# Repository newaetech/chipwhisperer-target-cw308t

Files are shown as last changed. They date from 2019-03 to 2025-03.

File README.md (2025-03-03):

# ChipWhisperer CW308 Targets #



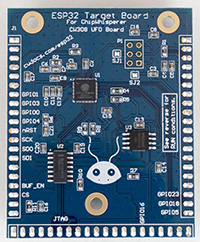
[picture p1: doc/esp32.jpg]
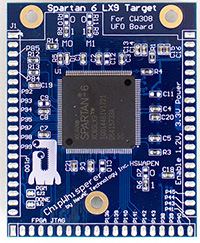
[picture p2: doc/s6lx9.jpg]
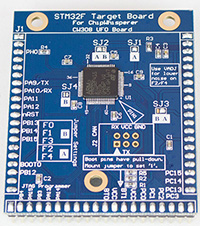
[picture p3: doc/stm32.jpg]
  

These are *targets* for the CW308 UFO Board. This repo contains gerbers, schematics, and source files (in Altium Designer format). Note **SOME BOARDS ARE UNTESTED**. All files are provided at your own risk. The CW308 UFO board is required for use (not part of this repo) as it supplies power, clock, programming headers etc:

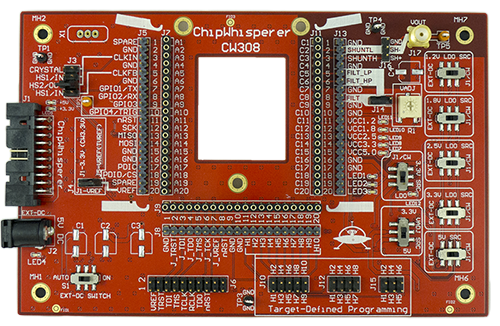
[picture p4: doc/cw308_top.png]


Many of these target boards (along with UFO baseboard) can be purchased assembled via Mouser Electronics. Note all targets are available however, so if you want some of the latest targets you may need to build one.

Most (all?) of these boards support the ChipWhisperer example applications. That means a basic HAL is provided in [chipwhisperer/firmware/mcu/hal](https://github.com/newaetech/chipwhisperer/tree/develop/firmware/mcu/hal) . Some of the more unique boards do not build as part of that system due to complexity of porting (i.e., ESP32).

## Documentation ##

The documentation in each directory (the markdown README.md file) is mirrored to the ChipWhisperer [main documentation page](https://chipwhisperer.readthedocs.io).
Some of the links in the markdown files here appear broken; they are written to
work for building the documentation site at
https://github.com/newaetech/chipwhisperer/tree/develop/docs, where this
repository is pulled in as a submodule.

## Using Boards ##

To use the boards, you will require the following at minimum:

* CW308 UFO Baseboard
* Analysis/injection device: either (1) ChipWhisperer-Lite Capture or ChipWhisperer-Pro, or (2) oscilloscope.

If NOT using ChipWhisperer-Lite/Pro which have built-in power supply, serial comms, and clock generator:

* USB-Serial adapter (3.3V)
* Crystal on UFO board (included w/ UFO board)
* 2.1mm DC power jack and 5V power supply

For most boards you will also require:
* External programming tool.

The STM32Fx boards, XMEGA, and AVR boards can all be programmed from the ChipWhisperer platform. All other boards will require an external programmer at this time.

### Suggested programmers ###

* For ARM targets anything with 20-pin JTAG header such as J-Link, OpenOCD, etc.
* For PowerPC targets a PEMicro USB Multilink
* For Tri-Core targets DAP miniWiggler V3
* For ESP32 you only need a USB-Serial cable
* Others (Si4010, D2000, etc) may have unique requirements.

## FAQs ##

**Q**: Do these boards work stand-alone?

**A**: No. These boards require a CW308 UFO Base-Board. In addition you may need an external programmer to load code on many of them.

--

**Q**: What's the difference between these and dev-boards?

**A**: These boards are purpose-built for side-channel analysis. As such they have a shunt resistor mounted, along with missing decoupling capacitors to allow clean power measurements. You can hack up dev-boards to achieve this, but these CW308T boards make it considerably easier to do so, along with high repeatability.

--

**Q:** Why are these boards so expensive when there is nothing on it? I can buy a dev-kit with JTAG and everything for the cost of some of these boards!

**A:** Dev-boards have low cost as are produced in huge quantity and minimal profit margin. Due to the unique nature of our boards we typically are producing QTY 25-200 per "run", and many of the ICs alone are rather expensive at that point. For example a STM32F407 @ Qty 40 is $12 USD, and the "discovery" board with that chip mounted is only $20!

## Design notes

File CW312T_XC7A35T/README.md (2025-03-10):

# CW312T-XC7A35

Xilinx Artix7 A35 Target for ChipWhisperer, with CW312 edge connector.

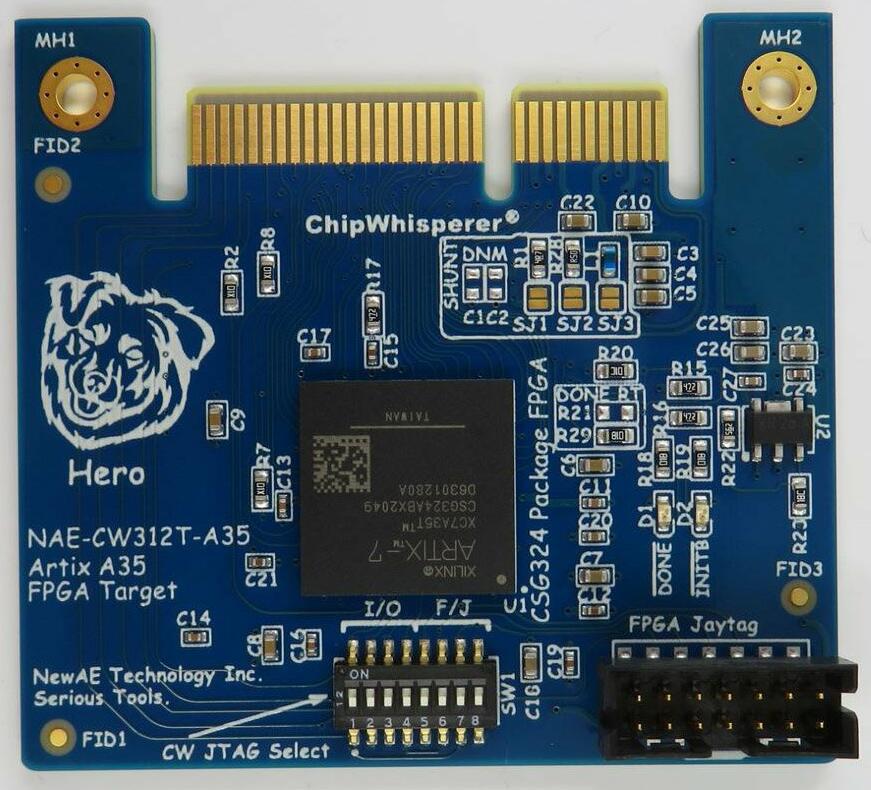
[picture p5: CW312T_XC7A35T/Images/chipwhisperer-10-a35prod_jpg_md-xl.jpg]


## JTAG Options
The target board has a Xilinx JTAG header (labeled "FPGA Jaytag" on the PCB)
which connects to the FPGA's JTAG port, for programming the FPGA via Xilinx
tools, or for using FPGA ILAs.

Additionally, the "CW JTAG Select" DIP switch provides some additional JTAG
routing options:
1. When switches 5-8 are "on", the JTAG header pins on the carrier CW313
   board (TDI, TDO, TMS, TCK) are routed to the FPGA's JTAG port.
2. When switches 1-4 are "on", the JTAG header pins on the carrier CW313
   board are routed to another set of FPGA pins (TDI, TDO, TMS, TCK to A11,
   C12, B11, B12 respectively), which allows connecting to e.g. a
   soft-core JTAG port.
Refer to the [schematic](#schematic) to see exactly how this is done.

## Shunt Selection
Because it's hard to have an optimal one-size-fits-all shunt for FPGA
targets, there are 3 shunts to choose from:

* 47 nH inductor

* 0.5 &Omega;

* 4.7 &Omega;

The active shunt is selected by a solder blob on SJ1, SJ2 or SJ3.

## Example Target Cores
The A35 target can run our example 
[AES](https://github.com/newaetech/chipwhisperer-jupyter/blob/master/demos/PA_HW_CW305_1-Attacking_AES_on_an_FPGA.ipynb), 
[pipelined AES](https://github.com/newaetech/chipwhisperer-jupyter/blob/master/demos/CW305_AES_pipelined.ipynb), and 
[ECC](https://github.com/newaetech/chipwhisperer-jupyter/tree/master/courses/sca204) 
cores. 

Pre-built bitfiles for all of these targets are included in the
ChipWhisperer repository, and can be explored via the notebooks (linked
above). To learn how to build these bitfiles yourself, head over to the
FPGA target area of the chipwhisperer repository
[here](https://github.com/newaetech/chipwhisperer/tree/develop/firmware/fpgas).

## Example Soft Cores
(ibex)=
### 1. Ibex
We also provide a bitfile for a pre-built 
[RISC-V Ibex core](https://github.com/lowRISC/ibex-demo-system).

To compile firmware for this target using our build infrastructure, set
`TARGET` to `CW312_IBEX`. This will pull in the 
[Ibex HAL](https://github.com/newaetech/chipwhisperer/tree/develop/firmware/mcu/hal/ibex).
Ensure you have a version of `riscv32-unknown-elf-gcc` [recommended by the
lowRISC project](https://github.com/lowRISC/lowrisc-toolchains/releases).
Then, compile target firmware 
[here](https://github.com/newaetech/chipwhisperer/tree/develop/firmware/mcu) 
as you would for any of our other targets.

Alternatively, you can also build target firmware from the 
[Ibex demo repository](https://github.com/lowRISC/ibex-demo-system#building-software)
following the Ibex methodology; there you will find our `simpleserial-aes` and
`basic-passwdcheck` firmware as examples.

After loading the FPGA bitfile (which can be done via the
[Setup\_Ibex.ipynb script](https://github.com/newaetech/chipwhisperer-jupyter/blob/master/Setup_Scripts/Setup_Ibex.ipynb), 
if using our pre-built bitfile), you'll need to program your target firmware
separately, using an external JTAG programmer connected to the A35's FPGA
JTAG port, *not the soft-core port* (e.g. connect your programmer
TDI/TDO/TCK/TMS to those header pins on the CW313 board, set DIP switches
5-8 to "on" on the A35 target board, and disconnect any other JTAG
programmer from the A35's "jaytag" header).

To program the firmware onto the FPGA soft-core, refer to the instructions
[here](https://github.com/lowRISC/ibex-demo-system#loading-an-application-to-the-programmed-fpga).
Those instructions run out-of-the-box on their default Arty FPGA platform;
you will likely need to modify their `load_demo_system.sh` script for your
own JTAG programmer.

Alternatively, you can avoid the firmware programming step by embedding your
target firmware into your FPGA bitfile; however, this requires you to build
the FPGA bitfile yourself (and re-building the bitfile every time you wish
to modify the firmware).

The pre-built Ibex core's UART link operates at 115200 baud when clocked at
100 MHz and is suitable for use with SimpleSerial v1 (the Ibex design
includes a PLL which expects a 100 MHz input clock; you can lower the clock
frequency and scale the baudrate accordingly, but only to a certain point
because the PLL will stop functioning correctly if the input clock frequency
is too far from 100 MHz).

### 2. Arm DesignStart
Look to our 
[Arm DesignStart repository](https://github.com/newaetech/CW305-Arm-DesignStart) 
for instructions on building and using a soft-core Arm Cortex target.

## Programming
The FPGA can be programmed with a Xilinx platform cable (or equivalent)
connected to the "Jaytag" port, as explained [above](#jtag-options).

It can also be programmed with a ChipWhisperer-Husky as follows:

```Python
import chipwhiserer as cw
scope = cw.scope()
from chipwhisperer.hardware.naeusb.programmer_targetfpga import CW312T_XC7A35T
fpga = CW312T_XC7A35T(scope)
fpga.program(<path-to-bitfile>, sck_speed=10e6)
```

When using our [example target cores and notebooks](#example-target-cores),
the notebooks automatically handle programming the correct bitfile for you
(via Husky).

## Schematic

The schematic is available
[here](https://github.com/newaetech/chipwhisperer-target-cw308t/blob/main/CW312T_XC7A35T/NAE-CW312T0XC7A35-04.PDF).

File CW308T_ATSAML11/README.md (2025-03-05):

# CW308T-ATSAML11

This board supports the Microchip ATSAML11 microcontroller.

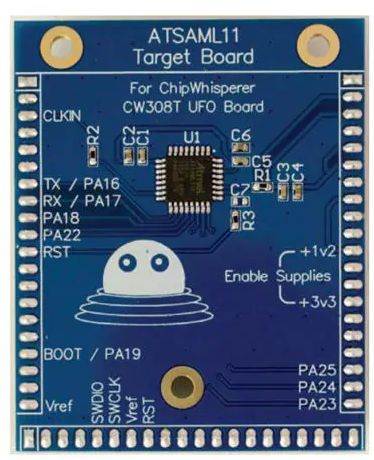
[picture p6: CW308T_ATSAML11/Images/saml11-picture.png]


## Specifications

| Feature | Notes/Range |
|---|---|
| Target Device | ATSAML11E16A |
| Target Architecture | Arm Cortex-M23 |
| Vcc | 1.2V |
| Programming | Serial Bootloader, SWD |
| Hardware Crypto | Accelerator |
| Availability | Standalone |
| Status | Released |
| Shunt | 22Ω |

Available from [Mouser](https://www.mouser.com/ProductDetail/NewAE/NAE-CW308T-ATSAML11?qs=PzGy0jfpSMuVApvEE0Yklw%3D%3D).

---

## Power Supply

The core of the SAML11 chip runs from a 1.2v supply. This is supplied
through the CW308T 1.2v regulator. The I/O busses are supplied with
3.3v.

---

## Security Features

The SAML11 platform integrates many advanced security features
including:

  - Up to four tamper pins for static and dynamic intrusion detections
  - Silent flash access for side channel attack resistance
  - Data scrambling with user-defined keys for both Flash and RAM
  - A True Random Number Generator

Since it's a Cortex-M23 core, it's also got Arm TrustZone-M.

For a full list of security features see the product family data
sheet[^1].

---

## Programming

The SAML10/11 family implements a serial bootloader. Usage of this
bootloader is not detailed in the data sheet, for usage information see
Microchip Application note AN2699[^2]. This bootloader doesn't have a
driver in ChipWhisperer, but one could be added.

Serial Wire Debug (SWD) is also supported for programming and debugging
applications.

---

## Schematic and Layout

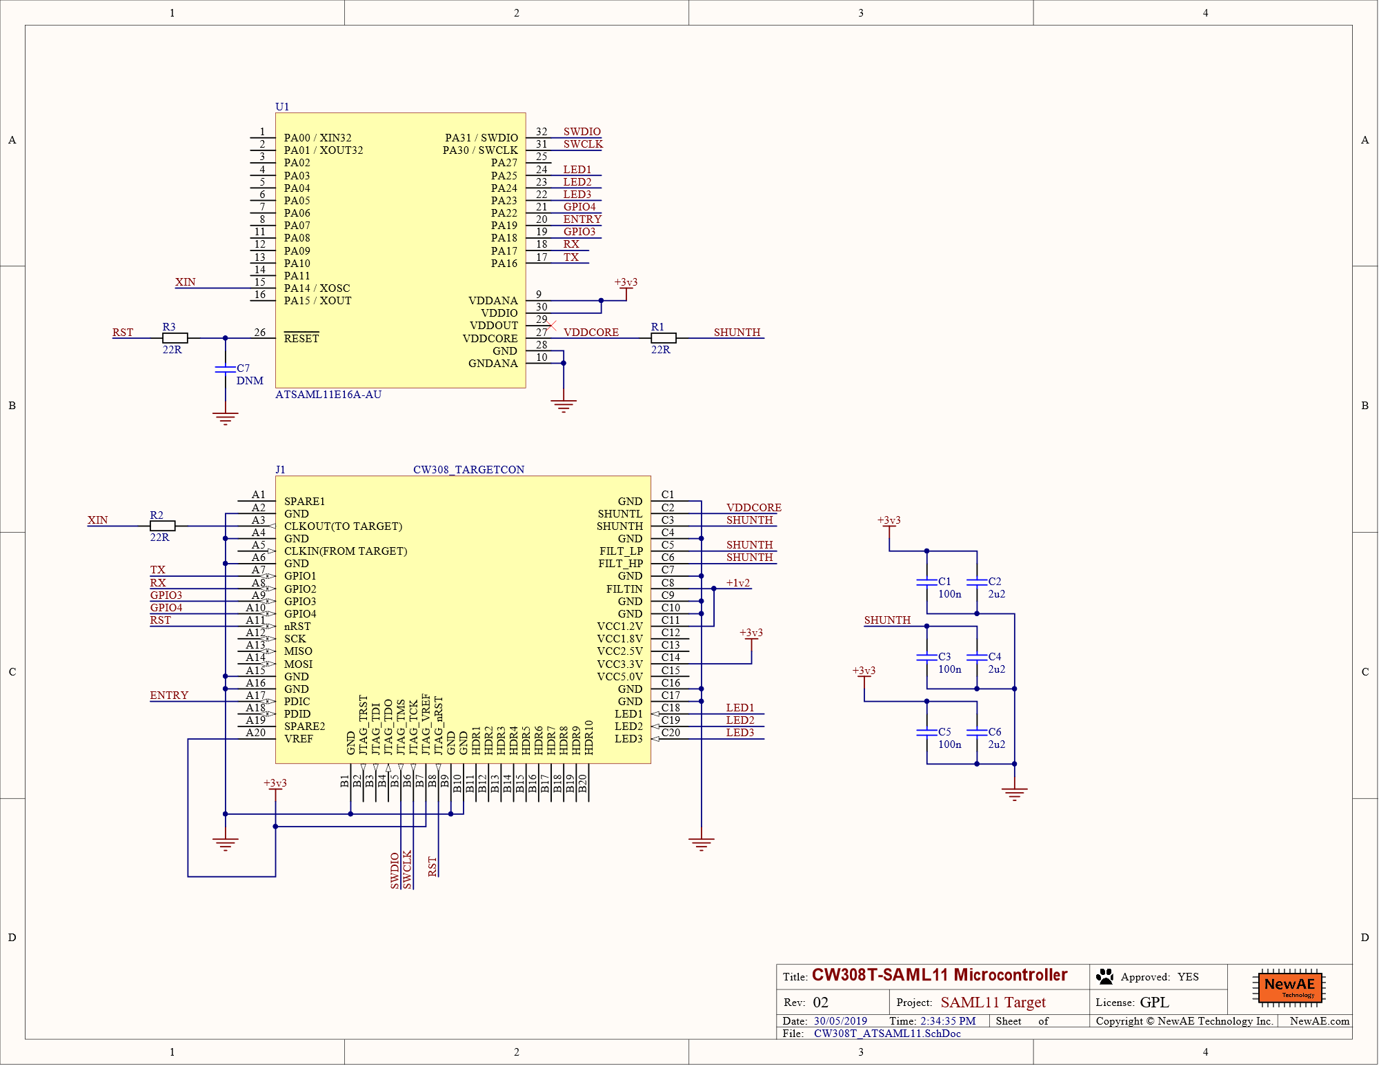
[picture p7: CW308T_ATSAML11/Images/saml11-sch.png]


[^1]:  <https://ww1.microchip.com/downloads/aemDocuments/documents/MCU32/ProductDocuments/DataSheets/SAM-L10-L11-Family-Data-Sheet-DS60001513.pdf>
[^2]:  <https://ww1.microchip.com/downloads/aemDocuments/documents/OTH/ApplicationNotes/ApplicationNotes/AN2699-UART-Bootloader-for-SAM-L10-L11-DS00002699B.pdf>

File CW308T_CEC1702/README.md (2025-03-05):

# CW308T-CEC1702

The CEC1702 is an embedded controller with strong cryptographic support,
customized for Internet of Things (IOT) platforms. The chip implements a
highly-configurable, mixed signal, advanced I/O controller architecture.
The device incorporates a 32-bit ARM Cortex M4F Microcontroller core
with closely-coupled SRAM for code and data. A secure bootloader is
used to download the custom firmware image from the system’s shared SPI
Flash device, thereby allowing system designers to customize the
device’s behavior[^1].

The CW308T-CEC1702 incorporates the main chip with a 16MB SPI flash chip
and a bi-directional SPI Buffer. The target board has standard power
monitoring, UART serial, and clock In/Out compatibility with the CW308.
JTAG pins and many GPIO pins are also exposed for prototyping and
testing use.

This device is interesting in that it has a lot of hardware crypto and
security functionality.

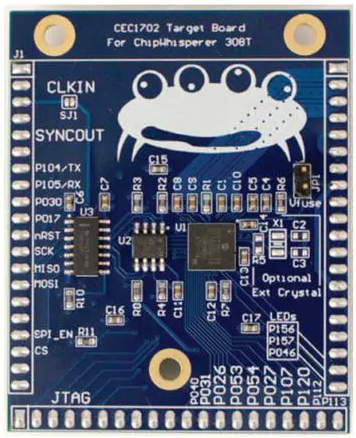
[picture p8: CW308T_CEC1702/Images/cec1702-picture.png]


---

## Specifications

| Feature | Notes/Range |
|---|---|
| Target Device | MCHP CEC1702 |
| Target Architecture | Arm Cortex M4F |
| Vcc | 3.3V |
| Programming | SPI Flash, JTAG (SRAM only) |
| Hardware Crypto | Yes |
| Availability | Standalone |
| Status | Released |
| Shunt | 10Ω |

Available from [Mouser](https://www.mouser.com/ProductDetail/NewAE/NAE-CW308T-CEC1702?qs=PzGy0jfpSMvD%2FsklzPsozg%3D%3D)

## I/O Connections

| **CW308 Pin** | **CEC1702 Pin** | **Function** |
| --- | --- | --- |
| GPIO1 | P104 (TXD0) | Serial OUTPUT from CEC1702 |
| GPIO2 | P105 (RXD0) | Serial INPUT to CEC1702 |
| GPIO3 | P030 | GPIO |
| GPIO4 | P017 | Trigger pin |
| CLKIN | XTAL2 | Optional CLKIN |
| CLKFB | P002 (PWM5) | Can output 12MHz PWM on this pin. Useful for synchronizing to internal oscillator |
| J\_TRST | JTAG\_RST | JTAG Reset |
| J\_TDI | JTAG\_TDI | JTAG TDI |
| J\_TDO | JTAG\_TDO | JTAG TDO |
| J\_TMS | JTAG\_TMS | JTAG TMS |
| J\_TCK | JTAG\_CLK | JTAG Clock |
| LED1 | P156 | GPIO, Breathing LED0 |
| LED2 | P157 | GPIO, Breathing LED1 |
| LED3 | PA7 | GPIO, LED |
| PDIC | | SPI buffer output enable, drive high to enable SPI programming and sniffing |
| PDID/CS | QSPI0\_CS | SPI chip select for SPI flash chip |
| H1 | P040 | GPIO |
| H2 | P031 | GPIO |
| H3 | P026 | GPIO |
| H4 | P053 | GPIO |
| H5 | P054 | GPIO |
| H6 | P027 | GPIO |
| H7 | P107 | GPIO |
| H8 | P120 | GPIO |
| H9 | P112 | GPIO |
| H10 | P113 | GPIO |

---

## Hardware Cryptography

### **Multi-purpose AES Cryptographic Engine**

\- Hardware support for ECB, CTR, CBC, and OFB AES modes

\- Support for 128-bit, 192-bit and 256-bit key length

\- DMA interface to SRAM, shared with Hash engine

### **Cryptographic Hash Engine**

\- Support for SHA-1, SHA-256, SHA-512

\- DMA interface to SRAM, shared with AES engine

### **Public Key Cryptographic Engine**

\- Hardware support for RSA and Elliptic Curve public key algorithms

\- RSA keys length from 1024 to 4096 bits

\- ECC Prime Field and Binary Field keys up to 640 bits

\- Microcoded support for standard public key algorithms

### **Other Cryptographic Features**

\- True Random Number Generator

\- 1 Kbit FIFO

\- Monotonic Counter

---

## Firmware

The firmware provided with Chipwhisperer (or its own repo) is designed
to work with the [MikroC PRO for ARM
IDE](http://www.mikroe.com/mikroc/arm). This IDE supports the many
peripherals of the CEC1702, including the hardware security features and
comes with extensive libraries and example code. The board layout has
been designed to be compatible with many of the provided examples, while
some others can be easily modified to work with the CW308T-CEC1702.
After the binaries have been created, they can either be loaded into SPI
Flash or directly into RAM via JTAG.

### **Creating and Modifying Examples**

The following notes may prove useful when using mikroC PRO examples or
creating your own:

  - Any example which uses UART1 needs to be changed to use UART0 by
    changing the UART1\_\* functions to UART0\_\*.
  - The plain text and encrypted text buffers need to be 16 byte aligned
    for the CEC1702's DMA to function properly. If the aes\_crypt() call
    fails or the encryption never completes, this may be the cause. See
    simpleserial\_base.c or mikroC PRO's AES examples for examples of
    this.
  - All variable declarations need to be done at the beginning of
    functions, before any variables are modified or functions are
    called.
  - The mikroC PRO compiler may have strange sizes for integer
    constants, meaning changing 4 8 bit numbers into a 32 bit number via
    bitshifts may not work as intended. Instead, using memcpy() may
    prove easier and more reliable.
  - When using mikroC PRO's "Clean Project Folder", ensure that .mcpar,
    .c, .h, and .xml files are not selected, as this will cause the
    source/project/Flash Center
  - The port base for use with the GPIO library is actually
    GPIO\_PORT\_xxx\_xxx, not \_GPIO\_PORT\_xxx\_xxx. Additionally, this
    is not a pointer, meaning the address of this variable needs to be
    passed to the gpio functions
  - There are no GPIO library functions to write or read from pins.
    Instead, use GPIO\_OUTPUT\_xxx\_xxx.Bn/GPIO\_INPUT\_xxx\_xxx.Bn for
    bit n of pin range xxx-xxx.

### **Compilation Settings**

**Project \> Edit Project**

Select CEC1702 in the MCU Name dropbox, change the MCU Clock Frequency
to 48MHz.

If you want to program and run off of the SPI flash, additional
configuration is needed:

**\> General Output Settings ...**

Make sure _**Generate BIN image file**_ is checked. Press OK on the
window and the previous edit project window.

**Build \> Build**

The messages dialog should indicate a successful build, and the image
binary (PROJECTNAME\_img.bin) and hex (PROJECTNAME.hex) can now be found
in the project output folder. To confirm correct build settings, check
the image binary using your SPI flash software or a HEX editor. The
image binary should begin with the 8 bytes **01 00 00 3E 01 00 00 3E**
at offset 000000, and the rest of the program should begin at offset 000100.

---

## Programming the Device

The CEC1702 supports loading code in two ways: from external flash
memory into RAM and directly into RAM over JTAG.

### **Programming the SPI Flash**

The [SST26VF016B](https://ww1.microchip.com/downloads/en/DeviceDoc/20005262D.pdf) flash chip on the target board can be programmed by an SPI programmer
attached to the SPI pins of the CW308. To program the chip, the nRST
chip must be pulled to ground by holding the nRST button down or by
connecting a jumper to J8 on the CW308. Additionally, the PDIC pin must
be driven high during the programming process to enable communication
through a buffer chip.

The [SST26VF016B](https://ww1.microchip.com/downloads/en/DeviceDoc/20005262D.pdf) flash chip uses global block protection that must be disabled before
every write operation. This is done by sending the command code **98**
to the chip before erasing or writing to the device. This can be done by
configuring a custom transaction in your flash programming software.
Below is a table of useful information for configuring your programming
software. The Parameters listed here have been tested with the Total
Phase Flash Center software and the Aardvark I<sup>2</sup>C/SPI Host
adapter. Additionally, a [Total Phase Flash Center](https://www.totalphase.com/products/flash-center/) script is
provided with the firmware for additional reference. See the
[SST26VF016B data
sheet](https://ww1.microchip.com/downloads/en/DeviceDoc/20005262D.pdf)
and the manual for your SPI flash program for more details.

| **Parameter** | **Value** |
| --- | --- |
| deviceName | SST26VF016B |
| deviceDescription | SST SST26VF016B 16 Megabyte SPI Flash |
| capacity | 16\*1024\*1024 |
| maxBitrate | 8\*1000 |
| addressWidth | 3 |
| eraseInstruction | 0x20 |
| eraseSize | 4\*1024 |
| eraseTime | 18000 |
| writeSize | 256 |
| writeTime | 64 |
| writeAutoAddressIncrementSize | 2 |
| writeAutoAddressIncrementTime | 10 |
| readDeviceIdInstruction | 0x9F |
| expectedDeviceId | \\xbf\\x26\\x41 |
| readInstruction | 0x03 |
| eraseAllInstruction | 0xC7 |
| eraseAllTime | 16000 |
| userTransaction1 | \\x98 |
| userTransaction1Time | 10000 |
| userTransaction1WriteEnable | false |

### **Programming over JTAG/SWD**

In addition to the SPI flash method, the CEC1702 can be temporarily
(until power off) programmed using a JTAG debugger. This has been tested
using Ozone V2.56d with a j-Trace Pro from Segger. The mikroC PRO IDE
also supports programming and debugging using the Segger.

Note that the CEC1702 only supports JTAG when the Debug Select bit (Byte
482 Bit\[6\]) of EFUSE is 0 and SWD when the Debug Select bit is 1. If
one does not work, try the other.

Load the image binary on to the flash chip and verify that the write was
performed. If verification fails, ensure the nRST pin was held low for
the entirety of the erase/write/verify cycle. If verification still
fails, refer to the data sheet and your programming software manual to
make sure the necessary command codes were sent in the appropriate
order.

### **Running the Program**

If you programmed the device via SPI flash, remove the nRST
jumper/release the nRST button and disconnect the 3.3V source from PDIC.
If you loaded your code from JTAG, hit go on your debugging software.

---

## Performing CPA Attacks

The CEC1702 has no option to run off on an external clock. To make CPA
attacks easier, a 12MHz PWM signal is generated on the CLKOUT pin. This
can be used by putting a jumper on the lower HS1/IN pins on J3 and
running the ChipWhisperer off of the ExtClk.

---

## ATE and EFUSE

The CEC1702 ships in ATE mode suppliers, which prevents booting off of
SPI flash and seems to mess with the UART baud rate (57600 baud
corresponded to 32000 baud). Note the CW308T-CEC1702 target boards have
this disabled as part of the production process / test procedure.

The device can be changed into normal mode by setting Byte 35 Bit\[7\]
of the EFUSE memory. This can be done via an external SPI flash such as
the mikroProg, or by loading a program that modifies the bits via JTAG.
For additional information, see the CEC1702 datasheet and errata. Before
modifying the EFUSE, keep the following in mind:

  - EFUSE bits are one time programmable (OTP) to 1. This means there's
    no way to set the bits back to 0 once they are set to 1.
  - To modify the EFUSE, VREF must be set to between 1.52V and 1.6V.
  - Make sure that FSOURCE\_EN\_READ and FSOURCE\_EN\_PRGM are never set
    to 1 at the same time, as this will short ground and power.
  - Note that both the EFUSE instructions in the CEC1702 datasheet and
    mikroC PRO's EFUSE program rely on VREF being set to ground while
    FSOURCE\_EN\_READ and FSOURCE\_EN\_PRGM are being switched. Instead,
    to modify the EFUSE, set both to 0, wait for the registers to be
    set, then set the appropriate bit.
  - Some additional features of the EFUSE include setting keys for flash
    decryption and authentication by the bootloader.

You can see an example program that works with the CW308T-CEC1702 device
at
[1](https://github.com/newaetech/chipwhisperer-target-cec1702)(https://github.com/newaetech/chipwhisperer-target-cec1702).
**NOTE: This firmware requires that integers are 32bits. Before building
this project, go to Project\>Edit Project and change Data Type Size to
"other (int 4 byte)"**

To use E-FUSE with the CW308T, you will need to use a jumper wire. To do
this:

  - Using a screwdriver, adjust VADJ trimmer to output 1.60V. Note you
    might need to switch the V-ADJ source voltage.
  - Jumper the VADJ output to the VFUSE header pin.

---

## Schematics

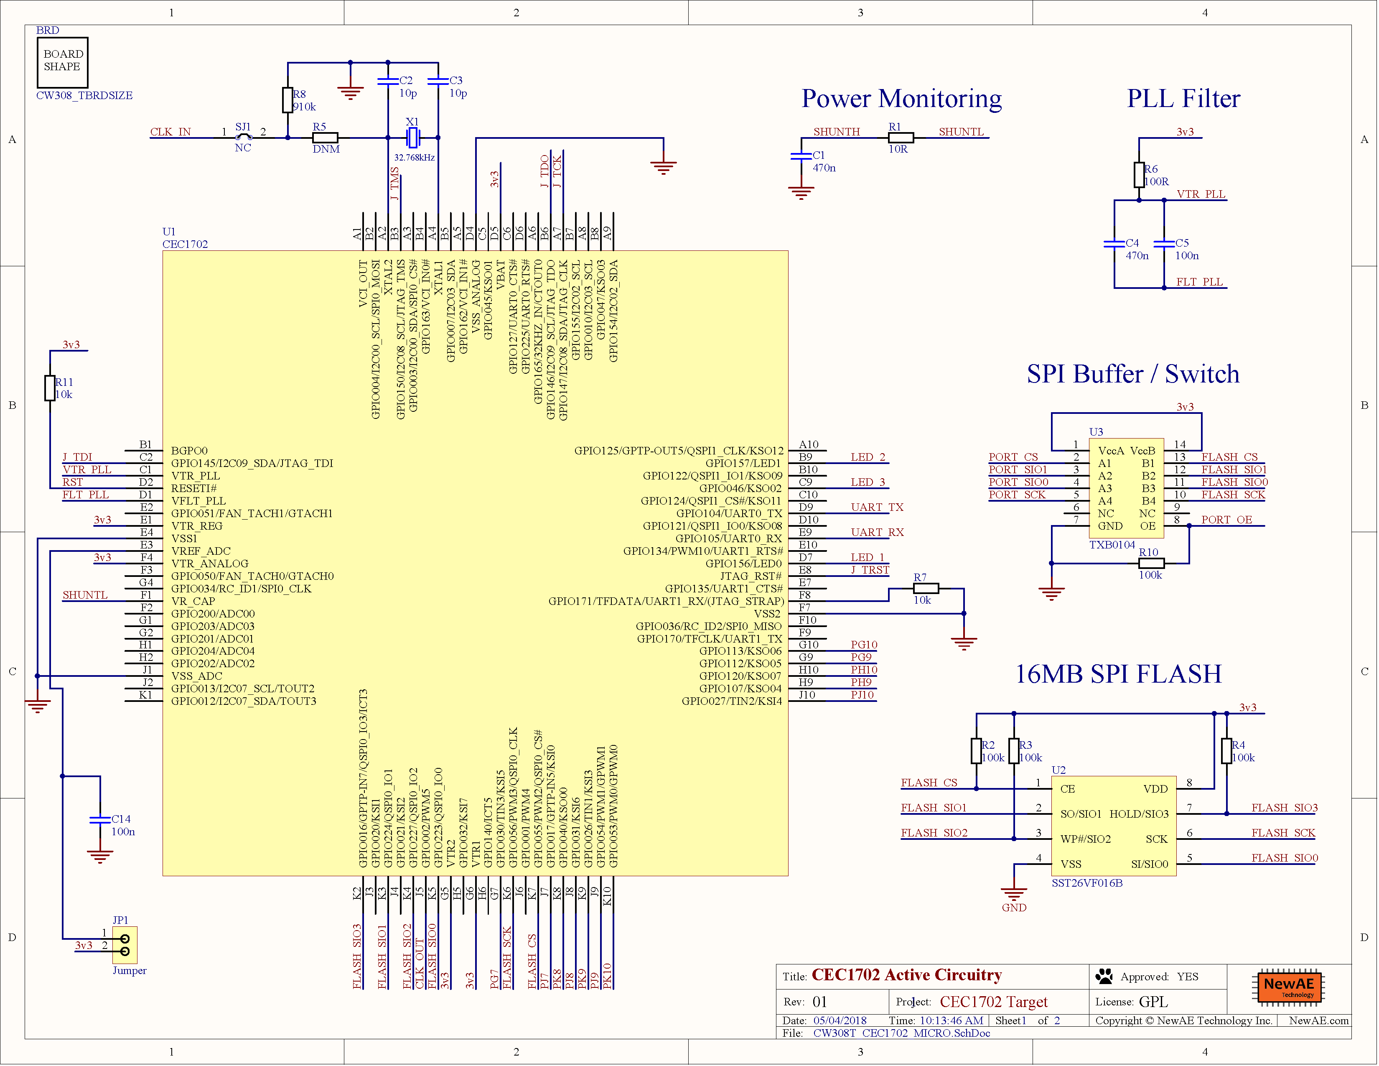
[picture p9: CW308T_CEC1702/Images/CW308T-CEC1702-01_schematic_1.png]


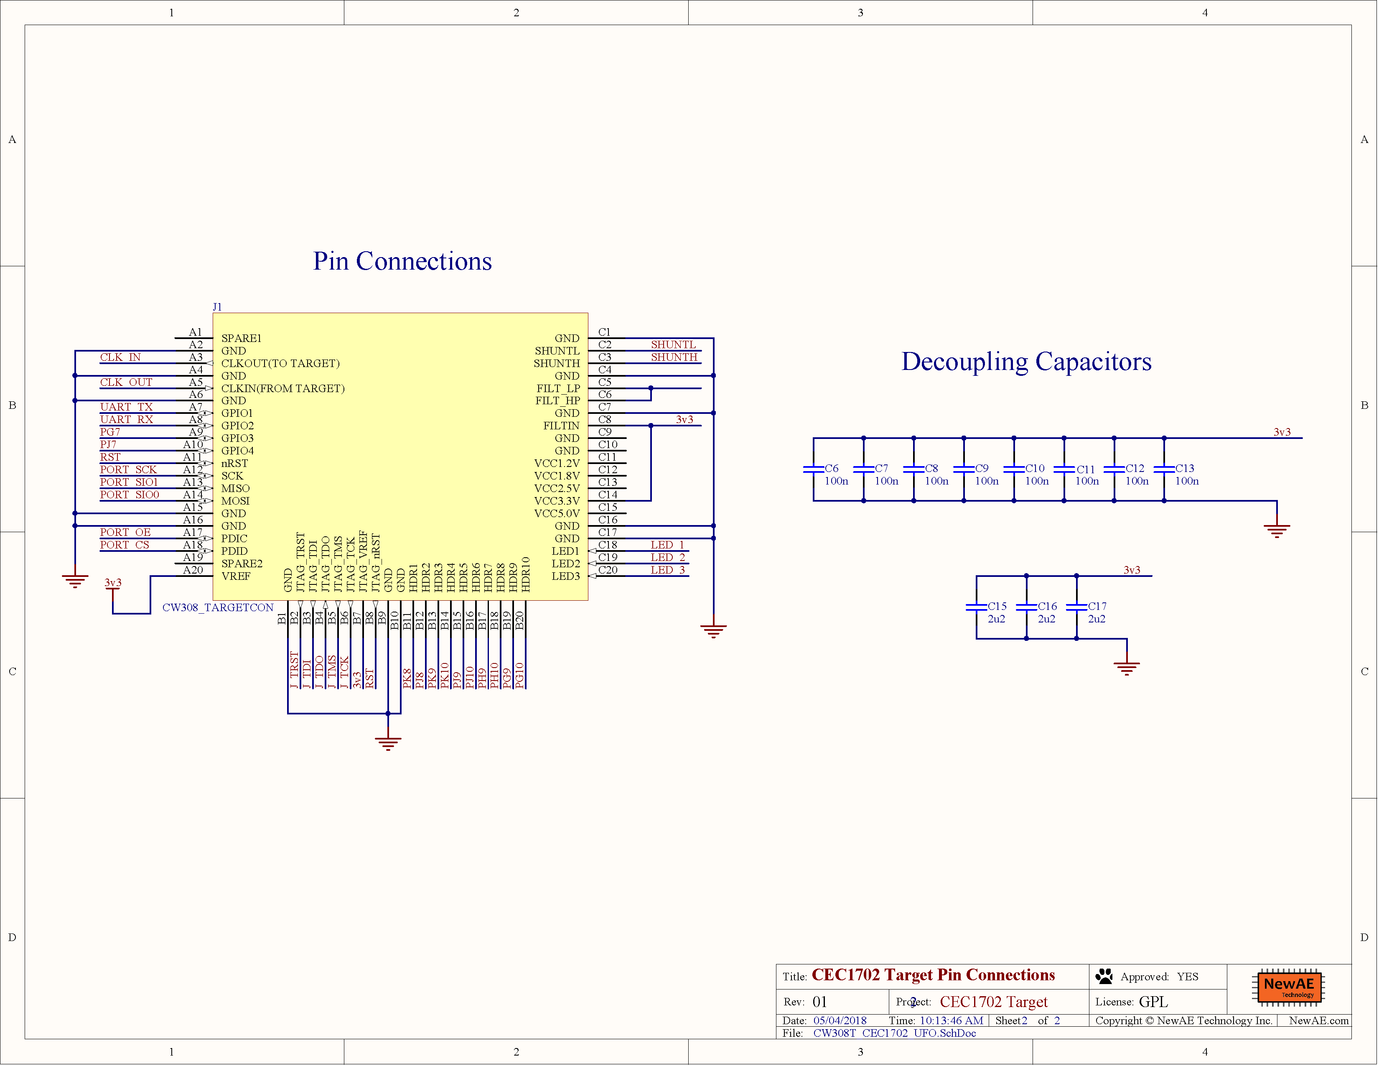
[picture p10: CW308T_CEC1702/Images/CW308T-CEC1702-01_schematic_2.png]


---

## Useful Links

  - [Microchip documents](https://www.microchip.com/en-us/product/cec1702)
  - [Aardvark I2C/SPI
    Programmer](https://www.totalphase.com/products/aardvark-i2cspi/)
  - [mikroC PRO for ARM IDE](http://www.mikroe.com/mikroc/arm)
  - [SST26VF016B Flash Datasheet](https://ww1.microchip.com/downloads/en/DeviceDoc/20005262D.pdf)

[^1]: <http://ww1.microchip.com/downloads/en/DeviceDoc/00002207B.pdf>

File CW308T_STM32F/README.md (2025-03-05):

# CW308T-STM32F

The CW308-STM32F board is the perfect target for testing fault injection against TQFP-64 STM32F/STM32L
microcontrollers. Thanks to pin compatibility (mostly) between various devices, this single board
supports multiple STM32F/STM32L microcontrollers.

These boards are also available complete with different STM32 devices

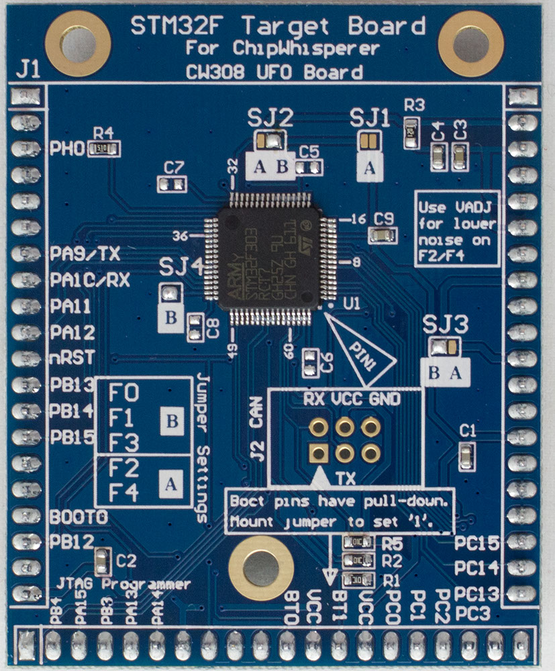
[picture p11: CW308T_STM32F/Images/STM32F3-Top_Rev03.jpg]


## Specifications

| Feature | Notes/Range |
|---|---|
| Target Device | STM32F |
| Target Architecture | Arm Cortex M0, M3, M4 |
| Hardware Crypto | Possible |
| Programmer | STM32F Serial Bootloader, JTAG, SWD |
| Availability | Starter kits, Standalone |
| Status | Released |

* STM32F0: available from [Mouser](https://www.mouser.com/ProductDetail/NewAE/NAE-CW308T-STM32F0?qs=r5DSvlrkXmIzFRGmD1EBXw%3D%3D) and the [NewAE Store](https://store.newae.com/stm32f0-target-for-cw308-arm-cortex-m0-128kb-flash-8kb-sram/)
* STM32F1: available from [Mouser](https://www.mouser.com/ProductDetail/NewAE/NAE-CW308T-STM32F1?qs=r5DSvlrkXmJcYbIax%2Fpjxw%3D%3D) and the [NewAE Store](https://store.newae.com/stm32f1-target-for-cw308-arm-cortex-m3-128kb-flash-8kb-sram/)
* STM32F2 w/Hardware Crypto: available from [Mouser](https://www.mouser.com/ProductDetail/NewAE/NAE-CW308T-STM32F2HWC?qs=r5DSvlrkXmJrfkJWQlIRng%3D%3D)
* STM32F3: available from [Mouser](https://www.mouser.com/ProductDetail/NewAE/NAE-CW308T-STM32F3?qs=r5DSvlrkXmKbi9gG3XxX8g%3D%3D) and the [NewAE Store](https://store.newae.com/stm32f3-target-for-cw308-arm-cortex-m4-256kb-flash-40kb-sram/)
    * Also available in a bundle with the [CANoodler](../../Tools/CANoodler.md) from [Mouser](https://www.mouser.com/ProductDetail/NewAE/NAE-CW308T-STM32F3AUTO?qs=r5DSvlrkXmJPqn%252BacawA8Q%3D%3D) and the [NewAE Store](https://store.newae.com/stm32f3-target-for-cw308-automotive-bundle-w-canoodler/)
* STM32F4 (no hardware crypto): available from [Mouser](https://www.mouser.com/ProductDetail/NewAE/NAE-CW308T-STM32F4?qs=r5DSvlrkXmKQ5HF2DzuSkA%3D%3D) and the [NewAE Store](https://store.newae.com/stm32f4-target-for-cw308-arm-cortex-m4-1mb-flash-192kb-sram/)
* STM32F4 w/Hardware Crypto: available from [Mouser](https://www.mouser.com/ProductDetail/NewAE/NAE-CW308T-STM32F4HWC?qs=r5DSvlrkXmLrgVVFt%252BpyiQ%3D%3D)
* STM32L4 w/Hardware Crypto: available from [Mouser](https://www.mouser.com/ProductDetail/NewAE/NAE-CW308T-STM32L4?qs=OlC7AqGiEDlCVULataTd0w%3D%3D)

* The blank PCB is also available from [Mouser](https://www.mouser.com/ProductDetail/NewAE/NPCB-CW308T-STM32F-04?qs=r5DSvlrkXmKb3e62axJWHA%3D%3D) and the [NewAE Store](https://store.newae.com/blank-pcb-stm32fx-cw308-target/)

---

## Supported Devices

The STM32F board supports several STM32F devices in the TQFP-64 package.
Various solder jumpers need to bet set to either the "A" or "B" position
to select appropriate VCC supply for the different series. The following
table summarizes examples of suitable devices:

| **STM32F Series** | **Package** | **Device** | **Hardware AES** | **Tested** | **Jumper** | **Flash** | **SRAM**  | **NAE P/N** |
| --- | --- | --- | --- | --- | --- | ----- | ----- | --- |
| F0 | TQFP-64 | STM32F071RBT6  | No | Yes | B | 128KB | 16KB  | NAE-CW308T-STM32F0 |
| F1 | TQFP-64 | STM32F100RBT6B | No | Yes | B | 128KB | 8KB | NAE-CW308T-STM32F1 |
| F2 | TQFP-64 | STM32F215RET6  | Yes | Yes | A | 512KB | 132KB | NAE-CW308T-STM32F2HWC |
| F3 | TQFP-64 | STM32F303RCT7  | No | Yes | B | 256KB | 40KB  | NAE-CW308T-STM32F3 |
| F4 | TQFP-64 | STM32F415RGT6  | Yes | Yes | A | 1MB | 192KB | NAE-CW308T-STM32F4HWC |
| F4 | TQFP-64 | STM32F405RGT6  | No | Yes | A | 1MB | 192KB | NAE-CW308T-STM32F4 |
| L4 | TQFP-64 | STM32L443RCT6  | Yes | Yes | B | 256KB | 64KB  | NAE-CW308T-STM32L4 (this version has hardware crypto) |
| L5 | TQFP-64 | STM32L562RET6  | Yes | Yes | B | 512KB | 256KB | NAE-CW308T-STM32L5HWC |

### **VCC-Int Supply**

Several devices (F2, F4) have internal core voltage regulators. By
default the CW308 board attempts to provide power for these pins, but
the voltage may not be high enough to cause the internal regulator to
disable itself. In this case you can use the VADJ regulator to ensure
the internal regulator is disabled. See 
[Targets with Internal Regulators](../../cw_tips_tricks/advanced_usage/regulators.md)
for details.

### **Pin-outs across TQFP Devices**

The following shows differences in pinouts between three groups of
devices. The left-most is the STM32F051RB, which uses the same 3.3V
VCORE as the STM32F1/F3. It has fewer VCC pins, so the I/O occupying
that are VCC/GND pins on the STM32F1 (such as PF6/PF7) are tied to
GND/VCC. The right-most part is the pinout of the STM32F2/F4. It has an
internal regulator, where the VCAP pins are the output of this regulator
(and input to the internal core logic).

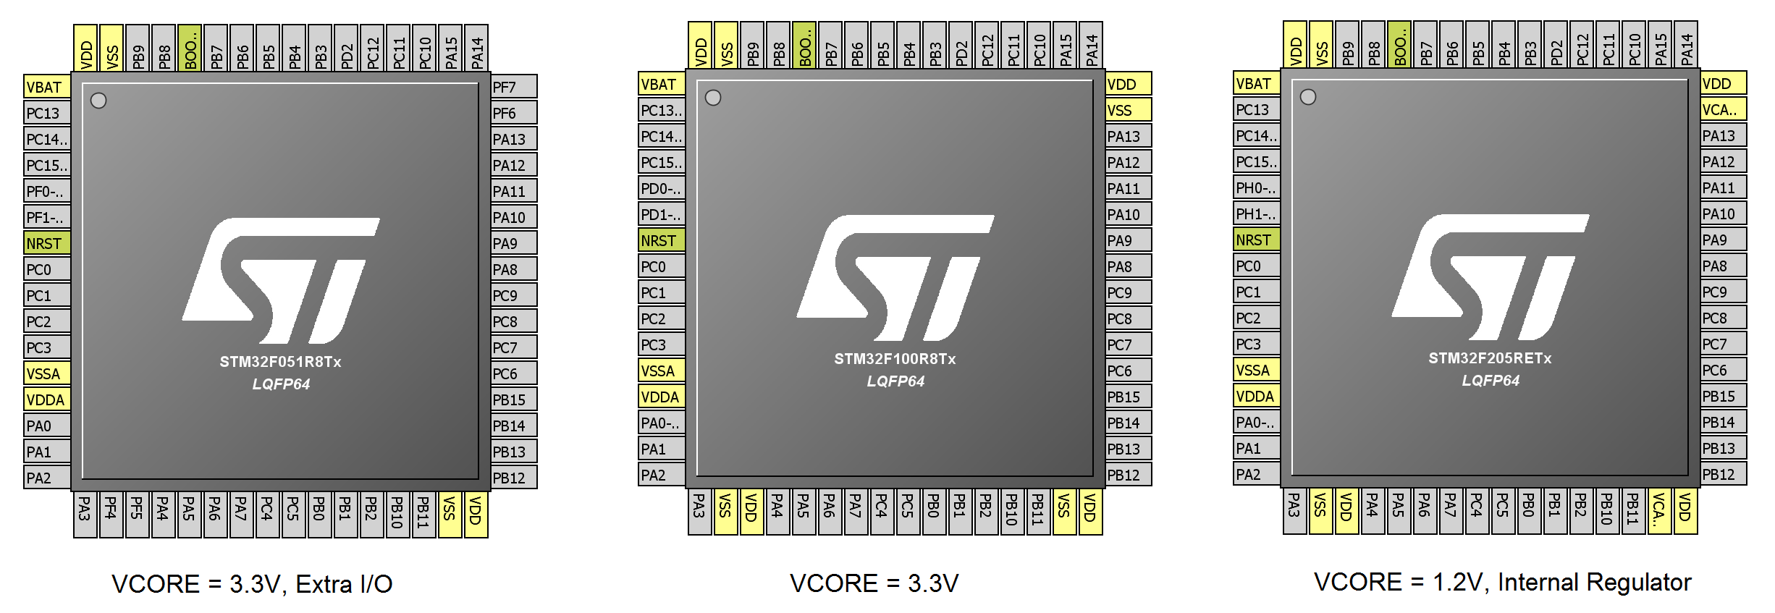
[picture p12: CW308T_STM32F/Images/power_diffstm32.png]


Note for the devices with a 3.3V VCORE, you should not mount decoupling
capacitors C5/C6/C7/C8. You will still get some leakage with those
capacitors mounted, but a stronger signal is present without them.

---

## Hardware AES

The STM32F21x, and STM32F41x/43x have hardware crypto modules (AES, DES,
TDES) along with hardware hash (SHA1, MD5). Hardware crypto for the
STM32F4 has been integrated into the Hal build system on the develop
branch. To use the hardware crypto, call HW_AES128_Init() at the
beginning of your program. You can update the key with
HW_AES128_LoadKey(), encrypt plaintext with HW_AES128_Enc(), and
decrypt data with HW_AES128_Dec().

---

## Internal Clock

The STM32Fx build system is also setup to work off of the internal clock instead of an external one.
To enable this mode, build with `MCU_CLK=INT`. Note that the code still assumes that the device is clocked at 7.37MHz,
so the communication baud rate will be changed by a factor of `INT_CLK/7.37MHz`. For example, the F3's internal clock
runs at 8MHz, so you should use a baud rate of `8/7.37 * SIMPLESERIAL_BAUD`.

## CAN Connection

A 6-pin header is present for devices which have CAN hardware support
(not all devices have this). A CANoodler can be plugged in to provide
the physical transceiver. This header is not normally mounted, unless
the board is part of an 'automotive bundle'. The header is left
unmounted as it can impede sweeping a probe over the surface of the
chip.

---

## Programming Connection

### **ChipWhisperer Programmer via Bootloader**

See further down this page for details.

### **JTAG Programmer**

The 20-pin JTAG port (J6 on CW308 Board) can be used with the
[ST-LINK/V2](https://www.digikey.com/product-detail/en/stmicroelectronics/ST-LINK-V2/497-10484-ND/2214535)
which is a low-cost JTAG programmer.

It is also possible to use other JTAG programmers such as OpenOCD. The
following command worked with an Olimex OpenOCD programmer and their
[OpenOCD for
Windows](https://www.olimex.com/Products/ARM/JTAG/ARM-USB-OCD-H/)
software:

    openocd
      -f path/to/board/files/cw308.cfg
      -c init
      -c targets
      -c "halt"
      -c "flash write_image erase path/to/firmware.hex"
      -c "verify_image path/to/firmware.hex"
      -c "reset run"
      -c shutdown

where the contents of `cw308.cfg` are

    source [find interface/olimex-arm-usb-ocd-h.cfg]
    source [find target/stm32f4x.cfg]
    reset_config srst_only

---

## Example Projects

SimpleSerial builds for each of the STM32Fx Devices. Each device is a
separate HAL. These HAL modules have been copied from ST's HAL (not the
CUBE) and greatly reduced in size by deleting unused files (such as
headers for unused devices), and combining several C-source files into a
single low-level C-file.

Many example projects are available via Jupyter Notebooks:
<https://chipwhisperer.readthedocs.io/en/latest/tutorials.html>. Note
that all of these examples were created for the CWLITEARM (equivalent
STM32F3) target. You will need to make changes based on which target you
have to run the tutorials. For some tutorials, changing the PLATFORM
variable in the first block to the one you're using is enough to get the
tutorial working:

``` python
SCOPETYPE = "OPENADC"
PLATFORM = "CW308_STM32F4" #For STM32F4 target, was originally "CWLITEARM"
```

### **Building ST Example on Command Line**

The regular firmware build process works with the STM32 devices. For
example, to build \`simpleserial-aes\`, navigate to the folder
\`chipwhisperer\\firmware\\mcu\\simpleserial-aes\` and run
the following command on the command line:

`make PLATFORM=CW308_STM32F0 CRYPTO_TARGET=TINYAES128C`

If all goes well, this command will finish by printing the output file
size and the platform:

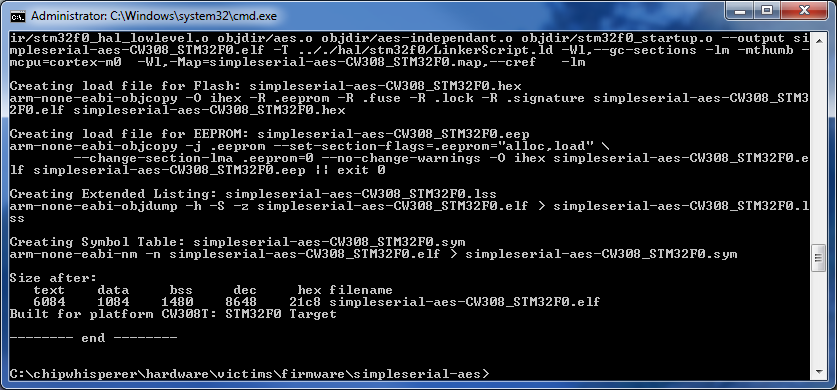
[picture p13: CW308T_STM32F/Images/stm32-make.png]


### **Programming via ChipWhisperer Bootloader**

The STM32Fx devices have a built-in bootloader, and the ChipWhisperer
software as of 3.5.2 includes support for this bootloader.

Important notes before we begin:

  - You MUST setup a clock and the serial lines for the chip. This is
    easily done by connecting to the scope and target, then running
    `default_setup()`:

<!-- end list -->

``` python
import chipwhisperer as cw
scope = cw.scope
target = cw.target(scope)
scope.default_setup()
```

  - On the STM32F1, you MUST adjust the clock frequency to 8MHz. The
    bootloader does not work with our usual 7.37 MHz clock frequency.
    **This 8MHz frequency does not apply to the code that you're running
    on the device. Once you're done programming, you'll need to set the
    frequency back to F\_CPU (likely 7.37MHz)** For example:

<!-- end list -->

``` python
scope.default_setup()
scope.clock.clkgen_freq = 8E6
#program target...
scope.clock.clkgen_freq = 7.37E6
#reset and run as usual
```

To access the bootloader you can perform these steps. They vary based on
if you have a "Rev 02" board or a "Rev 03 or Later" board. The revision
number is printed on the bottom side as part of the PCB part number
(STM32F-03 is Rev -03 for example).

#### **Rev -03 or Later**

Run the following python code once you have the scope and target set up:

``` python
prog = cw.programmers.STM32FProgrammer
cw.program_target(scope, prog, "<path to fw hex file>")
```

If you get errors during the programming process:

  - Retry the programming process with a lower baud rate:

<!-- end list -->

``` python
prog = cw.programmers.STM32FProgrammer
cw.program_target(scope, prog, "<path to fw hex file>", baud=38400)
```

  - If using a CW308 based STM, try mounting a jumper between the "SH-"
    and "SH+" pins at J16 (to the left of the SMA connector) on the UFO
    board. Retry programming with the jumper mounted.

---

#### Rev -02 Boards

The Rev -02 boards did not have all programming connections present.
They require some additional steps:

\# Setup the device as usual:

``` python
scope = cw.scope()
target = cw.target(scope)
scope.default_setup()
```

1.  Mount a jumper between the H1 and PDIC pins (again this is ONLY for
    the -02 rev).
      -
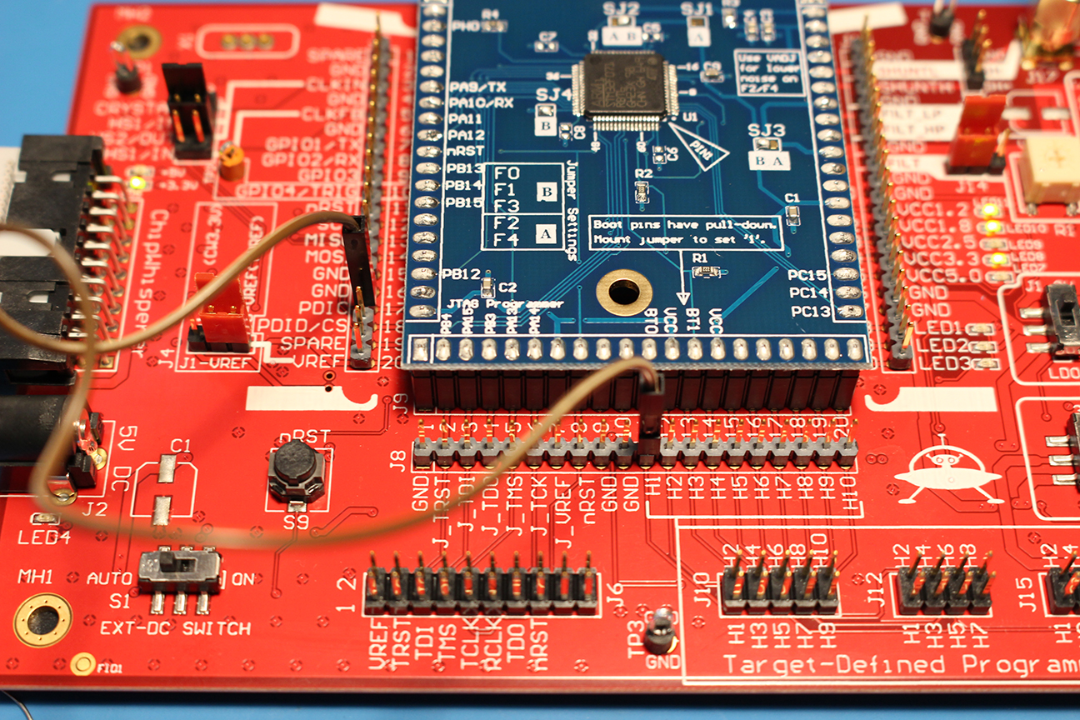
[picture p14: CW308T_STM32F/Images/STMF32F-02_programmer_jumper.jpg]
        

\# Reset the ARM device either by pressing the reset button (newer UFO
boards only), or by toggling power:

``` python
import time
scope.io.target_pwr = False
time.sleep(1)
scope.io.target_pwr = True
```

\# Program the device:

``` python
prog = cw.programmers.STM32FProgrammer
cw.program_target(scope, prog, "<path to fw hex file>")
```

1.  The device should program, it may take a moment to fully
    program/verify on larger devices.
2.  Remove the jumper between the H1/H2 pins.

\# Reset the ARM device either by pressing the reset button (newer UFO
boards only), or by toggling power:

``` python
import time
scope.io.target_pwr = False
time.sleep(1)
scope.io.target_pwr = True
```
---

### **Running ST Example with ST-Link**

If instead of using the bootloader, you want to use a ST-Link you can
instead plug your programmer into the 20 pin JTAG connector (J6 on the
UFO board):

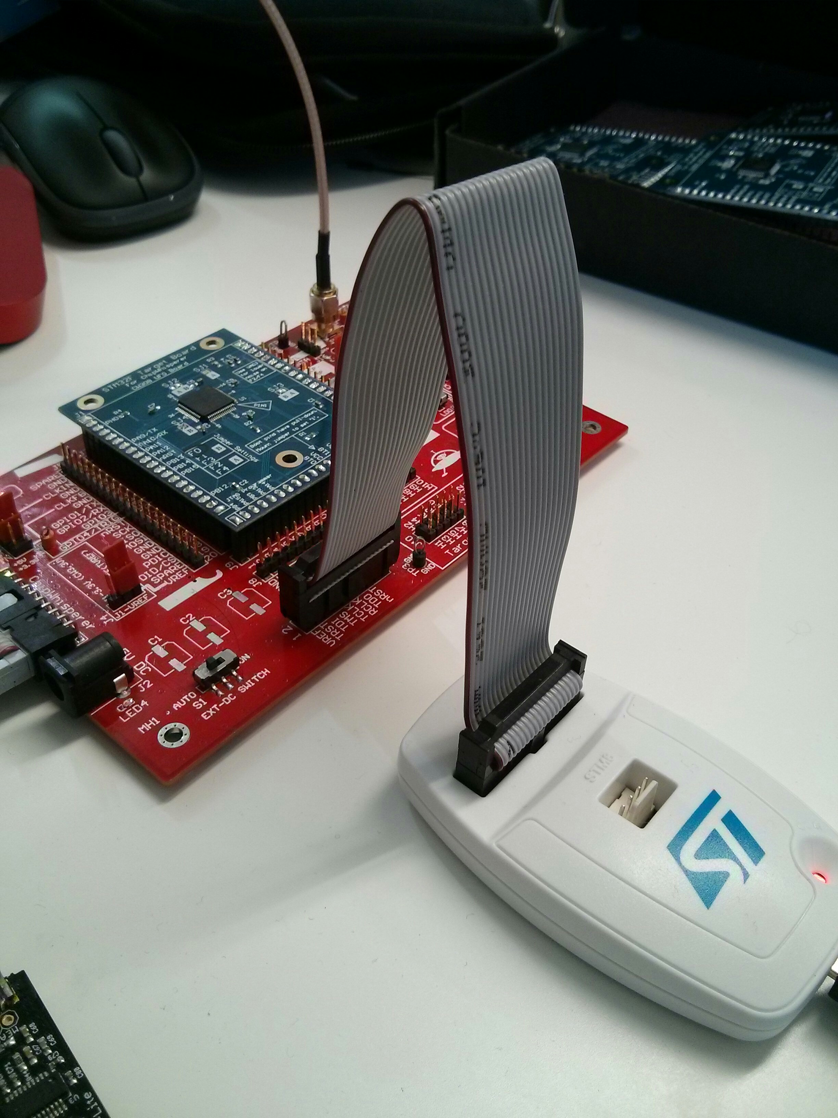
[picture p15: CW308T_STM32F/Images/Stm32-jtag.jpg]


Then, the details of this step will depend on your programmer. If you're
using an ST-Link programmer, open the ST-Link utility and connect to the
device:

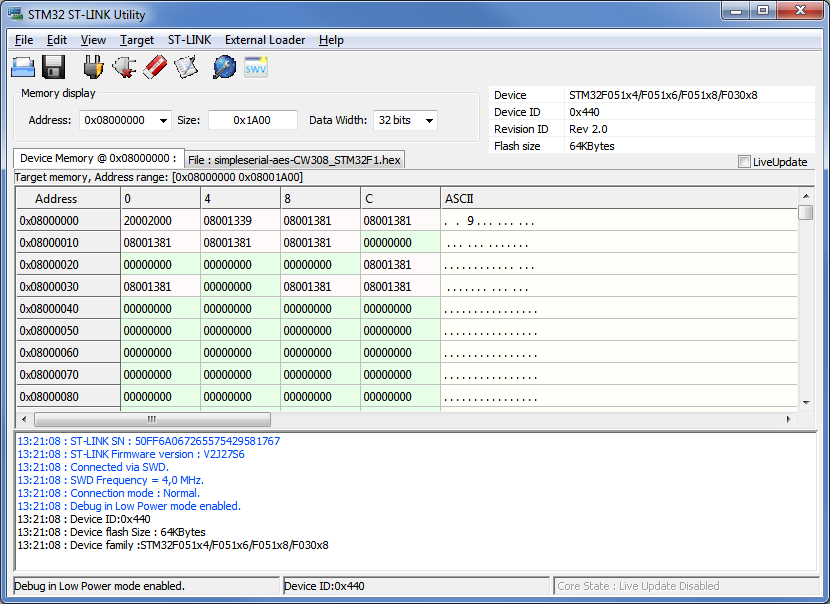
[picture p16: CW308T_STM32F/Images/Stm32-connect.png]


Load your \`.hex\` file and program the device with the Program and
Verify button:

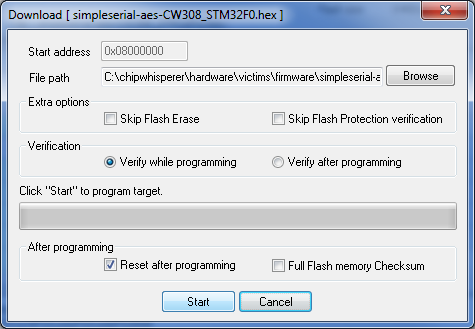
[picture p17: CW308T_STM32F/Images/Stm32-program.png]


After this, you're ready to go - you can use the ChipWhisperer terminal
to talk to your target. You might need to reset the target before you do
anything else.

### **Building and Debugging via ST's System Workbench**

It's also possible to work on the example projects using [ST's System
Workbench IDE](http://www.st.com/en/development-tools/sw4stm32.html).
This IDE also supports debugging, which is helpful for working out all
the kinks in your firmware.

To build the ChipWhisperer examples in System Workbench:

1\. Create a new Mcu project by going to *File \> New \> C Project* and
selecting *'*Ac6 STM32 MCU Project*'.* When you get to Target
Configuration, click the Mcu tab and select the microcontroller that you
want to target:

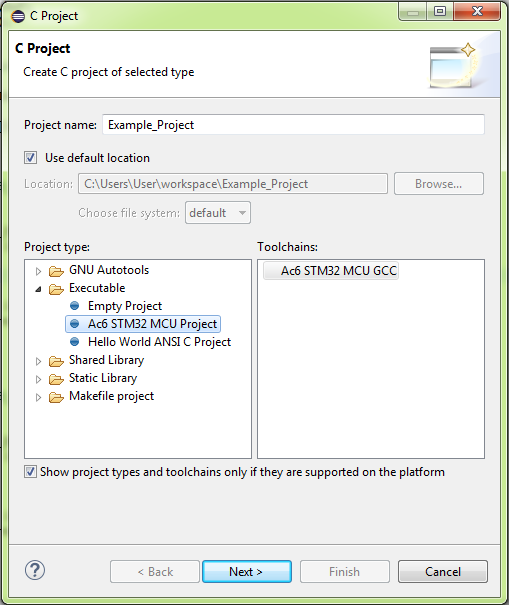
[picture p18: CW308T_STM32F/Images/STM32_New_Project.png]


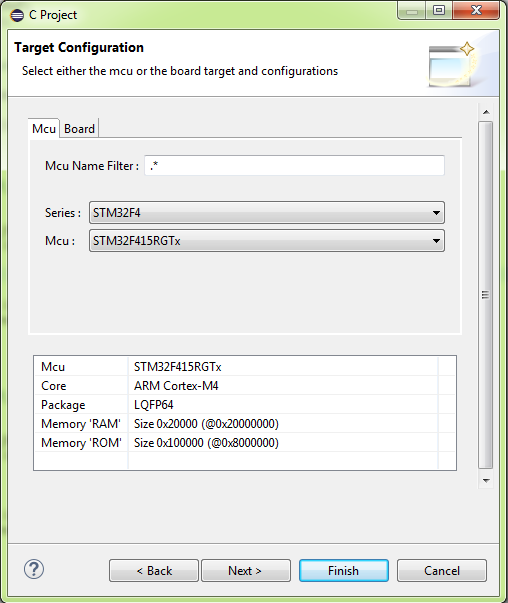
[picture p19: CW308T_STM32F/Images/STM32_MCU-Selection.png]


2\. Link the external files into the project. To do this, under *File \>
Import*, select *File System*. In the
\`chipwhisperer\\firmware\\mcu\` directory, select all of
the relevant files and folders (Makefile in base folder, Makefile in HAL
folder, STM32Fx HAL folder).:

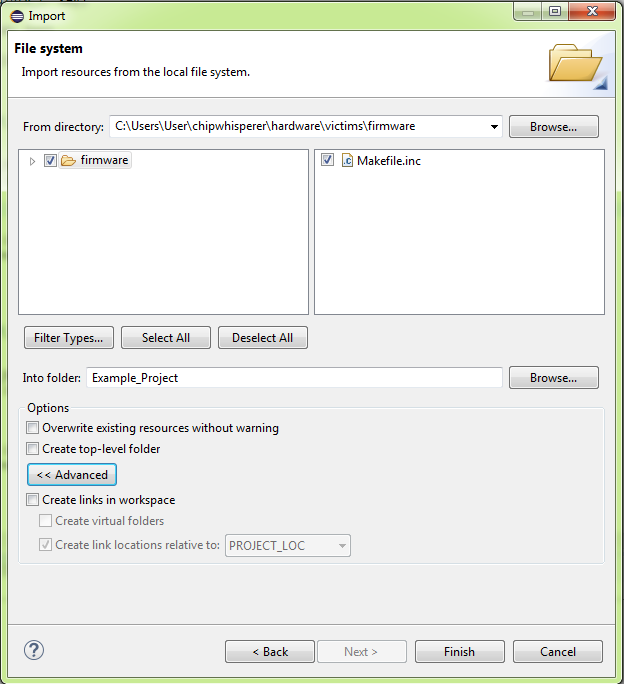
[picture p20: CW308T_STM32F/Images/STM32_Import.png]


3\. Set up the build command. In *File \> Properties*, go to *C/C++
Build \> Behavior* and remove 'all**' from 'Build' and deselect 'Enable
parallel build'. Next, click the *Builder Settings* tab and deselect
'Use default build command' and 'Generate Makefiles Automatically'.
Enter the command you would normally enter on the command line and
change 'Build directory' to the folder you want to build in:

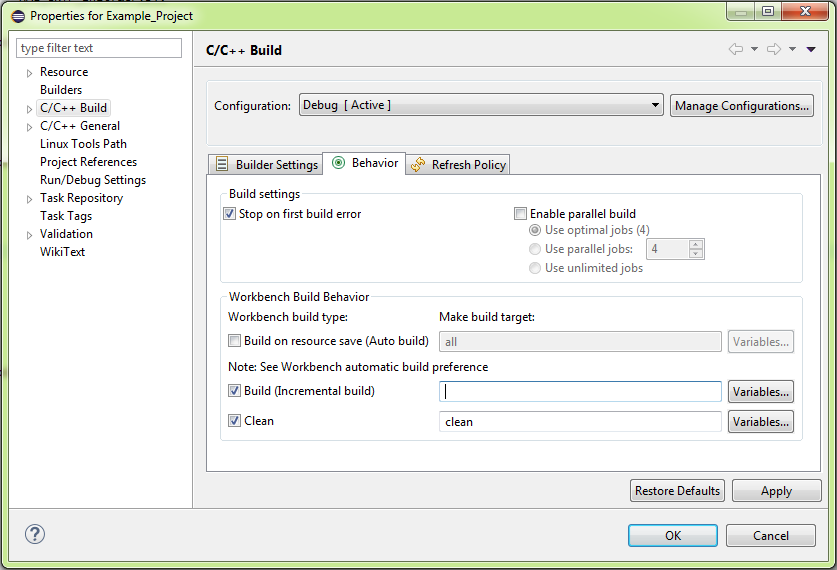
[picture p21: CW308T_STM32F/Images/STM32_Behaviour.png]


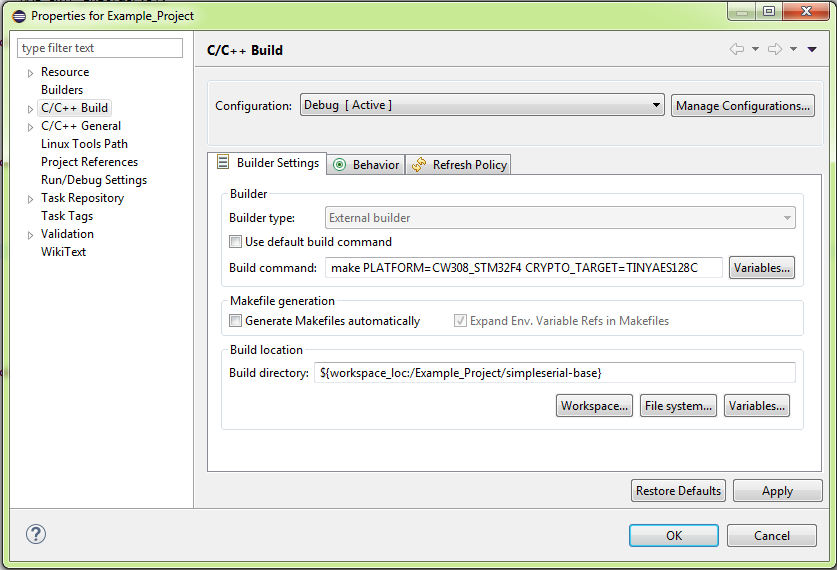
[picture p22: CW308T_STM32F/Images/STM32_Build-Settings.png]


4\. Build the project and confirm that the build works from the output
in the IDE console.

Then, if you want to set up debugging:

1\. Go to *in File \> Properties* select Run/Debug Settings and create a
new debug configuration. Under Debugger, click 'Show generator
options...' and setup your Connection Setup based on your debugger.
Change 'Reset Mode' to 'Software System reset':

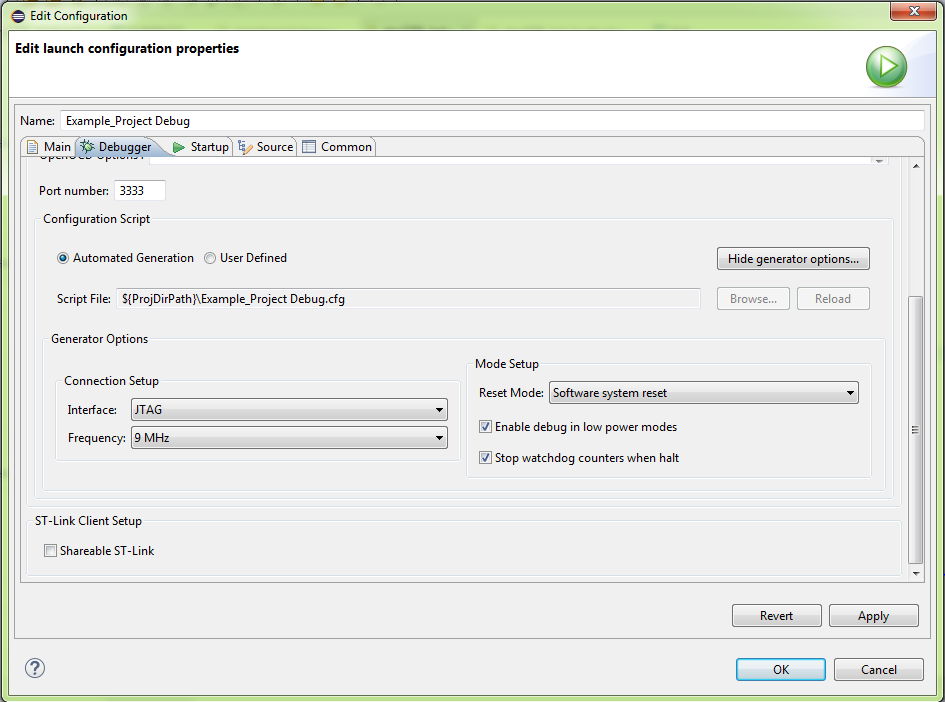
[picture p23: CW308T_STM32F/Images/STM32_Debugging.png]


2\. Click Apply and enter debugging mode.

**Caveat**: the I/O register map in the debugger appears to use the last
known device (ie: if you debugged an STM32F4 project before your
Makefile project, it sticks with F4's registers). Check that the
registers' addresses are correct before you trust them\!

---

## Schematic

The following variants are possible, see the table above for
SRAM/FLASH/HW-Crypto status:

| Variant | U1 | R3 (VCC-Shunt) | R4 (Clock) |
| --- | --- | --- | --- |
| F0 | STM32F071RBT6 | 33-ohm | 120-ohm |
| F1 | STM32F100RBT6 | 22-ohm | 51-ohm |
| F2HWC | STM32F215RET6 | 10-ohm | 51-ohm |
| F3 | STM32F303RCT7 | 12-ohm | 51-ohm |
| F4 | STM32F405RGT6 | 10-ohm | 51-ohm |
| F4HWC | STM32F415RGT6 | 10-ohm | 51-ohm |

### **Rev -03 Schematic**

The current revision of the target is -03. The following shows this
schematic:

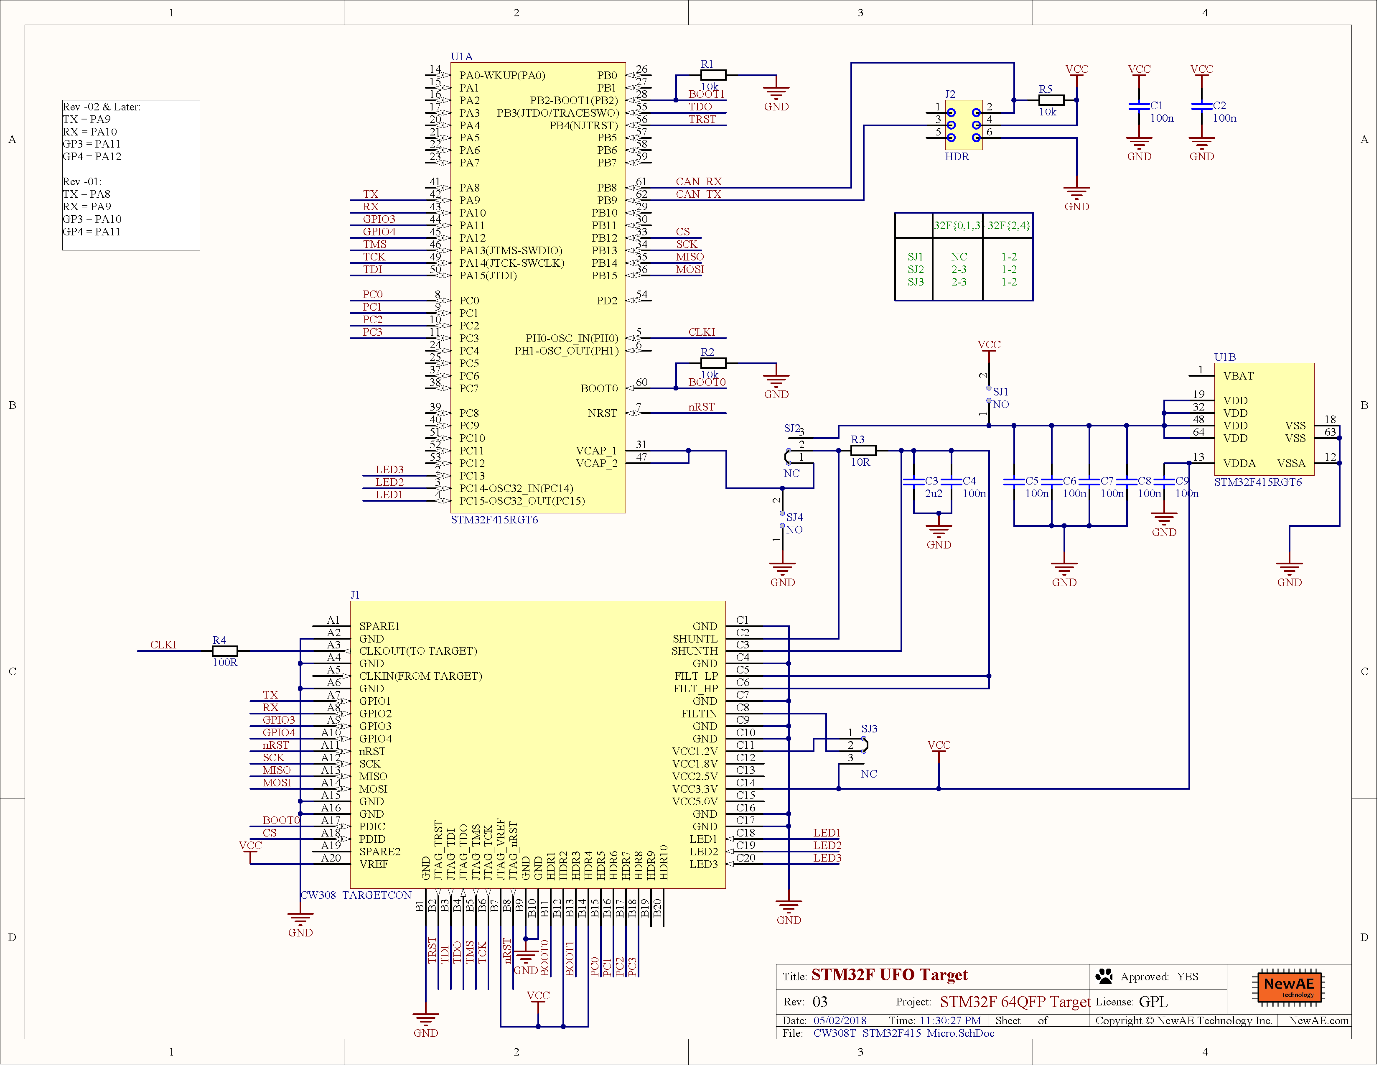
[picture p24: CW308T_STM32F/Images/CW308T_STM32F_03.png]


### **Rev -02 Schematic**

The original board sold was the -02 revision. The revision is part of
the part number, for example these boards will be marked STM32F-02. The
-02 revision also does not have the CAN connector:
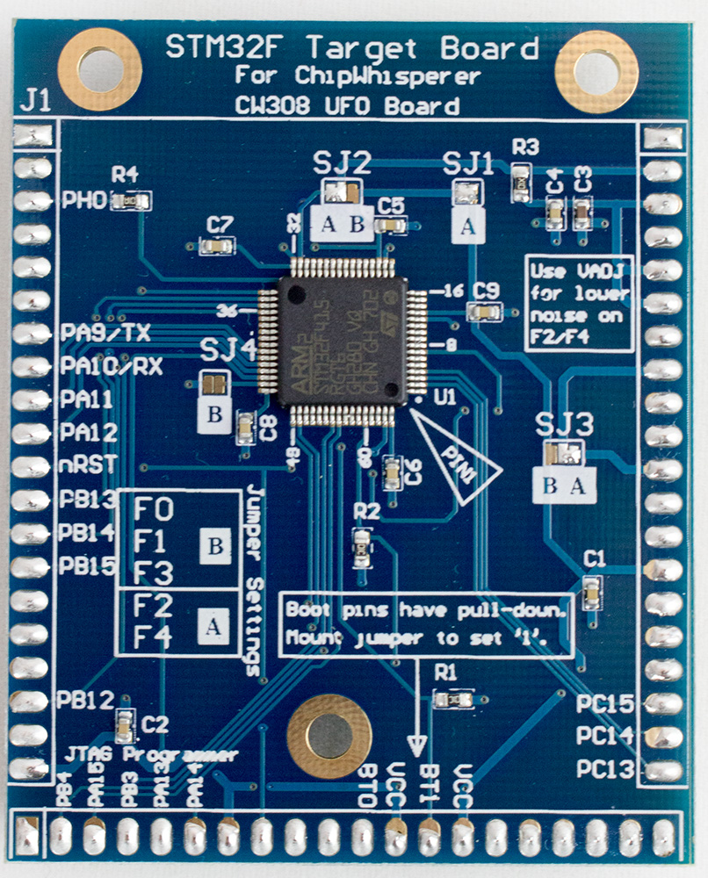
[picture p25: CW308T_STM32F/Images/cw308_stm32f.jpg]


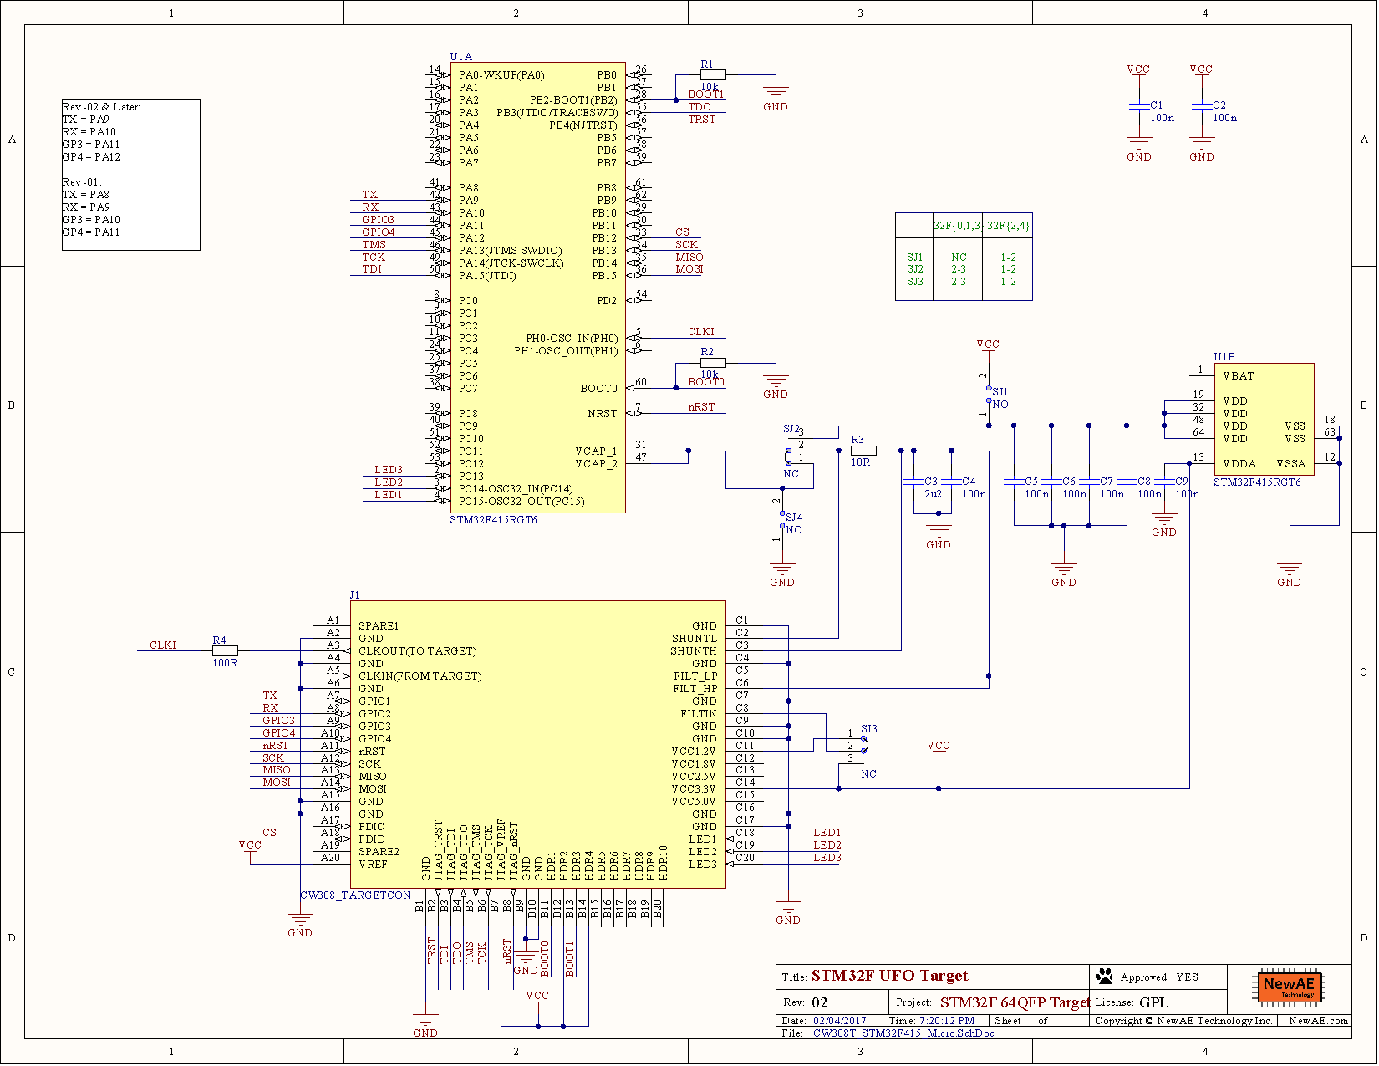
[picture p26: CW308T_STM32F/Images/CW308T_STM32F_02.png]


## Errata

### STM32 Parts Differences

Due to part availability, some boards may come with slightly different microcontrollers
(typically a larger internal flash and/or SRAM) which may have different hardware optimizations. 
This won't affect most attacks, but may affect template attacks across devices. For example, a template generated for an STM32F303RCT7 may not work on an STM32F303RDT6 and vice versa.

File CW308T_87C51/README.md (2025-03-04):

# CW308T-87C51

The 87C51 target is designed for a line of 8051 processors made by Intel
in PLCC44 package, although other manufactures make equivalent devices
as well (notably NXP as well). This target board allows for two types of
side channel attacks:

1.  Regular power analysis or glitching on the 87C51 firmware (ex: attacking an AES key while the 87C51 performs AES encryption)

2.  Attacks on the verification process in order to bypass the device's encryption table or security fuses

This page describes the setup of the 87C51 target and shows how it can
be used to perform these two types of attacks.

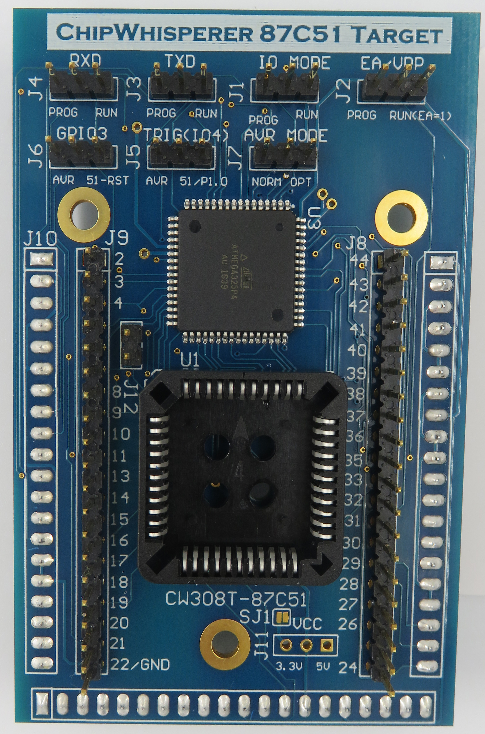
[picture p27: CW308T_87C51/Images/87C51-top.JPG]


---

## Specifications

| Feature | Notes/Range |
|---|---|
| Target Device | 8xC51 |
| Target Architecture | 8-bit 8051 |
| Vcc | 3.3V |
| Programming | Preprogrammed, not reprogrammable |
| Hardware Crypto | No |
| Availability | Standalone |
| Status | Released |
| Shunt | 51Ω |

Available from [Mouser](https://www.mouser.com/ProductDetail/NewAE/NAE-CW308T-87C51?qs=r5DSvlrkXmJ64F4k9ZvzhA%3D%3D)
and the [NewAE Store](https://store.newae.com/87c51-cw308-target-plcc44-package/)

## Hardware Details

### **Programming Microcontroller**

The target board contains an ATMega165PA/ATMega325PA (referred to as the
'AVR' hereafter), which can be used for performing program verification.
It is also used to generate trigger points for attacks such as
encryption table read-out & inserting glitches into the program read
logic. The programming interface contains the following limitations:

  - No programming is possible as there is no VPP generation.

  - Address lines A0 - A13 are mapped to the AVR. The upper two lines are shared with LED1/LED2 outputs. (A14 and A15 aren't needed because the 87C51 model that's used only has 16 KB = 2^14 bytes of memory.)

### **Target Microcontroller**

The default target device is an Intel EE87C51RB1 (16K EPROM, 512 RAM).
Useful references:

  - [Intel 8xC51RA,RB,RC
    Datasheet](http://media.digikey.com/pdf/Data%20Sheets/Intel%20PDFs/8xC51RA,RB,RC.pdf)
  - [NXP 8XC51RA+/RB+
    Datasheet](https://www.nxp.com/docs/en/data-sheet/8XC51_8XC52.pdf)

NOTE: The Intel datasheet is fairly short (20 pages) and does not
include full details of the programming. This can be found in the NXP
datasheet.

There are 2 20-pin headers on the top side of the board connected to the
pins of the 87C51. If you're keeping track, the remaining 4 pins are
labelled NC - they aren't used internally, so all of the functional pins
are broken out to these headers. These headers make it easier to connect
an oscilloscope or logic analyzer to the target.

**NOTE:** The 87C51 devices are either EPROM memories. Some may have a
UV window but some don't, those without the UV window are OTP devices.
You may wish to use a 89C51 device instead in some cases. See note below
about 89C51 devices.

#### _Using 89C51 Devices_

The 89C51 devices are also possible to be used with this board, which
can be more easily reprogrammed. The 89C51 devices do not normally have
the "XOR encryption table" however, so you cannot attempt attacks on
that encryption table.

### **Jumpers**

A number of jumpers are present on the target board. They are mostly
used to select different features and options on the target board.
First, there are 7 jumpers that connect to the IO lines of the two
microcontrollers

  - **IO MODE (J1):** Selects if the AVR is enabled or not. When the
    board is powered on, if this is set to "RUN", the AVR will enter
    sleep mode until the power is cut. If it is set to "PROG", the AVR
    will continue executing its program.
  - **EA/VPP (J2):** Selects the 8051's EA pin connection. In "PROG"
    mode, the AVR has control of this pin; in "RUN" mode, it is always
    set to 1. This is necessary to allow the 8051 to execute code from
    internal EPROM memory.
  - **TXD (J3):** Connects the Target IO2 line (Serial TXD) to one of
    the chips. In "PROG" mode, this is connected to AVR PE1. In "RUN"
    mode, it is connected to 8051 P3.1.
  - **RXD (J4):** Connects the Target IO1 line (Serial RXD) to one of
    the chips. In "PROG" mode, this is connected to AVR PE0. In "RUN"
    mode, it is connected to 8051 P3.0.
  - **GPIO4 (J5):** Connects the Target IO4 line to AVR PE3 ("AVR" mode)
    or 8051 P1.0 ("51/P1.0" mode). This line is intended to be used as a
    trigger, so firmware on the 8051 and AVR can cause a trigger by
    toggling these wires.
  - **GPIO3 (J6):** Connects the Target IO3 line to AVR PE5 ("AVR" mode)
    or 8051 RESET ("51-RST" mode). In the former, the AVR has control
    over the 8051's reset line. In the latter, the 8051 uses an
    active-high reset, so the device runs when GPIO3 is set low.
  - **AVR MODE (J7):** Connects to AVR PE4. This is normally pulled up
    to VCC. With a jumper connected in "OPT" mode, this is set low.

Then, there are two jumpers that control the power and clock signals:

  - **VCC (J11):** Connects to the board's VCC rails. This can be
    connected to the baseboard's 5V rail or to one of the 3.3V regulator
    outputs. Be cautious with this - in particular, the ChipWhisperer
    Lite does NOT have 5V tolerant IO lines\!
  - **J12:** When J12 is not connected, the AVR runs on its own 7.37 MHz
    crystal. With J12 connected, the AVR's clock line is connected to
    CLKIN signal, which is also the 8051's clock line. Connecting the
    clock signals is useful for ensuring that the devices are
    synchronized, but it also causes any glitched clock signals to be
    routed to AVR.

Finally, the baseboard's "Target-Defined Programming" header (J15) is
connected to some of the 8051 pins. P3.3, P3.4, and P3.5 are connected
to H2, H4, and H6. Normally, these pins are all pulled down to ground
(logic 0). When a jumper is mounted to H1-H2, H3-H4, or H5-H6, these
pins are instead connected to VCC (logic 1).

---

## AVR Firmware

The AVR on the target board has its own firmware to control the 87C51
code verification process. This firmware is one Atmel Studio project in
the Git repository. The compiled hex file can be programmed onto the AVR
using the AVR Programmer in the capture software.

If you have a target board that's never been programmed before, the AVR
fuses will need to be programmed from their default values. A [fuse
calculator](http://www.engbedded.com/fusecalc/) is helpful here. The
fuses should be written to:

  - Low fuse: `0xED`
  - High fuse: `0x99`
  - Ext fuse: `0xFF`

To program these, the AVR programmer will have to use Slow Clock Mode.
Once these fuses are set, slow clock mode can be disabled again.

---

## 87C51 Firmware

### **Developing Firmware for the 87C51**

There are a number of tools that can be used to develop firmware for the
87C51 processor. The best 8051-specific software can be pretty
expensive, but it is possible to get by with free software:

**Compiler:** The [SDCC](http://sdcc.sourceforge.net/) (Small Device C
Compiler) is a compiler that is made for devices with limited amounts of
memory. It can be used to compile code specifically for a number of
targets, including the 8051 line of processors. A few of the useful
flags are:

  - `-mmcs51`: Compile code specifically for an MCS51 target
  - `--iram-size [size]`: Specify that the device has `[size]` bytes of
    internal RAM
  - `--xram-size [size]`: Same as above, but for external RAM
  - `--code-size [size]`: Same as above, but for code memory (EPROM)
  - `--out-fmt-ihx`: Produce an Intel HEX file as the output of the
    linking stage
  - `--stack-auto`: Put all automatic variables on the stack, rather
    than storing a specific location in RAM for them. This can be a huge
    RAM saver\!

Note that SDCC has [not completely
implemented](https://sourceforge.net/p/sdcc/wiki/Standard%20Compliance/)
the ISO C99/C11 standards. One very noticeable change is that SDCC does
not allow variables declarations to be intermingled with code. That is,
the following will not compile:

    void func()
    {
        int x = 1; // OK
        x += 2;    // OK
        int y = x; // syntax error: token -> 'int'
    }

**Simulator**: The 87C51 is one-time programmable, so it is extremely
helpful to have a simulator to test firmware before burning it onto a
physical processor. There are very few free simulators for the 8051
core. One free sim is [EdSim51](http://www.edsim51.com/). This program
can load a hex file and run the code one step at a time. There are a few
big issues:

  - The simulator has no way of translating your compiled binary file
    back into C. This means that the debugging process is a bit blind -
    moving through the program one line at a time isn't particularly
    helpful because one line of C will typically be many lines of
    assembly. It's still possible to debug code by printing variables,
    but this leaves something to be desired.
  - EdSim51 is designed for an 8051 core with 128 B of RAM. This means
    that you cannot simulate any programs that use more than 128 B of
    RAM. However, this is enough space for a lot of tasks - our full
    piece of firmware does AES over SimpleSerial in this much space\!

**Programmer**: To write a program into the code EPROM, an EPROM
programmer is needed. We used a MiniPro TL866
programmer along with
their free software. However, any programmer compatible with the 87C51
should be fine.

### **Example Firmware**

We've written a couple of firmware examples and put them together into
one big 87C51 project. Combining multiple pieces of code together means
that we can use one chip for all of the side channel attacks - we don't
need separate processors to work on different pieces of firmware. This
project has six different parts:

  - `print`: prints "Testing 1\\nTesting 2\\nTesting 3...". Easy to
    confirm that the processor is running correctly.
  - `passcheck`: waits for the user to enter a password and checks
    whether it is correct. The correct password is
    "[Tr0ub4dor&3\\r](http://xkcd.com/936/)".
  - `glitchloop`: calculates 200 \* 200 using a very long and tedious
    loop. Inserting a successful glitch will corrupt this result.
  - `xor`: implements the SimpleSerial protocol with 128 bit key and
    plaintexts. The response is the XOR of the plaintext and key.
  - `aes`: implements SimpleSerial with AES-128 encryption (128 bit key
    and plaintext)
  - `tea`: implements SimpleSerial with TEA encryption (256 bit key and
    128 bit plaintext)

When the 87C51 is powered on, it reads the state of the Target-Defined
Programming header J15 to decide which mode to run in. In the following
table, a Y means that the jumper is mounted, and an N means that no
jumper is mounted:

| **H5-H6** | **H3-H4** | **H1-H2** | **Mode** |
| --- | --- | --- | --- |
| N | N | N | Print |
| N | N | Y | Password check |
| N | Y | N | Glitch loop |
| N | Y | Y | XOR |
| Y | N | N | AES |
| Y | N | Y | TEA |
| Y | Y | N | — |
| Y | Y | Y | — |

---

## Code Verification

### **Verification Process**

The process to read back code from the 87C51's EPROM memory is described
in the NXP datasheet (in the EPROM Characteristics section). However,
there's a lot of info in this section about *writing* to the EPROM
memory, which we can't do on the target board. The bare minimum to
verify code bytes is repeated here:

1\. Set the following levels on these pins:

| **Pin**  | **Level** |
| --- | --- |
| RST | 1 |
| P3.6 | 1 |
| P3.7 | 1 |
| EA/VPP | 1 |
| ALE/PROG | 1 |
| PSEN | 0 |
| P2.6 | 0 |
| P2.7 | 1 |

2\. Write the 16 bit address to the following pins:

| **Pin** | **Address** |
| --- | --- |
| P1.0-P1.7 | A0-A7 |
| P2.0-P2.5 | A8-A13 |
| P3.4 | A14 |
| P3.5 | A15 |

Note that the 87C51 that we've used for this project only has 16 KB of
memory, so addresses over 0x3FFF are meaningless (ie: A14 and A15 have
no purpose).

3\. Write P2.7 to 0 to begin the read. Wait at least 48 clock cycles.

4\. Read the 8 bits of data from P0.0-P0.7. These pins use open drain
outputs, so pull-up resistors are needed - the AVR's internal pullups
are good enough for this.

5\. Write P2.7 to 1 to stop reading the device.

### **Security**

There are two security features built into the 87C51 to stop end-users
from reading the firmware out of EPROM. Companies might use these
features as an anti-piracy measure: if they can keep their competitors
from reading their source code, then they can avoid giving away any of
their trade secrets. Both of these security features can be enabled
using the Minipro programmer.

First, the 87C51 has a 64 byte encryption table stored in EPROM. By
default, this table contains 64 `0xFF` bytes. When the chip is being
programmed, the table can be loaded with secret values. Then, when a
byte of the code is read from the code memory, it is XNORed with a
corresponding byte from the encryption table. In pseudocode, this is

    displayed_byte = ~(data[address] ^ enc_table[address % 64]);

Notice that the default encryption table has no effect on the data -
there is no encryption until the table has been written with some
values.

Second, the 87C51 has three lock bits that can be enabled. Lock bit 2
cannot be enabled until lock 1 is, and lock 3 cannot be enabled until
lock 2 is. The three locks have the following functions:

1.  EPROM can no longer be programmed. Also, some restrictions are
    placed on programs that use external memory.
2.  Verification is disabled. The device will read `0xFF` for every
    address.
3.  Programs cannot be executed from external memory.

The most critical of these locks is the second: it stops all
verification.

### **Gotchas**

This section describes a few quirks/caveats that we found with the 87C51
and its target board.

The 87C51 does some crazy things with the clock signal. First, the
external clock is fed into a divide by 2 counter to guarantee a 50% duty
cycle. Second, every instruction that the 8051 core executes takes a
multiple of 6 clock cycles. In other words, one "machine cycle" on the
chip is 6 internal cycles, which is 12 oscillator cycles.

When performing side channel attacks on the verify process, the relative
phase of the "machine clock" is important: the power consumption changes
significantly if we load the address on oscillator cycle 1, 2, 3, ...,
or 12. (The changes are more severe than a simple shift in time.) To
avoid these phase shifts, we tried to synchronize the AVR's verify
methods with the 8051's machine clock. We found that the 8051 has an
output (ALE/PROG) that is used for external timing - it is emitted at
1/6 of the oscillator frequency. By syncing to this signal, we narrowed
down the phase shift from 12 possible shifts to 2. However, we could not
find a way to remove this 1/2 chance. If you are capturing multiple sets
of traces, please look to see that the main features of the traces don't
move between captures\!

The 87C51 has a synchronous reset input (?\!) - a reset requires 12
oscillator cycles to take effect, and the machine clock's phase does not
change during a reset\! This means that the only way to change the
machine clock's phase is to power cycle the 87C51. (The "Read Signature"
button in the AVR Programmer does this. Pulling out the processor and
re-mounting it does too.)

## Schematic and Layout

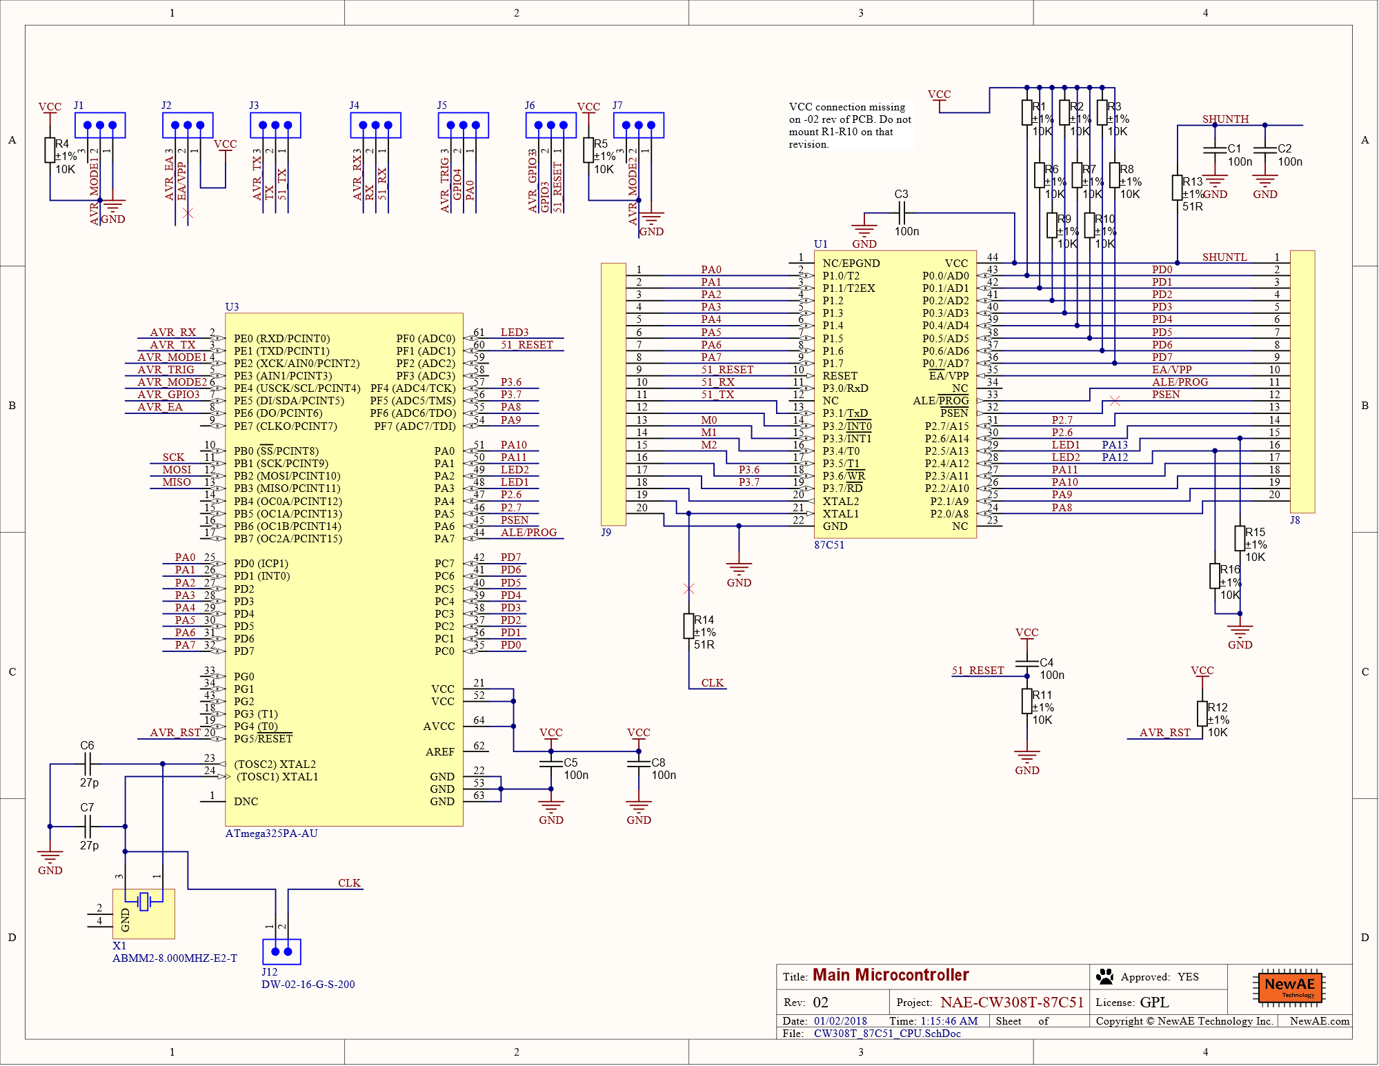
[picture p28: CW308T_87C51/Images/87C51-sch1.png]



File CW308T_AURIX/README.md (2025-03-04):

# CW308T-AURIX

This board supports the Infineon TC233LP microcontroller.



## Specifications

| Feature | Notes/Range |
|---|---|
| Target Device | Infineon TC233LP |
| Target Architecture | 32-bit TriCore |
| Vcc | 1.3V |
| Programming | JTAG |
| Hardware Crypto | No |
| Availability | Standalone |
| Status | Released |
| Shunt | 5.1Ω |

Available from:

 * [Mouser](https://www.mouser.com/Search/Refine?Keyword=NAE-CW308T-AURIX-TC233)

---

## Power Supply

The core of the TC233LP chip runs from a 1.3v supply that is generated
from an on-board regulator. The I/O buses are supplied with 3.3v.

---

## Clock

The TC233LP currently requires a 7.37MHz clock from the ChipWhisperer.
The PLL is setup to run at x1 speed (so still 7.37MHz).

---

## Security Features

The TC233LP has an additional Lockstep core that runs the same
instructions as the Master core (CPU0). The outputs of these cores are
compared and mismatches are reported in the Safety Management Unit of
the chip. This feature can only be enabled by editing the boot header of
the hex file you program the chip with.

---

## Programming

Programming of the AURIX board can currently only be done over JTAG with
the Infineon DAP miniWiggler v3 using Infineon Memtool. To program the
AURIX chip, begin by plugging in the miniWiggler to J6 on the CW308
board. Next, open Memtool.

Next, you'll need to add a target for the TC233LP chip. Navigate to
Target \> Browse and hit New. Select "Use a default target
configuration" and find "Application Kit with TC234 (DAS)" under
"Application Kits (DAS)", then hit "Finish". Hit "Connect". If "Ready
for Memtool Command" appeared next to it, everything went smoothly.

To actually program the device, open your hex file using "Open File..."
on the left hand side. Click on the address beginning with `0xA0000000`
and hit "Add Sel.\>\>". Finally, hit Program. Press the nRST button on
the CW308. Current versions of the HAL will light up LED1 upon starting,
so if this LED is on, your program has been successfully flashed.

The correct header to use on the miniWiggler is the DAP header (closest to the FT2232)>
The following 20-pin to 10-pin adapter can be used to connect the miniWiggler to
the ChipWhisperer: https://www.olimex.com/Products/ARM/JTAG/ARM-JTAG-20-10/

---

## Building Projects

To build projects for the TC233LP, you'll need [HighTec's Tricore Tool
Chain](https://free-entry-toolchain.hightec-rt.com/). Once the toolchain
is installed, you'll need to add it to your path.

Once that's done, standard ChipWhisperer projects should build with
`make PLATFORM=CW308_AURIX CRYPTO_TARGET=TINYAES128C`.

---

## Modifying Boot Header

To access some features of the TC233LP, such as the Lockstep control and
disabling boot pins, the boot header at the beginning of the hex file
must be modified. One way to do this is to use the "Edit" button in
Memtool. After selecting the first memory range (should begin with
0xA0000000), hit "Edit". Most of the important settings (including
lockstep control and boot control) are in the final 2 bytes of the
second word (address 0xA0000004).

After modifying the boot header, you'll need to calculate the CRC32 of
the header for addresses 0xA0000000 to 0xA0000017, as well as its
compliment (bitwise NOT). A resource like
<https://www.lammertbies.nl/comm/info/crc-calculation.html> can be used
to calculate the CRC. Make sure the input type is hex. The CRC32 should
go in address 0xA0000018, while its compliment should go in address
0xA000001C. For example, the full boot header for lockstep enabled
operation should be: 00000000 B3590170 00000000 00000000 00000000
00000000 964C0E85 69B3F17A.

Note that the boot header must be manually edited each time a project is
recompiled. One way to avoid this is to edit the startup file that sets
the boot header. This is included in the hal/aurix folder in
ChipWhisperer's firmware directory as crt0-tc2x.S. The boot header can
be found on lines 72 to 79. Note that the CRC32/compliment still has to
be calculated for lines 72 to 77, replacing the values of lines 78 and
79.

If LED1 does not illuminate after changing the boot header, something in
the header (like the CRC32) is likely incorrect.

---

## Schematic and Layout



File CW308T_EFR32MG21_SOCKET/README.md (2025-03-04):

# CW308T-EFR32MG21-SOCKET

The EFR32MG21 board features a QFN32 socket that matches the EFR32MG21A/B footprint from Silicon Labs. The EFR32MG21A/B device features a number of security features, including a dedicated “Secure Element” or “Secure Vault” core that performs a secure boot operation, and DPA countermeasures on cryptographic primitives.

The RF section is not broken out to a 50-ohm matched header, but instead a simple 3-pin header which allows potential usage in laboratory environments.

As this board contains a QFN socket, it is ideally suited for experiments such as template attacks, or potentially damaging attacks which require replacement of the main IC. In addition, this target can be easily shipped without restrictions as it does not contain any cryptographic functions (no IC at all is included).



```{warning}
    This target requires an external programmer to reload code.
```

---

## Quick Links

* [Buy on Mouser](https://www.mouser.com/Search/Refine?Keyword=NAE-CW308T-EFR32MG21-SOCKET)
* [Buy on Webstore](http://store.newae.com/efr32mg21-with-32qfn-socket-target-for-cw308/)
* [Download Schematic](https://github.com/newaetech/chipwhisperer-target-cw308t/raw/main/CW308T_EFR32MG21_SOCKET/NAE-CW308T-EFR32MG21-SOCKET_schematic.PDF)

## Specifications

| Feature | Notes/Range |
|---|---|
| Target Device | Not Included (fits EFR32MG21A010F1024 etc) |
| Target Architecture | Arm Cortex M33 |
| Vcc | 1.2V |
| Programming | JTAG |
| Hardware Crypto | Yes |
| Availability | Standalone |
| Status | Production |
| Shunt | 22-ohm |

## Power Supply

Break-out for various voltage rails, allowing over-driving of internal regulator to reduce noise for DPA measurements, or for testing fault injection detection capability.

---

## Security Features

EFR32MG21A (“Mighty Gecko Multiprotocol Wireless SoC”) has a high-performance Cortex M33 (TrustZone-M) with  a separate “secure element” core that handles the secure boot operation, along with multiple cryptographic accelerators (both AES and ECC) that include advertised DPA countermeasures.

The EFR32MG21B adds the "secure vault" feature.

---

## Programming

A JTAG programmer is typically required for these devices.

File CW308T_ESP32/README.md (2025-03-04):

# CW308T-ESP32

The ESP32 is a super-low-cost IoT device with Bluetooth & WiFi support.
This target board does not break out any of the RF capabilities, and is
primarily concerned with testing portions of the device stand-alone
(such as secure boot, AES hardware accelerator, etc).



## Specifications

| Feature | Notes/Range |
|---|---|
| Target Device | ESP32 |
| Target Architecture | LX6 |
| Vcc | 3.3V |
| Programming | SPI |
| Hardware Crypto | Yes |
| Availability | Standalone |
| Status | Released |
| Shunt | 10Ω |

Available from [Mouser](https://www.mouser.com/ProductDetail/NewAE/NAE-CW308T-ESP32?qs=r5DSvlrkXmJS2elCEG0eoA%3D%3D).

---

## SPI Buffer

This device uses a Texas Instruments TXB0104 as a SPI buffer. This is a
bidirectional buffer chip, meaning you can use it in any of the
following ways:

  - Disable chip, allowing ESP32 to load/program the attached SPI flash
    chip.
  - Sniff the SPI bus, but with a buffer in-line to prevent your sniffer
    from affecting the SPI load process (or trigger on SPI packets).
  - Program the SPI chip using external programmer. To do this hold
    ESP32 in reset.
  - Use an external SPI chip (or emulator) to load the data for the
    ESP32. To do this you'll have to disconnect the CS pin of the SPI
    chip.

The direction is detected automatically.

---

## SPI Flash Device

The ESP32 needs an attached SPI flash. The production devices use a
W25Q32BVSSIG from Winbond, but this can be difficult to find from
regular distributors. If you are building your own device I suggest
using ISSI IS25WP032D-JBLE which is more widely available.

A variety of other devices will not work with the bootloader, meaning
you cannot easily program them. It's not known exactly what is needed
(they need to support DSPI at least), but for example
SST26VF016BT-104I/SN did not work.

---

## Example Application

An example application is provided by the
[firmware/esp32 submodule](https://github.com/newaetech/chipwhisperer-esp32)
of the [chipwhisperer firmware](https://github.com/newaetech/chipwhisperer/tree/develop/firmware/mcu). 
Note this hasn't yet been integrated into the full build system. This application uses hardware AES.

---

## Schematic

For PDF see GIT repository.





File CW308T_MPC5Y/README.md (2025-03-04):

# CW308T-MPC5676R/MPC5777C

This target uses one PCB to support two different automotive chips: the MPC5676R, and the MPC5777C. These chips represent several different generations of PowerPC automotive devices. The later MPC5777C also includes SHE firmware in a security core.

Two CAN ports are connected out, along with various I/O. The ENGCLK output is available to synchronize to the internal clock during boot.

```{warning}
    This target requires an external programmer to reload code.
```

## Board Photos

### MPC5676R Version (SPC5676RDK3MVU1R)


### MPC5777C Versions (SPC5777CDK3MME3)


## Quick Links

* [Buy MPC5777C on Mouser](https://www.mouser.com/Search/Refine?Keyword=NAE-CW308T-MPC5777C)
* [Buy MPC5676R on Mouser](https://www.mouser.com/Search/Refine?Keyword=NAE-CW308T-MPC5676R)
* [Download Schematic](https://github.com/newaetech/chipwhisperer-target-cw308t/raw/main/CW308T_MPC5Y/NAE-CW308T-MPC5Y.PDF)

## Specifications 

| Feature | Notes/Range |
|---|---|
| Target Device | SPC5676RDK3MVU1R or SPC5777CDK3MME3 |
| Target Architecture | Triple Core PowerPC |
| Vcc | 1.3V |
| Programming | JTAG |
| Hardware Crypto | MPC5777C Only |
| Availability | Standalone |
| Status | Released |
| Shunt | 1Ω |

---

## Quick Start

### Hardware

To use this target, you should:

* Plug the target into a CW308 base-board.
* Ensure the CW308 has a 5V power supply - either by connecting to a ChipWhisperer-Pro, or using a 5V source on the 2.1mm DC power jack.
* Connect ChipWhisperer-Lite with script to setup clock etc.
* LED1 is the "RSTOUT" - you should be able to press the reset button on the CW308 and observe LED1 light up then go out. If LED1 is stuck on, the device is still in reset.

---

## Programming

The device is designed to use an external programmer for reflashing, as
it does not include a bootloader. The suggested programmer is the PE-Micro which requires purchasing:

  - PEMicro USB Multilink or USB Mulilink FX
	  - The "USB Multilink" is suitable for most uses, and is more reasonably priced.

Optionally you may want a stand-alone programmer, which requires:
  - PEMicro PROGPPCNEXUS (Programmer SW only) or PEMicro PowerPC Nexus
    Development Kit (includes Debugger).

### Bootloader

A bootloader is included on some devices. The MPC5676R has a loader which you can always enable, and will run provided code from SRAM, but it requires additional work for a full bootloader. It is highly suggested to use JTAG instead of the bootloader.

The MPC5777C requires JTAG for most uses, as the bootloader cannot be forced to run using only external pins.

---

## SHE Usage (MPC5777C ONLY)

Device includes Cryptographic Services Engine (CSE) that complies with Secure Hardware Extension (SHE) Functional Specification Version 1.1 security functions.

Details of interacting with this block are publicly available.

---

## Random Useful Tips

### **Disassembling Source**

If you are having trouble debugging, it can be useful to read out a
memory segment and disassemble it. This is possible with the included
S32DS tools. The following shows the required command line:

` E:\nxp\S32DS_Power_v2017.R1\Cross_Tools\powerpc-eabivle-4_9\bin>powerpc-eabivle-objdump.exe -mpowerpc -Me200z4 -D -b srec -EB MPC5748G.s19 > MPC5748G.txt`

## Schematic

* [Download Schematic](https://github.com/newaetech/chipwhisperer-target-cw308t/raw/main/CW308T_MPC5Y/NAE-CW308T-MPC5Y.PDF)

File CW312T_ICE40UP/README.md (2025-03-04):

# CW312T-iCE40

iCE40 UltraPlus (UP5K) Target for ChipWhisperer, with CW312 edge connector.



## Available Pins

To simplify routing so that the board can be produced/ordered on "standard" processes, no fancy vias are used (vias under the BGA would require microvias or filled vias). This
results in many connections on the schematic to allow routing of pads out:



## neorv32 Soft-Core Processor

This device can be loaded with a [neorv32](https://github.com/stnolting/neorv32) soft-core RISC-V processor. The ChipWhisperer repo includes a pre-built core so you *don't* need to rebuild this core
under normal circumstances. The default core is configured with the following setup:

* External clock directly drives core (no PLL).
* Bootloader runs at 19200 baud with  7.3728 MHz input frequency.
* 64KB data memory, 64KB code memory.
* Two GPIO pins (GPIO0/1 in the core, maps to GPIO3, GPIO4 on the PCB). GPIO3 is open-drain and thus has a pull-up on the PCB.
* Internal reset on power-up, no external reset input.

### Running Pre-Built Core

The pre-built core is loaded by the [neorv32 programmer](https://github.com/newaetech/chipwhisperer/blob/develop/software/chipwhisperer/hardware/naeusb/programmer_neorv32.py) which is normally
called from the [programmer interface](https://github.com/newaetech/chipwhisperer/blob/develop/software/chipwhisperer/capture/api/programmers.py):

If using the Jupyter notebooks simplify specify the target as `CW308_NEORV32`. This will:

1. Use the [neorv32 HAL](https://github.com/newaetech/chipwhisperer/tree/develop/firmware/mcu/hal/neorv32).
2. Use a `riscv32-unknown-elf-gcc` or `riscv64-unknown-elf-gcc` compiler (the 64-bit compiler normally can build for `rv32i` target we need).
3. Use the `cw.programmers.NEORV32Programmer` interface.

Using the standard interface the programming looks like:

```
cw.program_target(scope, prog, "simpleserial-aes-CW308_NEORV32.bin")
```

Where `prog` was set to `cw.programmers.NEORV32Programmer` in `Setup_Generic.ipynb`.

**NOTE**: As the iCE40 has no nRST pin by default, resetting the device is done by reconfiguring it. Note that
glitch attacks may result in corruption of the configuration RAM (CRAM) of the iCE40, so if using this target
for glitching it is suggested to reprogram it after **EVERY** attempt.

#### Lower-Level Programming Interface

The manual interface works as follows:

```
import chipwhisperer as cw
from chipwhisperer.hardware.naeusb.programmer_neorv32 import Neorv32Programmer
cw = cw.scope()
cw.default_setup()

neorv = cw.programmers.Neorv32Programmer()
neorv.open_port()
neorv.program("neorv32_exe.bin")
neorv.close_port()
```

This uses the `neorv32_exe.bin` name that the neorv makefiles build. It also programs the built-in soft-core.

### Rebuilding the Soft-Core

The board is part of the [neorv32-setups](https://github.com/stnolting/neorv32-setups) supported targets. To rebuild it:

* Install the toolchain (described [here](https://github.com/stnolting/neorv32-setups/tree/main/osflow#prerequisites)).
* Checkout [neorv32-setups](https://github.com/stnolting/neorv32-setups)
* Run `make BOARD=CW312iCE40 MinimalBoot`

You can specify the resulting `neorv32_iCE40CW312_MinimalBoot.bit` as part of the programming step with:

```
neorv.open_port()
neorv.program("neorv32_exe.bin", bsfile="neorv32_iCE40CW312_MinimalBoot.bit")
neorv.close_port()
```

## Schematic

The schematic is available as a [PDF](https://github.com/newaetech/chipwhisperer-target-cw308t/raw/main/CW312T_ICE40UP/NAE-CW312T-iCE40.PDF) or below as an image:



## DIY Soldering/Build

The WLCSP device chosen for the iCE40 was used for several reasons:

* During pandemic silicon shortage it was more widely available.
* WLSCP allows usage for [BBI fault injection](https://eprint.iacr.org/2020/1228.pdf).

If building your own, we have had great success with "flux-only" soldering rather than worrying about the small pitch BGA paste.

To do this, put some liquid flux down, put the WLCSP package on the board (align it carefully), and heat with hot air (our). Watch the side of the
WLCSP package until it appears to have seated on all sides. Remove the hot air.

## CW308T Version

An earlier version of this board was [available with the CW308T pinout](https://github.com/newaetech/chipwhisperer-target-cw308t/tree/main/CW308T_ICE405). The iCE40 connections are identical.

The CW308T version was never produced by NewAE, but you can build your own if you prefer this layout.

The firmware HAL still uses the `CW308` name for this reason.

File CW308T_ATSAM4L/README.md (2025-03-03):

# CW308T-SAM4L

This board supports the Atmel SAM4L microcontroller. The default build
has the Atmel ATSAM4LC2AA-AU, which has 128KB flash and 32KB SRAM.



---

## Specifications

| Feature | Notes/Range |
|---|---|
| Target Device | ATSAM4L |
| Target Architecture | Arm Cortex-M4 |
| Vcc | 1.8V |
| Programming | JTAG |
| Hardware Crypto | Yes (includes countermeasures) |
| Availability | Standalone |
| Status | Released |
| Shunt | 10Ω |

Available from [Mouser](https://www.mouser.com/ProductDetail/NewAE/NAE-CW308T-ATSAM4L?qs=PzGy0jfpSMv5ToVL8lnUZg%3D%3D)

## Power Supply

The Atmel SAM4L has an internal 1.8V regulator. This regulator is not
used in the board, instead power for the core is supplied by an external
LDO on the UFO board. Be sure to enable the 1.8V and 3.3V regulators on
the UFO board for the SAM4L board to function.

---

## Hardware AES

The SAM4L has a hardware AES module, with optional countermeasures that
can be enabled. These countermeasures are described in the SAM4L
datasheet as the following options:

  - Type 1: Randomly add one cycle to data processing
  - Type 2: Randomly add one cycle to data processing (other version)

  - Type 3: Add a random number of clock cycles to data processing,
    subject to a maximum of 11 clock cycles for key size of 128 bits
  - Type 4: Add random spurious power consumption during data processing

Interestingly they can be individually enabled/disabled. This makes the
SAM4L a useful training target for power analysis attacks against
various hardware countermeasures.

---

## Programming

An external programmer is needed for this target. The SAM4L has an
internal bootloader you can use via an external serial port, which is
not yet supported directly by the ChipWhisperer-Capture software.

### **JTAG Programmer**

The 20-pin JTAG port (J6 on CW308 Board) can be used with the
[ATATMEL-ICE](https://www.digikey.com/product-detail/en/microchip-technology/ATATMEL-ICE/ATATMEL-ICE-ND/4753379)
which is Atmel's JTAG programmer. You can use any other ARM programmer
you might have as well (i.e., OpenOCD, Segger J-Link, etc).



### **Using Atmel SAM-BA**

Atmel SAM4L has a built-in bootloader. Not this bootloader is NOT
ROM-Resident - if you reprogram the device the bootloader is lost, since
it is stored in flash memory. It is recommended to use an external JTAG
programmer for this target, as since the bootloader is not ROM-resident
it can easily be overwritten by accident (i.e., if connecting a JTAG
programmer).

---

## SimpleSerial Program

The SimpleSerial-AES program can be built for this target. This can use
either hardware crypto or a software AES. This project is currently
built via the Atmel Studio IDE, and the project file is located at
[firmware/mcu/simpleserial-aes/ide\_projects/asf/sam4l-simpleserial-aes](https://github.com/newaetech/chipwhisperer/tree/develop/firmware/mcu/simpleserial-aes/ide_projects/asf/sam4l-simpleserial-aes)
with the ChipWhisperer release.

If an Atmel ICE is attached as above, you should be able to build and
run the example in 'debug' mode:



An automatically generated makefile can be modified to built in Linux,
but currently has not been integrated into the rest of the system. This
makefile is checked into the GIT repository.

### **Adjusting Hardware AES**

Inside the file *hwaes.c* you will find the AES hardware initialization.
This is given in the following code sample:

``` c
void aes_init(void)
{
    periclk_aesa_init();
    SCIF->SCIF_GCCTRL[AESA_GCLK_NUM].SCIF_GCCTRL = SCIF_GCCTRL_OSCSEL(GENCLK_SRC_CLK_CPU) |  SCIF_GCCTRL_CEN;

    /* AES Enable */
    AESA->AESA_CTRL = AESA_CTRL_ENABLE | AESA_CTRL_NEWMSG; /* Enable, auto-accept new messages */

    //Use with debugger to check PARAMETER register value
    //volatile uint32_t param = AESA->AESA_PARAMETER;

    /* AES Mode */
    AESA->AESA_MODE = AESA_MODE_ENCRYPT | (AESA_MODE_CTYPE(0x0F)); /* Encrypt Mode, with all countermeasures */
    //AESA->AESA_MODE = AESA_MODE_ENCRYPT; /* Encrypt Mode, without countermeasures */

    /* Setup random seed for countermeasures to work */
    AESA->AESA_DRNGSEED = 0xDEADBEEF; //A very random number
}
```

Note there are two options shown, where countermeasures can be enabled
or disabled. You can see the SAM4L datasheet for a description of the
countermeasures. The following compares the power traces with and
without countermeasures:

The following shows countermeasures enabled, you can see various
execution paths taken during the encryption:



Compare this to the countermeasures disabled:



---

## Schematic

See GIT Repo for PDF of schematic.





---

## Board Layout

See GIT Repo for gerber files.

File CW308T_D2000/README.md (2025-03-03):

# CW308T-D2000

The D2000 target is a bit of an oddball. It's an x86 target, but is
really a microcontroller (internal flash etc).



---

## Specifications

| Feature | Notes/Range |
|---|---|
| Target Device | Intel Quark D2000 |
| Target Architecture | x86 |
| Vcc | 3.3V |
| Programming | JTAG |
| Hardware Crypto | No |
| Availability | Standalone |
| Status | Released |
| Shunt | 10Ω |

Available from [Mouser](https://www.mouser.com/ProductDetail/NewAE/NAE-CW308T-D2000?qs=r5DSvlrkXmIpxDv1CU6e4Q%3D%3D) and the [NewAE Store](https://store.newae.com/intel-d2000-x86-microcontroller-target-for-cw308/)

## Using Board

The CW308T-D2000 is used similar to any other CW308 Target Board. It
does not accept an external oscillator, instead it outputs it's own
oscillator for you to synchronize to. Specific caveats here:

  - Be sure to mount J3 at lowest setting which routes the "CLKFB" line
    to "HS1/IN".
  - You'll need to configure the ChipWhisperer to use an external clock
    input (EXTCLK or EXTCLK x4). This is taken care of by the D2000
    setup script.
  - The baud rate will need to be changed - it is scaled to be 115200 at
    32 MHz. Use the frequency counter to measure the actual frequency &
    scale baud rate appropriately. Depending on the ROM loaded the clock
    varies. This is taken care of by the D2000 setup script.
  - The TX/RX are opposite compared to the XMEGA. This is taken care of
    by the D2000 setup script.

The following shows an example setup script for this board:

``` python

scope.gain.gain = 45
scope.adc.samples = 25000
scope.adc.offset = 0
scope.adc.basic_mode = "rising_edge"
scope.clock.clkgen_freq = 7370000
scope.clock.adc_src = "extclk_x4"
scope.trigger.triggers = "tio4"
#TX/RX backwards from XMEGA
scope.io.tio1 = "serial_tx"
scope.io.tio2 = "serial_rx"
scope.io.hs2 = None

# Sample delay - you may need to increase this!
# Gives time for frequency measurement to occur in hardware.
time.sleep(0.5)

ext_freq = scope.clock.freq_ctr

if ext_freq > 10:

    baud = (115200 / 32E6) * ext_freq
    print "Based on extclk of %d Hz, setting baud to %d" % (ext_freq, baud)
    target.baud = baud

else:
    raise IOError("Did not detect external clock from D2000.
    Confirm jumpers and rerun, or increase delay before sample."
```

---

## Building Firmware

To build firmware for the D2000, you'll need to download the [Intel ISSM
Toolchain](https://software.intel.com/en-us/articles/issm-toolchain-only-download)
and uncompress it. The toolchain comes compressed/archived in the tar.gz
format, so you may need to download a program that can work with those
formats (such as 7-zip on Windows). Firmware is contained in
`firmware/mcu/intel_quark/simpleserial_example/` and can be
built with make. Note that you'll need to specify where the toolchain is
located:

### **Specifying Toolchain Location**

If you're using `cmd` on Windows (as opposed to something like `Git
Bash` or `Cygwin`, you'll need to create a new environment variable
called `IAMCU_TOOLCHAIN_DIR` and set its value to the path to the
toolchain. For example, I uncompressed the toolchain to
`C:\Users\User\Downloads` and set the variable to
`C:\Users\User\Downloads\issm-toolchain-windows-2017-01-25\tools\compiler\gcc-ia\5.2.1\bin`.
Otherwise, running `export /path/to/toolchain/bin` should work on Mac,
Linux, Git Bash, Cygwin, etc.

### **Troubleshooting**

* No such file or directory when building on Windows

  - This is usually caused by the default make directory command (`md`)
not working. First, ensure that you have `mkdir` and cp on your system
by opening `cmd` and running them. Then open
`firmware/mcu/intel_quark/qmsi/base.mk` and change:

``` makefile
# Any other version of Windows
mkdir = @md $(subst /,\,$(1)) > nul 2>&1 || exit 0
copy = @copy $(subst /,\,$(1)) $(subst /,\,$(2)) > nul 2>&1 || exit 0
```

to:

``` makefile
# Any other version of Windows
mkdir = @mkdir -p $(1) || exit 0
copy = @cp $(1) $(2) || exit 0
```

---

## Programming

An external programmer is needed for this target. The Quark D2000
dev-board can be used with jumper wires, or a standard OpenOCD
programmer can be used. The suggested programmer is the [Olimex
ARM-USB-OCD-H](https://mouser.com/ProductDetail/Olimex-Ltd/ARM-USB-OCD-H)
as is available from suppliers such as Mouser and Digi-Key (mouser link
provided).

### **OpenOCD Board Setup**

If using OpenOCD either stand-alone or as part of Intel ISSM, you'll
need to define a new board file. The file is based on
`scripts\board\quark_d2000.cfg` found in the following directory:
`C:\IntelSWTools\ISSM_2016.0.027\tools\debugger\openocd\scripts\board`
(adjust for version number changes).

You will find a line like the following in the original file:

` #default frequency but this can be adjusted at runtime`
` adapter_khz 1000`

Make a copy of the file, but change that to a slower speed (suggested is
125 kHz)

` #default frequency but this can be adjusted at runtime`
` adapter_khz 125`

Save this file as `quark_d2000_ufo.cfg`.

### **How to flash D2000 board using OpenOCD**

We'll modify the provided scripts from the Intel ISSM distribution
(compiler etc for D2000). Start a Windows command prompt and run the
following commands. You may have to change the directory of the first
command to match your version of Intel ISSM (eg.
C:\\IntelSWTools\\ISSM\_2016.0.027\\issm\_env.bat):

`C:\IntelSWTools\ISSM_2016.2.097\issm_env.bat`
`cd %ISSM_DEBUGGER_ROOT%\openocd`
`bin\openocd.exe -f scripts\interface\ftdi\olimex-arm-usb-ocd-h.cfg -f scripts\board\quark_d2000_ufo.cfg`

Note we specify two script files - the first had the JTAG connection
(the olimex-arm-usb-ocd-h.cfg), the second had the D2000. This should
result in an output like the following:

`Open On-Chip Debugger 0.8.0-dev-g7845893 (2015-11-26-18:12)`
`Licensed under GNU GPL v2`
`For bug reports, read`
`       `<http://openocd.sourceforge.net/doc/doxygen/bugs.html>
`Info : only one transport option; autoselect 'jtag'`
`adapter speed: 125 kHz`
`trst_only separate trst_push_pull`
`flash_rom`
`Info : clock speed 125 kHz`
`Info : JTAG tap: quark_d2000.cltap tap/device found: 0x0e786013 (mfg: 0x009, part: 0xe786, ver: 0x0)`
`Enabling lmt core tap`
`Info : JTAG tap: quark_d2000.lmt enabled`

At this point it will hold, waiting for new commands. There is two ways
to proceed:

#### **Connecting with GDB**

Connecting and programming with GDB may be preferred if you wish to also
do any debug. It however is more limited in what commands you can run.
If this does not work see the next section about using telnet commands.
Open a second command prompt, and run:

`C:\IntelSWTools\ISSM_2016.0.027\issm_env.bat`
`gdb`

You can then run the following within a GDB console:

`target remote :3333`
`monitor clk32M 125`
`monitor load_image C:\\chipwhisperer\\\\firmware\\mcu\\intel_quark\\quark_d2000_rom.bin 0x0`
`monitor load_image C:\\chipwhisperer\\\\firmware\\mcu\\intel_quark\\simpleserial_example\\release\\quark_d2000\\x86\\bin\\simpleserial_aes.bin 0x00180000`

The first load\_image is used for the ROM image. This should only be
done once - do not reload every time, only reload the application. The
boards as shipped come with a ROM image so you can skip that step if
using the NewAE example code.

Notes:

1.  The `monitor clk32M 125` sets a 125 kHz JTAG clock frequency. This
    may be too slow, but is recommended especially when loading ROM due
    to potential for misprogramming on the target board due to the shunt
    resistor. Note it takes a long time (\~60 seconds) to program the
    ROM code so don't abort it\!
2.  If the above fails, see the next note on recovering normal settings
    with the telnet interface.
3.  You can short F13 (GPIO1 on the ChipWhisperer-Lite) to GND to force
    the JTAG pins on. It is suggested to do this via the
    ChipWhisperer-Lite software (setting it as a GPIO output and then
    setting it low). This requires the 'ROM' code programmed in already.
4.  Do not reload the ROM code unless needed -- this is the boot code
    and if something gets corrupt it can brick the device.

#### **Connecting with Telnet to Monitor**

When running the `target remote :3333` or other commands above, you may
encounter errors that seem fatal. Do not fret, you can likely recover
everything using another mode. To do so:

1.  Power cycle the target board, and re-run the openocd command
    previously specified (assuming you have encountered errors and the
    system is in an unknown state).
2.  If this fails, set GPIO1 to LOW, and power cycle the target. Try
    connecting again.

Assuming the connect works, open a second command prompt and run

`telnet localhost 4444`

Note the port connected to is 4444 (not :3333) as before. This now
enters the monitor directly, and you can try running the following
commands:

`reset halt`
`set QUARK_D2000_OTPC_DATA_WRITE_ENABLED 1`
`mass_erase`
`clk32M 100`
`load_image C:\\chipwhisperer\\firmware\\mcu\\intel_quark\\quark_d2000_rom.bin 0x0`
`load_image C:\\chipwhisperer\\firmware\\mcu\\intel_quark\\simpleserial_example\\release\\quark_d2000\\x86\\bin\\simpleserial_aes.bin 0x00180000`

The following should be the example output of these commands:

`> reset halt`
`JTAG tap: quark_d2000.cltap tap/device found: 0x0e786013 (mfg: 0x009, part: 0xe786, ver: 0x0)`
`Enabling lmt core tap`
`JTAG tap: quark_d2000.lmt enabled`
`target state: halted`
`target halted due to debug-request at 0x0000ffff in real mode`
`target state: halted`
`target halted due to debug-request at 0x0000fff0 in real mode`
`> set QUARK_D2000_OTPC_DATA_WRITE_ENABLED 1`
`1`
`> mass_erase`
`Deleting  OTPC, OTPD and FLASH regions`
`0xb0100014: 00000001`
`> clk32M 100`
`adapter speed: 3 kHz`
`adapter speed: 100 kHz`
`JTAG tap: quark_d2000.cltap tap/device found: 0x0e786013 (mfg: 0x009, part: 0xe786, ver: 0x0)`
`Enabling lmt core tap`
`JTAG tap: quark_d2000.lmt enabled`
`target state: halted`
`target halted due to debug-request at 0x0000fff0 in real mode`
`> load_image C:\\chipwhisperer\\firmware\\mcu\\intel_quark\\quark_d2000_rom.bin 0x0`
`....8192 bytes written at address 0x00000000`
`downloaded 8192 bytes in 66.997505s (0.119 KiB/s)`
`> load_image C:\\chipwhisperer\\firmware\\mcu\\intel_quark\\simpleserial_example\\release\\quark_d2000\\x8`
`.2872 bytes written at address 0x00180000`
`downloaded 2872 bytes in 42.280869s (0.066 KiB/s)`

Note you can try the following if still having trouble:

1.  Use a slower JTAG clock speed. Be SURE you are using a custom .cfg
    file which specifies the slower JTAG speed on initial connect (and
    not just as part of the clk32M commands).
2.  Short the SHUNTH/SHUNTL pins.

---

## Schematic

See GIT Repo for PDF of schematic. Note there is a new "03C" rev that
changes the shunt resistor (R1) to a 1-ohm resistor. This results in a
much more reliable device, as the original 10-ohm shunt caused
occasional crashes. If you are using an older revision device, you can
mount a shunt/jumper between "SH-" and "SH+" on the UFO board to achieve
a similar effect.



---

## Board Layout

See GIT Repo for gerber files.

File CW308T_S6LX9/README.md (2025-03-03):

# CW308T-S6LX9

The S6LX9 target is a low-cost FPGA target. It uses the Xilinx Spartan 6
in TQFP package (XC6SLX9-2TQG144C), and can fit an entire AES core. The
example project includes the Simple-Serial interface which allows it to
function like any of our other example targets.



---

## Specifications

| Feature | Notes/Range |
|---|---|
| Target Device | Spartan 6 LX9 |
| Target Architecture | FPGA |
| Vcc | 1.2V |
| Programming | JTAG |
| Hardware Crypto | Yes |
| Availability | Standalone |
| Status | Released |
| Shunt | 1Ω |

Available from [Mouser](https://www.mouser.com/ProductDetail/NewAE/NAE-CW308T-S6LX9?qs=r5DSvlrkXmLB6Wv0H65vSg%3D%3DA)
and the [NewAE Store](https://store.newae.com/spartan-6-lx9-fpga-target-for-cw308/)

## Usage

The board includes a single red LED (D1) which is connected to the FPGA
"DONE" pin. This pin will be HIGH (and the LED on) when the FPGA is NOT
programmed. That is to say immediately on power-on, the LED will be on.
Once the FPGA is successfully programmed this LED will go out.

The FPGA pins are connected to the various headers on the board. The
JTAG header connects to the FPGA JTAG pins. The "Hx" pins, USART, and
SPI connect to arbitrary FPGA pins.

'''NB: You MUST enable the 1.2V regulator when using this board. The
1.2V power LED should be ON. This is easily done by toggling the
position of the 1.2V LDO switch (to either come from the 3.3V from
CW-Lite, or external power depending on your setup). '''

---

## Example Project

The GIT repo includes an example Xilinx ISE project, located at
[firmware/fpgas/aes/ise/](https://github.com/newaetech/chipwhisperer/tree/develop/firmware/fpgas/aes/ise).
To use this project:

1.  Build the bitstream (or see the pre-built one in the repo at
    [cw308t\_s6lx9\_example.bit](https://github.com/newaetech/chipwhisperer/raw/develop/firmware/fpgas/aes/ise/cw308t_s6lx9_example.bit))
1.  Use settings as in the 'Default XMEGA' or 'STM32Fx' targets (i.e.,
    clock jumpers, etc).
1.  Ensure you have turned on the 1.2V & 3.3V power supplies to the UFO
    target.
1.  Program the bitstream into the FPGA using a programming tool such as
    Xilinx Impact + USB Programmer cable.
1.  Connect to the ChipWhisperer scope and call `scope.default_setup()`
1.  The target supports SimpleSerial v1.0, meaning that it won't ACK. If using `capture_trace()`, call
    as follows: `cw.capture_trace(scope, target, text, key, ack=False)`
1.  Adjust the trigger offset settings - they should be changed to
    around \~750, and you can reduce the number of data points to \~128.

The waveform should look something like this:



---

## Known Issues

Note the -02 Revision of the PCB has swapped the markings of the
CLKIN/CLKOUT. The correct pinout is:

  - CLKIN connects to P84
  - CLKOUT connects to P85

The CLKIN pin is a _N clock pin. If you need the _P clock pin, you can
use a jumper on the CW308 board to route the clock input into the CLKOUT
pin.

---

## Programming

The ChipWhisperer will eventually support programming this target. Until
then, you will need an external programmer. This is connected via JTAG
to the pin headers:



Options for programmers include:

  - Xilinx Platform Cable USB or USB-II (Digikey/Mouser).
  - Clone JTAG programmers off AliExpress/E-Bay for low cost (search
    'Xilinx JTAG').
  - Digilent Inc HS1/HS2/HS3 Cables (NB: you may need separate jumper
    wires).

To use IMPACT:

  - Generate a new project.
  - Assign the .bit file to the FPGA (say 'no' to attached SPI flash
    chips).
  - Program.



---

## Schematic

See GIT Repo for PDF of schematic.







---

## Board Layout

See GIT Repo for gerber files.

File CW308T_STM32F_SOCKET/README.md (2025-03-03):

# CW308T-STM32F-SOCKET

The CW308-STM32F-SOCKET board is the perfect target for testing fault injection against TQFP-64 STM32F/STM32L
microcontrollers. Thanks to pin compatibility (mostly) between various devices, this single board
supports multiple STM32F/STM32L microcontrollers.

These boards do not ship with any microcontroller, but use a 64-pin TQFP socket.



## Specifications

| Feature | Notes/Range |
|---|---|
| Target Device | STM32F |
| Target Architecture | Arm Cortex M0, M3, M4 |
| Hardware Crypto | Possible |
| Programmer | STM32F Serial Bootloader, JTAG, SWD |
| Availability | Starter kits, Standalone |
| Status | Released |

* Available from [NewAE Webstore](http://store.newae.com/stm32f-tqfp64-socket-target-for-cw308/)

---

## Supported Devices

The STM32F board supports several STM32F devices in the TQFP-64 package.
The switch needs to be set in either the "A" or "B" position
to select appropriate VCC supply for the different series. The following
table summarizes examples of suitable devices, in the following list these devices are available in fixed boards as well.

| **STM32F Series** | **Package** | **Device** | **Hardware AES** | **Tested** | **Jumper** | **Flash** | **SRAM**  | **NAE P/N for Fixed PCB ** |
| --- | --- | --- | --- | --- | --- | ----- | ----- | --- |
| F0 | TQFP-64 | STM32F071RBT6  | No | Yes | B | 128KB | 16KB  | NAE-CW308T-STM32F0 |
| F1 | TQFP-64 | STM32F100RBT6B | No | Yes | B | 128KB | 8KB | NAE-CW308T-STM32F1 |
| F2 | TQFP-64 | STM32F215RET6  | Yes | Yes | A | 512KB | 132KB | NAE-CW308T-STM32F2HWC |
| F3 | TQFP-64 | STM32F303RCT7  | No | Yes | B | 256KB | 40KB  | NAE-CW308T-STM32F3 |
| F4 | TQFP-64 | STM32F415RGT6  | Yes | Yes | A | 1MB | 192KB | NAE-CW308T-STM32F4HWC |
| F4 | TQFP-64 | STM32F405RGT6  | No | Yes | A | 1MB | 192KB | NAE-CW308T-STM32F4 |
| L4 | TQFP-64 | STM32L443RCT6  | Yes | Yes | B | 256KB | 64KB  | NAE-CW308T-STM32L4 (this version has hardware crypto) |
| L5 | TQFP-64 | STM32L562RET6  | Yes | Yes | B | 512KB | 256KB | NAE-CW308T-STM32L5HWC |

### **VCC-Int Supply**

Several devices (F2, F4) have internal core voltage regulators. By
default the CW308 board attempts to provide power for these pins, but
the voltage may not be high enough to cause the internal regulator to
disable itself. In this case you can use the VADJ regulator to ensure
the internal regulator is disabled.

### **Pin-outs across TQFP Devices**

The following shows differences in pinouts between three groups of
devices. The left-most is the STM32F051RB, which uses the same 3.3V
VCORE as the STM32F1/F3. It has fewer VCC pins, so the I/O occupying
that are VCC/GND pins on the STM32F1 (such as PF6/PF7) are tied to
GND/VCC. The right-most part is the pinout of the STM32F2/F4. It has an
internal regulator, where the VCAP pins are the output of this regulator
(and input to the internal core logic).



Decoupling
capacitors C5/C6/C7/C8 are DNM, as they will weaken leakage on devices with a 3.3V core.

## Example Projects and Using Target

* See note above about setting switch SW1 to route correct power to the target device.

* General usage information is available on the [STM32Fx target board documentation page](../CW308T_STM32F/README.md).

### Schematic



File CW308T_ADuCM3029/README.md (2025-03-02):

# CW308T-ADUCM3029

This board supports the Analog Devices ADuCM3029 microcontroller. The
mounted chip is the ADUCM3029BCPZ.

This is a BETA target and not yet available. This page will continue to be updated until release. Gerbers are available in the GIT repo if you live dangerously.



## Specifications

| Feature | Notes/Range |
|---|---|
| Target Device | ADuCM3029 |
| Target Architecture | Arm Cortex M3 |
| Vcc | 1.8V-3.3V |
| Programming | Serial bootloader, SWD |
| Hardware Crypto | Yes |
| Availability | Gerbers/Source |
| Status | In development  |
| Shunt | 12Ω |

---

## Power Supply

The ADuCM3029 can run from a core supply voltage between 1.8 and 3.3
volts. By default the core is fed from the 3.3v supply but the
adjustable regulator on the CW308T can be used to set any viable core
voltage. Sometimes power analysis is more viable at different supply
voltages.

---

## Cryptographic Accelerator

As described in the [ADuCM3027/3029 Data Sheet](http://www.analog.com/media/en/technical-documentation/data-sheets/ADuCM3027_3029.pdf), The cryptographic
accelerator is a 32-bit APB DMA capable peripheral. There are two 32-bit
buffers provided for data input/output operations. These buffers read in
or read out 128 bits in four data accesses. Big endian and little endian
data formats are supported, as are the following modes:

  - Electronic code book (ECB) mode—
  - AES mode (128 and 256)
  - Counter (CTR) mode

  - Cipher block chaining (CBC) mode
  - Message authentication code (MAC) mode
  - Cipher block chaining-message authentication code (CCM/CCM) mode
  - SHA-256 mode

---

## Programming

The ADuCM3029 supports a serial bootloader which is enabled by pulling
down the PDIC pin on the CW308T. Details for using the serial bootloader
can be found in the application note [EE-381](http://www.analog.com/media/en/technical-documentation/application-notes/EE381v01.pdf). Currently,
ChipWhisperer doesn't have support for this bootloader, meaning
the user must code their own programmer application. Also, the
bootloader only supports writing memory to SRAM, meaning
the user's code is responsible for writing itself to flash.
 
Single wire debug (SWD) is also supported for programming and debugging.

---

## Schematic and Layout




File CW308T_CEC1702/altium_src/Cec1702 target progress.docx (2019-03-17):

Cec1702 target progress – currently on hold

Successfully programed secureIoT development board – instructions on wiki

Spi flash programming on target board works

Buffer works

Main chip wont boot, tried the following

- Removed power shunt
- Changed PLL capacitance
- Attached crystal
- Measured power rails, all good
- Measured core voltage, all good
- Scoped both sides of buffer, no attempt from chip to read flash

Corrections needed for rev2

- Connect UFO vrefs to 3.3
- Do not route all 3.3v power through filter, only core power
- Make the chip work?

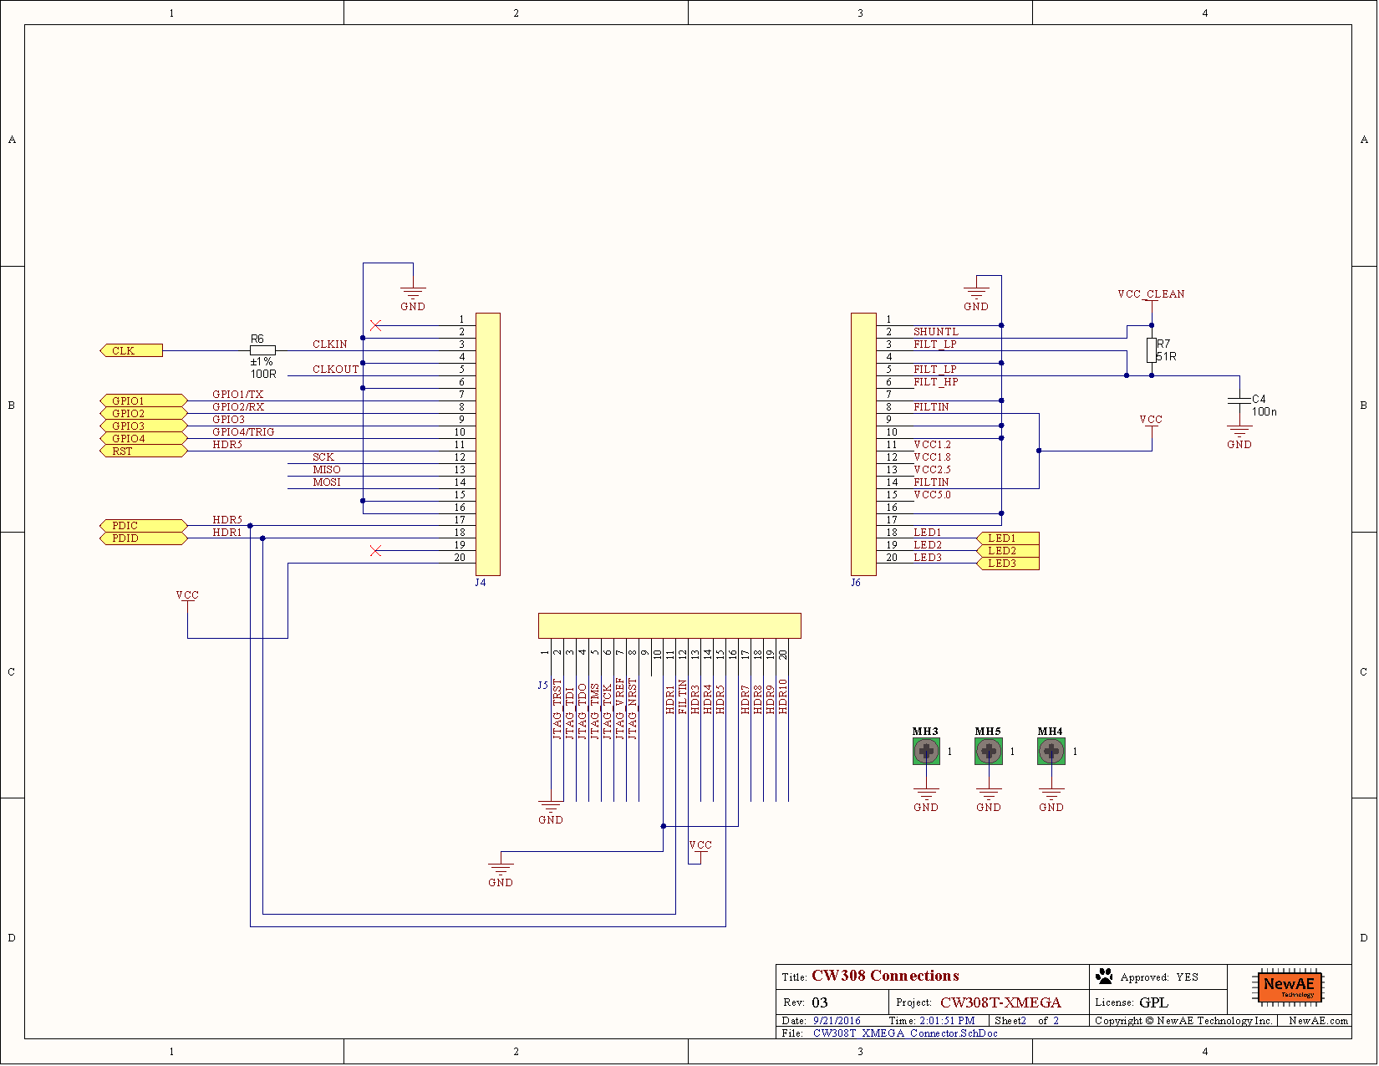
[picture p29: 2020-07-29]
CW308T_XMEGA/Images/CW308T_XMEGA_Schematic_Page_2.png

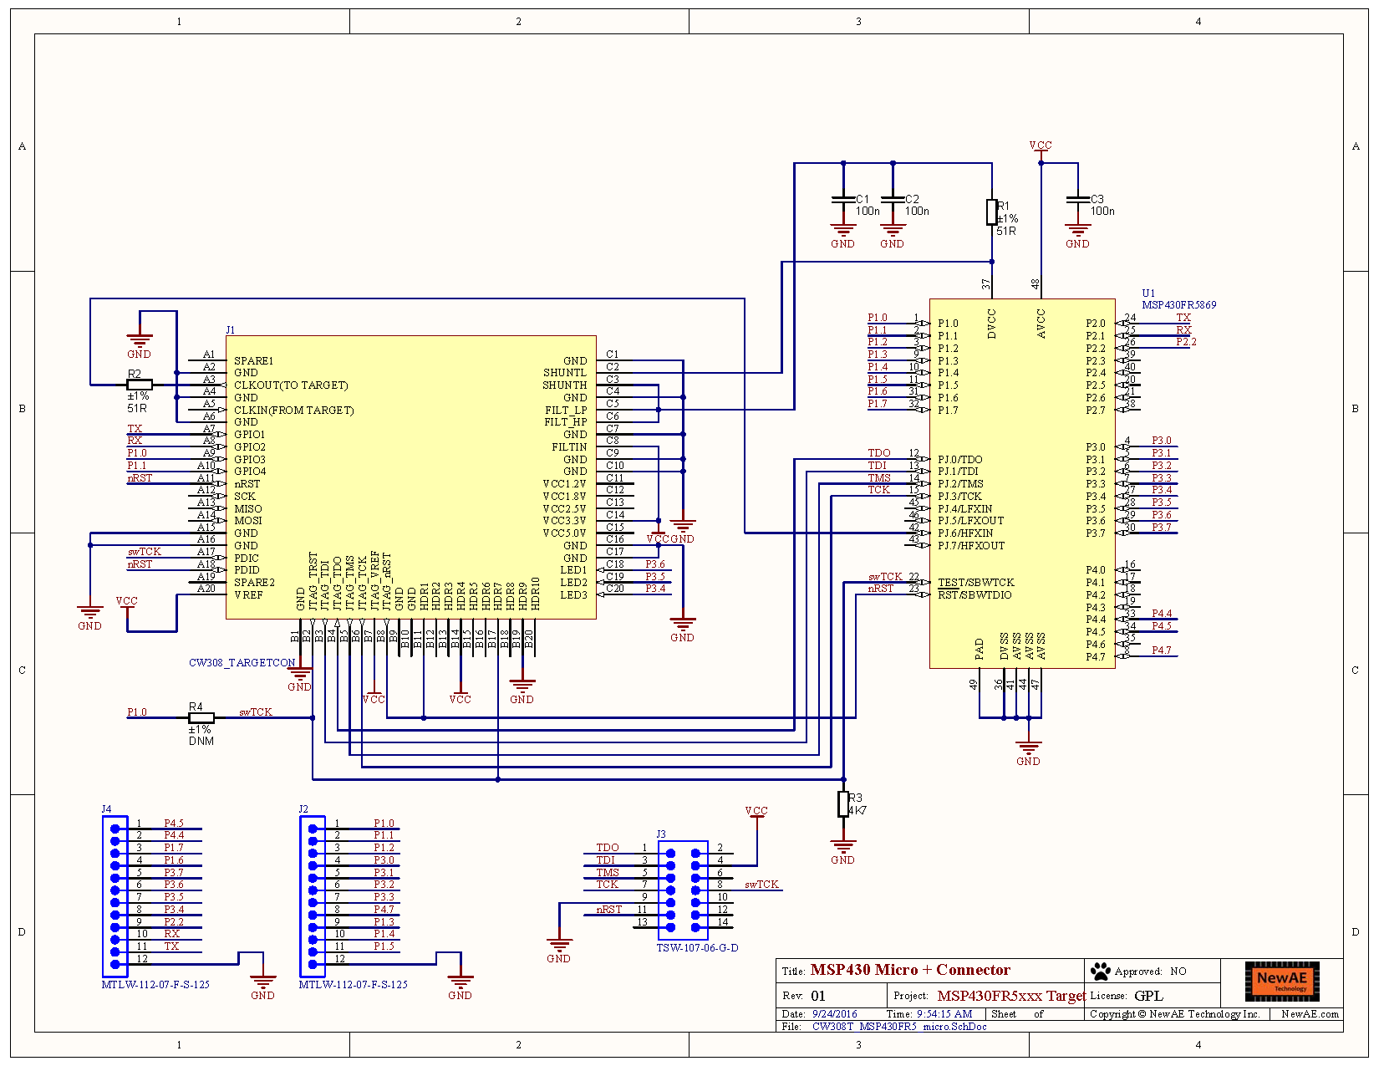
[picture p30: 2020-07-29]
CW308T_MSP430/Images/CW308T_MSP430FR5xxx_Schematic.png

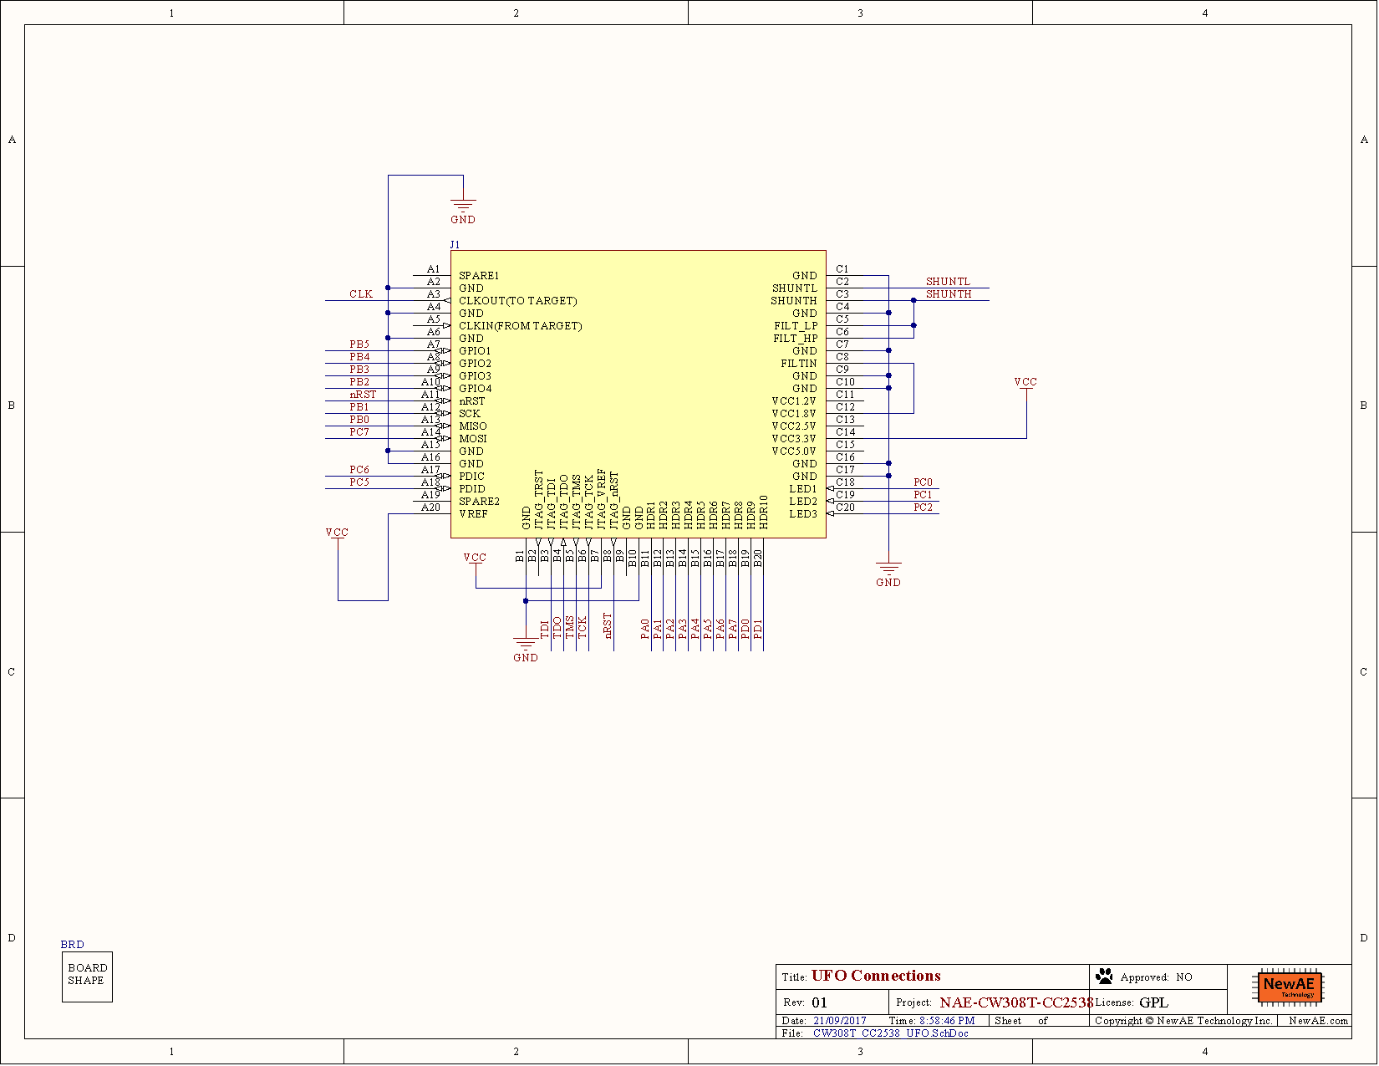
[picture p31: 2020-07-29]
CW308T_CC2538/Images/CW308T-CC2538-01_schematic_Page_2.png

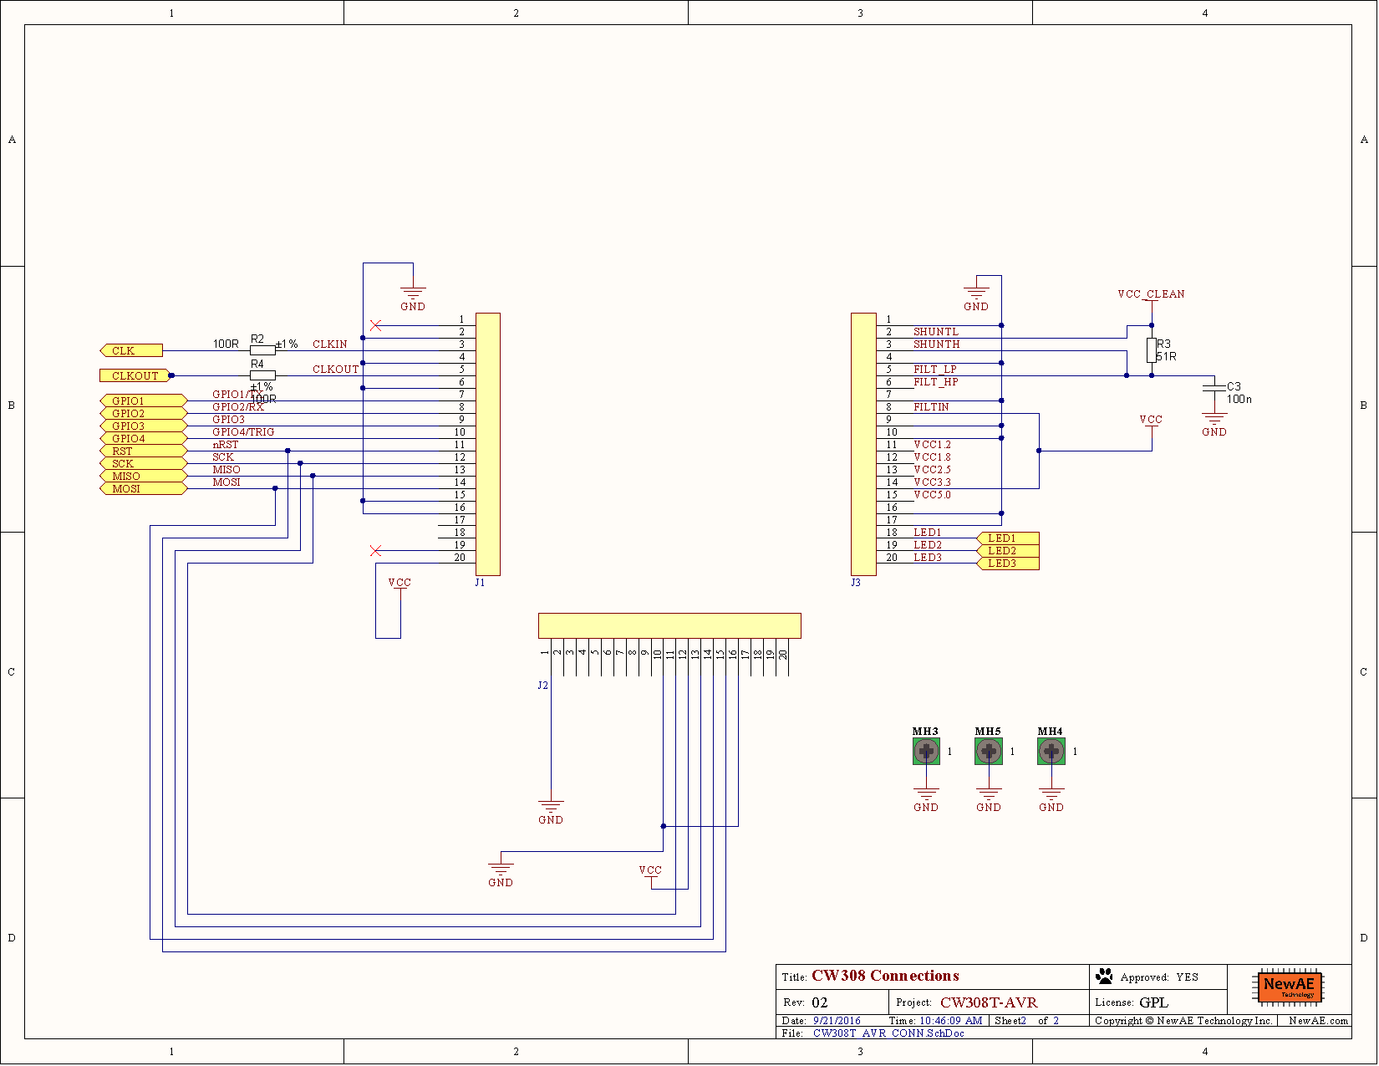
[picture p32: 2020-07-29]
CW308T_AVR/Images/CW308T_AVR_Schematic_Page_2.png

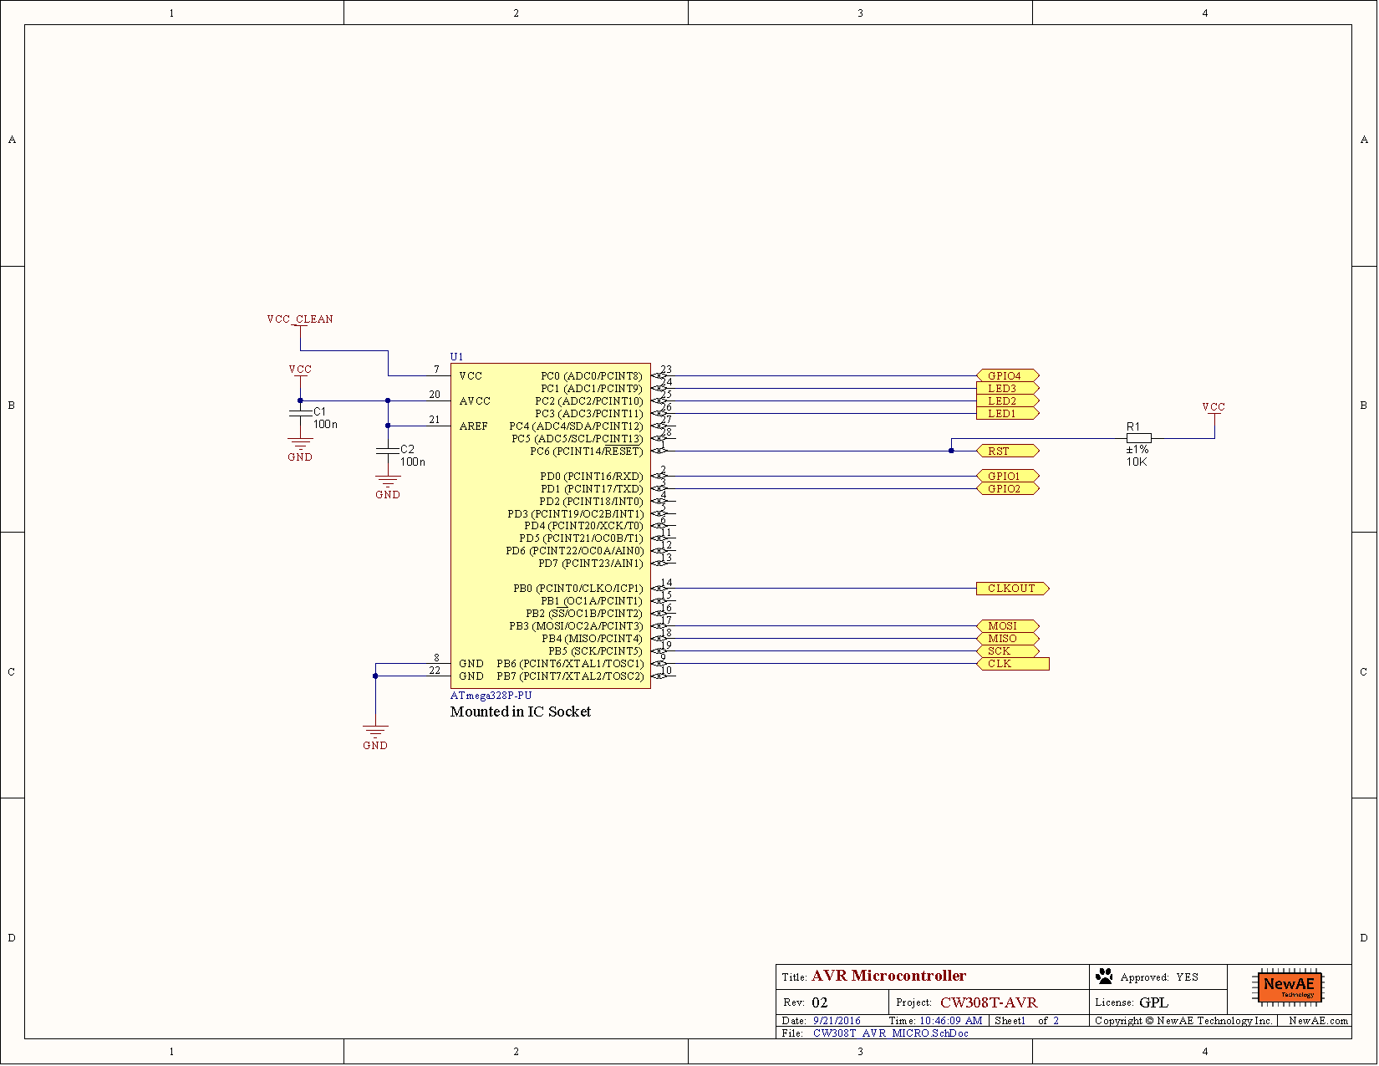
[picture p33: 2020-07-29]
CW308T_AVR/Images/CW308T_AVR_Schematic_Page_1.png

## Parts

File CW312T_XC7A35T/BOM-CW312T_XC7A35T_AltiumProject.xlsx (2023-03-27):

Line # | Name | Description | Designator | Revision ID | Revision State | Revision Status | Quantity | Manufacturer 1 | Manufacturer Part Number 1 | Manufacturer Lifecycle 1 | Supplier 1 | Supplier Part Number 1 | Supplier Unit Price 1 | Supplier Subtotal 1
 | DNM | DNM | C1, C2 |  | Not managed |  | 0
 | 100n | 100n, 0603 | C3, C4 |  | Not managed |  | 2 | Kemet | C0603C104K5RAC7867 |  | Digi-Key | 399-5089-2-ND
 | 2u2 | 2u2, 0603 | C5, C6, C7, C8, C9, C10, C18, C22, C23, C25, C26 |  | Not managed |  | 11 | Samsung | CL10B225KP8NNNC | Volume Production | Digi-Key | 1276-1134-2-ND | 0.01711 | 68.44
 | 100n | 100n, 0402 | C11, C12, C13, C14, C15, C16, C17, C19, C20, C21, C24, C27 |  | Not managed |  | 12 | TDK | CGA2B3X7R1V104K050BB | Unknown | Digi-Key | 445-6901-1-ND | 0.093 | 1.12
 | LED, 0603, Red | Chip LED, Red | D1, D2 |  | Not managed |  | 2 |  | APT1608SURCK |  | Digi-Key | 754-1123-1-ND
 | 87832-1420/XILINXJTAG | Molex 14-pin SMD, JTAG Pinout | J1 |  | Not managed |  | 1 | Molex | 87832-1420 | Unknown | Digi-Key | WM18641-ND | 2.24 | 2.24
 | 47n | FIXED IND 47NH 380MA 290 MOHM | L1 |  | Not managed |  | 1 | Murata | LQW18AN47NJ00D | Volume Production | Digi-Key | 490-6895-1-ND | 0.16 | 0.16
 | 4-40 MH, Tight Fit | Machine screw 4-40 Mounting Hole | MH1, MH2 |  | Not managed |  | 2
 | 4R7 | 4R7 res, 0603, 1%, 1/10W | R1 |  | Not managed |  | 1 | Yageo | RC0603FR-074R7L | Unknown | Digi-Key | YAG3371CT-ND | 0.1 | 0.1
 | 10R | 10R res, 0603, 1%, 1/10W | R2, R7, R8 |  | Not managed |  | 3 | Yageo | RC0603FR-0710RL | Unknown | Digi-Key | 311-10.0HRCT-ND | 0.1 | 0.3
 | DNM RCHIP | Do Not Mount Resistor | R9, R10, R11, R12, R13, R14, R21 |  | Not managed |  | 7
 | 4k7 | 4k7 res, 0603, 1%, 1/10W | R15, R16, R17 |  | Not managed |  | 3 | Yageo | RC0603FR-074K7L | Unknown | Digi-Key | 311-4.70KHRCT-ND | 0.019 | 0.19
 | 1k | 1k res, 0603, 1%, 1/10W | R18, R19, R29 |  | Not managed |  | 3 | Yageo | RC0603FR-071KL | Unknown | Digi-Key | 311-1.00KHRCT-ND | 0.019 | 0.19
 | 10k | 10k res, 0603, 1%, 1/10W | R20 |  | Not managed |  | 1 | Yageo | RC0603FR-0710KL | Volume Production | Digi-Key | 311-10.0KHRCT-ND | 0.1 | 0.1
 | 5k6 | 5k6 res, 0603, 1%, 1/10W | R22 |  | Not managed |  | 1 | Yageo | RC0603FR-075K6L | Volume Production | Digi-Key | 311-5.60KHRCT-ND | 0.1 | 0.1
 | 15k | 15k res, 0603, 1%, 1/10W | R23 |  | Not managed |  | 1 | Yageo | RC0603FR-0715KL | Volume Production | Digi-Key | 311-15.0KHRCT-ND | 0.1 | 0.1
 | 0R5 | 0R500 res, 0603, 1%, 1/10W | R28 |  | Not managed |  | 1 | Yageo | RL0603FR-070R5L | Volume Production | Digi-Key | 311-.5QCT-ND | 0.28 | 0.28
 | A6H-8101-PM | SWITCH SLIDE DIP SPST 25MA 24V | SW1 | CMP-08827-000045-1 | New From Design | Up to date | 1 | Omron | A6H8101PM | Volume Production | Mouser | 653-A6H-8101-PM | 4.15 | 4.15
 | XC7A35T-1CSG324C | Artix-7 FPGA, 210 User I/Os, 0 GTP, 324-Ball BGA, Speed Grade 1, Commercial Grade, Pb-Free | U1 | CMP-0383-00012-1 | Released | Up to date | 1 | Xilinx | XC7A35T-1CSG324C | Volume Production | Mouser | 217-XC7A35T-1CSG324C | 55.72 | 55.72
 | AP7361C-Y5-13 | Regulator, Adj, LDO, 1A | U2 |  | Not managed |  | 1 | Diodes | AP7361C-Y5-13 | Volume Production | Digi-Key | AP7361C-Y5-13DICT-ND | 0.61 | 0.61

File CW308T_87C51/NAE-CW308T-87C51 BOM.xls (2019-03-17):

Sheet: BOM Report
Bill of Materials |  |  | Bill of Materials For CW308T-87C51-02
Source Data From: |  | CW308T_87C51.PrjPcb
Project: |  | NAE-CW308T-87C51-02
Variant:
Creation Date: | 11/03/2017 | 10:12:52 PM
Print Date: | 2017-03-14 | 16:06:04
Production Quantity: | 1
Currency
 | Designator | Quantity | Description | Comment | Mount Type | Package | P/N | Manufacture | Supplier 1 | Supplier 1 P/N | NOTES
 | C1, C2, C4, C5, C8 | 6 | 100nF creramic capacitor | approved sub OK | SMD/BOT | 0603 |  |  | Bittele
 | C6, C7 | 2 | 22pF, 5%, ceramic capacitor | 22pF, sub OK | SMD/BOT | 0603 |  |  | Bittele
 | J1, J2, J3, J4, J5, J6, J7 | 7 | 1x3 pin header | 68000-203HLF | TOP | 0.1" header | 68000-203HLF |  | Digi-Key | 609-3464-ND
 | J8, J9 | 2 | 1x20 pin header | 68000-220HLF | TOP | 0.1" header | 68000-220HLF |  | Digi-Key | 609-5100-ND
 | J10 | 3 | 1x20 pin header | 68000-220HLF | BOTTOM | 0.1" header | 68000-220HLF |  | Digi-Key | 609-5100-ND | Three 20-pin strips mounted from UNDERSIDE, outside three rectanges. See assembly notes.
 | J12 | 1 | 1x2 pin header | 68000-202HLF | TOP | 0.1" header | 68000-202HLF |  | Digi-Key | 609-3502-ND
 | R1, R2, R3, R4, R5, R6, R7, R8, R9, R10, R11, R12, R15, R16, R17, R18, R19 | 17 | 10k, 10% chip resistor | Thick Film | SMD/BOT | 0603 |  |  | Bittele
 | R13, R14 | 2 | 51R, 10% chip resistor | Thick Film | SMD/BOT | 0603 |  |  | Bittele
 | U1 | 1 | PLCC-44 Socket |  | TOP | PLC44 Socket | 8444-11B1-RK-TP | 3M | Digi-Key | 3M4411B1-ND
 | U3 | 1 | 8-bit AVR Microcontroller, 1.5-5.5V, 32KB Flash, 1KB EEPROM, 2KB SRAM, 64-pin TQFP, Industrial Grade (-40°C to 85°C) | ATmega325PA-AU | SMD/TOP | TQFP64 | ATmega325PA-AU | Atmel | Mouser | 556-ATMEGA325PA-AU | Only SMD part on top-side.
 | X1 | 1 | Ceramic Surface Mount Low Profile Quartz Crystal, 8 MHz, -20 to 70 degC, 4-Pin 6 x 3.6 x 1.2 mm SMD, RoHS, 1000pcs / Reel | ABMM2-7.3728MHZ-E2-T | SMD/BOT | 3.6 x 1.2 mm | ABMM2-7.3728MHZ-E2-T | Abracon LLC | Digi-Key | 535-10157-1-ND
 | SJ1 | 0 | Solder Jumper - SHORTED BY SOLDERMASK |  |  |  |  |  |  |  | Solder Jumper - SHORTED BY SOLDERMASK
 | J11 | 0 | NOT MOUNTED |  |  |  |  |  |  |  | NOT MOUNTED
 | C3 | 0 | NOT MOUNTED |  |  |  |  |  |  |  | NOT MOUNTED
 |  | 43
Approved |  | Notes

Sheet: Project Information
Project Full Path | C:\Users\colin\Dropbox (NewAE Technology Inc)\engineering\git_repos\CW308T\CW308T_87C51\CW308T_87C51.PrjPcb
Project Filename | CW308T_87C51.PrjPcb
Variant Name | None
Data-Source Filename | CW308T_87C51.PrjPcb
Data-Source Full Path | C:\Users\colin\Dropbox (NewAE Technology Inc)\engineering\git_repos\CW308T\CW308T_87C51\CW308T_87C51.PrjPcb
Title | Bill of Materials For Project [CW308T_87C51.PrjPcb] (No PCB Document Selected)
Total Quantity | 42
Report Time | 10:12:52 PM
Report Date | 11/03/2017
Report Date & Tine | 11/03/2017 10:12:52 PM
Output Name | Bill of Materials
Output Type | BOM_PartType
Output Generator Name | BOM
Output Generator Description | Bill of Materials

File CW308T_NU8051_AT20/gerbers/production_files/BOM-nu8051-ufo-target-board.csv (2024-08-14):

Comment | Designator | Footprint | LCSC
100R | R1 | R_0805_2012Metric_Pad1.20x1.40mm_HandSolder | C17408
10K | R3 | R_0805_2012Metric_Pad1.20x1.40mm_HandSolder | C17414
51R | R2 | R_0805_2012Metric_Pad1.20x1.40mm_HandSolder | C17738
100nF | C1 | C_0805_2012Metric_Pad1.18x1.45mm_HandSolder | C49678
N76E003AT20 | U1 | SOP65P640X120-20N | C82751
CW308T_CONNBOARD | J1 | CW308T_CONNBOARD
Jumper_2_Open | JP1 | PinHeader_2x03_P2.54mm_Vertical
SolderJumper_2_Open | JP2 | SolderJumper-2_P1.3mm_Open_RoundedPad1.0x1.5mm

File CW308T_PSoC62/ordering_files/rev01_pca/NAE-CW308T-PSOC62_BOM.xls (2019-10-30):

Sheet: BOM Report
Bill of Materials |  |  | Bill of Materials for Project [CW308T_PSoC62.PrjPcb] (PCB Document : CW308T_PSoC62.PcbDoc)
Source Data From: |  | CW308T_PSoC62.PrjPcb
Project: |  | CW308T_PSoC62.PrjPcb
Variant: |  | None
Creation Date: | 2019-10-29 | 9:52 PM
Print Date: | 2019-10-29 | 22:00:53
Production Quantity: | 1
Currency | <none>
 | Designator | Quantity | Description | Comment | Manufacture 1 | Manufacture Part Number 1 | Footprint | LibRef | Supplier 1 | Supplier Part Number 1 | Supplier Unit Price 1 | Supplier Order Qty 1 | Supplier Subtotal 1
 | C1, C2, C4, C5, C7, C8, C9, C10, C14 | 9 | 100n, 0603 | 100n | Kemet | C0603C104K5RACTU | CAPC0603_M | CCHIP-100n-0603 | Digi-Key | 399-5089-2-ND
 | C3 | 0 | Do Not Mount | DNM |  |  | CAPC0603_M | CCHIP-DNM-0603
 | C6, C11, C12, C13 | 4 | 2u2, 0603 | 2u2 | Samsung | CL10B225KP8NNNC | CAPC0603_M | CCHIP-2u2-0603 | Digi-Key | 1276-1134-2-ND
 | J1 | 0 | Do Not Mount | DNM |  |  | CW308_TBOARD_CONN | CW308_TBOARD
 | R1 | 1 | 10R res, 0603, 1%, 1/10W | 10R | Yageo | RC0603FR-0710RL | RESC1608X55N | RCHIP-10R-0603 | Digi-Key | 311-10.0HRCT-ND
 | R2 | 1 | 22R res, 0603, 1%, 1/10W | 22R | Yageo | RC0603FR-0722RL | RESC1608X55N | RCHIP-22R-0603 | Digi-Key | 311-22.0HRCT-ND
 | R3 | 1 | 100R res, 0603, 1%, 1/10W | 100R | Yageo | RC0603FR-07100RL | RESC1608X55N | RCHIP-100R-0603 | Digi-Key | 311-100HRCT-ND
 | U1 | 1 | IC DUAL CORE MCU 32B 512K 124BGA | CY8C6247BZI-D44 | Cypress Semiconductors | CY8C6247BZI-D44 | BGA124C65P13X13_900X900X100 | CY8C6247BZI-D44 | Digi-Key | 428-4587-ND
 |  | 17 |  |  |  |  |  |  |  |  |  |  | $0.00
Approved |  | Notes

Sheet: Project Information
Project Full Path | C:\Users\Colin\Dropbox (NewAE Technology Inc)\engineering\hardware_targets\chipwhisperer-target-cw308t\CW308T_PSoC62\altium_src\CW308T_PSoC62.PrjPcb
Project Filename | CW308T_PSoC62.PrjPcb
Variant Name | None
Data-Source Filename | CW308T_PSoC62.PrjPcb
Data-Source Full Path | C:\Users\Colin\Dropbox (NewAE Technology Inc)\engineering\hardware_targets\chipwhisperer-target-cw308t\CW308T_PSoC62\altium_src\CW308T_PSoC62.PrjPcb
Title | Bill of Materials for Project [CW308T_PSoC62.PrjPcb] (PCB Document : CW308T_PSoC62.PcbDoc)
Total Quantity | 19
Report Time | 9:52 PM
Report Date | 2019-10-29
Report Date & Tine | 2019-10-29 9:52 PM
Output Name | Bill of Materials
Output Type | BOM_PartType
Output Generator Name | BOM
Output Generator Description | Bill of Materials

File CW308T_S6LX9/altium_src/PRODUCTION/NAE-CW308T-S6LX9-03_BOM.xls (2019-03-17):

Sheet: BOM Report
Bill of Materials |  |  | CW308 Connections
Source Data From: |  | CW308T_S6LX9.PrjPcb
Project: |  | CW308T_S6LX9.PrjPcb
Variant: |  | Normal Build
Creation Date: | 13/11/2018 | 11:52:15 AM
Print Date: | 2018-11-13 | 14:27:01
Production Quantity: | 1
Currency | <none>
 | Designator | Quantity | Description | Comment | Supplier PN | Supplier 1 | Supplier Part Number 1 | Detailed comment / sub list
 | C15 | 1 | Capacitor SMD Cer 2u2, 0603, 16V | sub OK | CL10B225KP8NNNC | Digi-Key | 1276-1134-2-ND
 | C16 | 1 | Capacitor SMD Cer 2u2, 0603, 16V | sub OK | CL10B225KP8NNNC | Digi-Key | 1276-1134-2-ND
 | C20 | 1 | Capacitor SMD Cer 2u2, 0603, 16V | sub OK | CL10B225KP8NNNC | Digi-Key | 1276-1134-2-ND
 | C21 | 1 | Capacitor SMD Cer 2u2, 0603, 16V | sub OK | CL10B225KP8NNNC | Digi-Key | 1276-1134-2-ND
 | R14 | 1 | 330R res, 0603, 1%, 1/10W | sub OK |  | Digi-Key | 311-330HRCT-ND
 | C1 | 1 | Capacitor SMD Cer 100nF 10% 50V X7R 0603 | sub OK |  | Digi-Key | 478-5052-1-ND (https://octopart-clicks.com/click/altium?sku=478-5052-1-ND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)
 | C2 | 1 | Capacitor SMD Cer 100nF 10% 50V X7R 0603 | sub OK |  | Digi-Key | 478-5052-1-ND (https://octopart-clicks.com/click/altium?sku=478-5052-1-ND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)
 | C3 | 1 | Capacitor SMD Cer 100nF 10% 50V X7R 0603 | sub OK |  | Digi-Key | 478-5052-1-ND (https://octopart-clicks.com/click/altium?sku=478-5052-1-ND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)
 | C4 | 1 | Capacitor SMD Cer 100nF 10% 50V X7R 0603 | sub OK |  | Digi-Key | 478-5052-1-ND (https://octopart-clicks.com/click/altium?sku=478-5052-1-ND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)
 | C5 | 1 | Capacitor SMD Cer 100nF 10% 50V X7R 0603 | sub OK |  | Digi-Key | 478-5052-1-ND (https://octopart-clicks.com/click/altium?sku=478-5052-1-ND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)
 | C6 | 1 | Capacitor SMD Cer 100nF 10% 50V X7R 0603 | sub OK |  | Digi-Key | 478-5052-1-ND (https://octopart-clicks.com/click/altium?sku=478-5052-1-ND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)
 | C7 | 1 | Capacitor SMD Cer 100nF 10% 50V X7R 0603 | sub OK |  | Digi-Key | 478-5052-1-ND (https://octopart-clicks.com/click/altium?sku=478-5052-1-ND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)
 | C8 | 1 | Capacitor SMD Cer 100nF 10% 50V X7R 0603 | sub OK |  | Digi-Key | 478-5052-1-ND (https://octopart-clicks.com/click/altium?sku=478-5052-1-ND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)
 | C13 | 1 | Capacitor SMD Cer 100nF 10% 50V X7R 0603 | sub OK |  | Digi-Key | 478-5052-1-ND (https://octopart-clicks.com/click/altium?sku=478-5052-1-ND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)
 | C14 | 1 | Capacitor SMD Cer 100nF 10% 50V X7R 0603 | sub OK |  | Digi-Key | 478-5052-1-ND (https://octopart-clicks.com/click/altium?sku=478-5052-1-ND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)
 | C17 | 0 | DO NOT MOUNT
 | C18 | 1 | Capacitor SMD Cer 100nF 10% 50V X7R 0603 | sub OK |  | Digi-Key | 478-5052-1-ND (https://octopart-clicks.com/click/altium?sku=478-5052-1-ND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)
 | C19 | 1 | Capacitor SMD Cer 100nF 10% 50V X7R 0603 | sub OK |  | Digi-Key | 478-5052-1-ND (https://octopart-clicks.com/click/altium?sku=478-5052-1-ND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)
 | J1 | 0 | DO NOT MOUNT
 | D1 | 1 | Chip LED, Red | sub OK | APT1608SRCPRV | Digi-Key | 754-1122-1-ND
 | U2 | 0 | DO NOT MOUNT
 | R1 | 1 | Resistor SMD chip 1 Ohm 0.1W 5% 0603 | sub OK |  | Digi-Key | 311-1.0GRTR-ND (https://www.digikey.com/product-detail/en/yageo/RC0603JR-071RL/311-1.0GRTR-ND/726676)
 | R2 | 0 | DO NOT MOUNT
 | R3 | 1 | Resistor SMD chip 1k Ohm 0.1W 5% 0603 | sub OK |  | Digi-Key | 311-1.0KGRCT-ND (https://octopart-clicks.com/click/altium?sku=311-1.0KGRCT-ND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)
 | R4 | 1 | Resistor SMD chip 1k Ohm 0.1W 5% 0603 | sub OK |  | Digi-Key | 311-1.0KGRCT-ND (https://octopart-clicks.com/click/altium?sku=311-1.0KGRCT-ND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)
 | R5 | 1 | Resistor SMD chip 1k Ohm 0.1W 5% 0603 | sub OK |  | Digi-Key | 311-1.0KGRCT-ND (https://octopart-clicks.com/click/altium?sku=311-1.0KGRCT-ND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)
 | R6 | 1 | Resistor SMD chip 1k Ohm 0.1W 5% 0603 | sub OK |  | Digi-Key | 311-1.0KGRCT-ND (https://octopart-clicks.com/click/altium?sku=311-1.0KGRCT-ND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)
 | R8 | 1 | Resistor SMD chip 1k Ohm 0.1W 5% 0603 | sub OK |  | Digi-Key | 311-1.0KGRCT-ND (https://octopart-clicks.com/click/altium?sku=311-1.0KGRCT-ND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)
 | R9 | 1 | Resistor SMD chip 1k Ohm 0.1W 5% 0603 | sub OK |  | Digi-Key | 311-1.0KGRCT-ND (https://octopart-clicks.com/click/altium?sku=311-1.0KGRCT-ND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)
 | R12 | 1 | Resistor SMD chip 51 Ohm 0.1W 1% 0603 | sub OK |  | Digi-Key | 311-51.0HRCT-ND (https://octopart-clicks.com/click/altium?sku=311-51.0HRCT-ND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)
 | R13 | 1 | Resistor SMD chip 51 Ohm 0.1W 1% 0603 | sub OK |  | Digi-Key | 311-51.0HRCT-ND (https://octopart-clicks.com/click/altium?sku=311-51.0HRCT-ND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)
 | U1 | 1 | Spartan-6 LX 1.0V FPGA, 102 User I/Os, 144-Pin TQFP (0.5mm Pitch), Low Power Version, Commercial Grade, Pb-Free | See sub list. | XC6SLX9-2TQG144 |  |  | XC6SLX9-2TQG144C, 'XC6SLX9-2TQG144I, 'XC6SLX9-3TQG144C, 'XC6SLX9-3TQG144I all OK subs. Low-cost preferred.
 | C9 | 0 | DO NOT MOUNT
 | C10 | 0 | DO NOT MOUNT
 | C11 | 0 | DO NOT MOUNT
 | C12 | 0 | DO NOT MOUNT
 | R7 | 0 | DO NOT MOUNT
 | R10 | 0 | DO NOT MOUNT
 | R11 | 0 | DO NOT MOUNT
 |  | 28
Approved |  | Notes

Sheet: Project Information
Project Full Path | C:\Users\colin\dropbox\engineering\git_repos\CW308T\CW308T_S6LX9\CW308T_S6LX9.PrjPcb
Project Filename | CW308T_S6LX9.PrjPcb
Variant Name | Normal Build
Data-Source Filename | CW308T_S6LX9.PrjPcb
Data-Source Full Path | C:\Users\colin\dropbox\engineering\git_repos\CW308T\CW308T_S6LX9\CW308T_S6LX9.PrjPcb
Title | CW308 Connections
Total Quantity | 32
Report Time | 11:52:15 AM
Report Date | 13/11/2018
Report Date & Tine | 13/11/2018 11:52:15 AM
Output Name | Bill of Materials
Output Type | BOM_PartType
Output Generator Name | BOM
Output Generator Description | Bill of Materials

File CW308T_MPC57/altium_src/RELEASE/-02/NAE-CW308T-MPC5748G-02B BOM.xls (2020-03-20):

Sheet: BOM Report
Bill of Materials |  |  | NAE-CW308T-MPC5748G-02
Source Data From: |  | CW308T_MPC57.PrjPcb
Project: |  | CW308T_MPC57.PrjPcb
Variant: |  | HSM or NHSM
Creation Date: | 14/03/2017 | 4:53:14 PM
Print Date: | 2017-03-22 | 13:50:07
Production Quantity: | 1
Currency
 | Designator | Quantity | Description | Comment | Manufacture 1 | Manufacture Part Number 1 | Footprint | Mount Type | Supplier 1 | Supplier Part Number 1 | NOTE
 | C1, C4, C5, C8, C16, C17, C26, C27, C28, C29, C31, C32 | 12 | 2u2, 0603 | 2u2 | Murata | GRM188R71A225KE15D | 0603 | SMD | Digi-Key | 490-4520-1-ND
 | C2, C3, C6, C7, C9, C10, C11, C12, C13, C14, C15, C19, C20, C21, C22, C23, C24, C25, C30, C33 | 20 | 100n, 0402 | 100n | Murata | GRM155R71C104KA88D | 0402 | SMD | Bitelle
 | C18 | 1 | 1u, 0603 | 1u | Murata | GRM188R71C105KE15D | 0603 | SMD | Bitelle
 | D1, D2, D3, D4, D5 | 5 | Chip LED, Green | LED, 0603, Green | Kingbright | APT1608CGCK | LED-0603-GREEN | SMD | Digi-Key | 754-1116-1-ND
 | D6, D7, D8, D9 | 4 | Chip LED, Red | LED, 0603, Red | Kingbright | APT1608SRCPRV | LED-0603-RED | SMD | Digi-Key | 754-1122-1-ND
 | J1 | 3 | 68000-220HLF | 0.1" header, 3 locations | Amp/FCI | 68000-220HLF | 0.1", 20-pin | BOTTOM | Digi-Key | 609-5100-ND
 | J2 | 1 | DB9 R/A Connector, Through-hole, Male |  | Assmann WSW | A-DS 09 A/KG-T2S | DB9, R/A | TOP | Digi-Key | AE10968-ND | P/N Change from -02
 | J3, J4 | 2 | 68000-204HLF |  | Amp/FCI | 68000-204HLF | 0.1", 4-pin | TOP | Digi-Key | 609-3255-ND
 | R1 | 1 | 10R res, 0603, 1%, 1/10W | 10R | Vishay Dale | CRCW060310R0FKEA | 0603 | SMD | Bitelle
 | R2, R4 | 2 | 4k7 res, 0603, 1%, 1/10W | 4k7 | Vishay Dale | CRCW06034K70FKEA | 0603 | SMD | Bitelle
 | R3, R5 | 2 | 120R res, 0603, 1%, 1/10W | 120R | Vishay Dale | CRCW0603120RFKEA | 0603 | SMD | Bitelle
 | R6, R7, R8, R9, R10, R11, R12, R13, R14, R17 | 10 | 1k res, 0603, 1%, 1/10W | 1k | Vishay Dale | CRCW06031K00FKEA | 0603 | SMD | Bitelle
 | R15, R16, R24, R25 | 4 | 10k res, 0603, 1%, 1/10W | 10k | Vishay Dale | CRCW060310K0FKEA | 0603 | SMD | Bitelle
 | R18, R19, R21 | 3 | 22R res, 0603, 1%, 1/10W, 22R res, 0603, 1%, 1/10W, 120R res, 0603, 1%, 1/10W | 22R | Vishay Dale | CRCW060322R0FKEA | 0603 | SMD | Bitelle
 | R20 | 1 | 470R res, 0603, 1%, 1/10W | 470R | Vishay Dale | CRCW0603470RFKEA | 0603 | SMD | Bitelle
 | R22 | 1 | 1R0 res, 0805, 1%, 1/8W | 1R0 | Vishay Dale | CRCW08051R00FKEA | 0805 | SMD | Bitelle
 | R23 | 1 | 1R0 res, 0603, 1%, 1/10W | 1R0 | Vishay Dale | CRCW06031R00FKEA | 0603 | SMD | Bitelle
 | U1 | 1 | Freescale 32-bit MCU, Triple core, 6MB Flash, 160MHz, -40/+125degC, Automotive Qualified, BGA 256 | SPC5748GSK1MMJ6 | NXP | SPC5748GSK1MMJ6 | BGA-256 | SMD | Arrow Electronics |  | VARIANT: HSM
 | U1 | 1 | Freescale 32-bit MCU, Triple core, 6MB Flash, 160MHz, -40/+125degC, Automotive Qualified, BGA 256 | SPC5748GGK1MMJ6 | NXP | SPC5748GGK1MMJ6 | BGA-256 | SMD | Arrow Electronics |  | VARIANT: NOHSM
 | U2, U3 | 2 | CAN-FD Transceiver, 3.3V | TJA1051T/3 | NXP | TJA1051T/3 | SOIC8_NARROW | SMD | Digi-Key | 568-8684-1-ND (https://octopart-clicks.com/click/altium?sku=568-8684-1-ND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)
 | U4 | 1 | 2.93V Reset Controller, 112mS | STM6315RDW13F | ST Microelectronics | STM6315RDW13F | SOT143B | SMD | Digi-Key | 497-5127-1-ND (https://octopart-clicks.com/click/altium?sku=497-5127-1-ND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)
 | U5 | 1 | Adjustable Low Drop Voltage Regulator, 1.25 to 15V, 4-Pin SOT-223, Tape and Reel | LD1117STR | ST Microelectronics | LD1117STR | SOT-223_L | SMD | Digi-Key | 497-1244-1-ND (https://octopart-clicks.com/click/altium?sku=497-1244-1-ND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)
 |  | 79 |  |  |  |  |  |  |  |  |  | $0.00
Approved |  | Notes
 |  | U1 has two possible part numbers

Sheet: Project Information
Project Full Path | C:\Users\colin\Dropbox (NewAE Technology Inc)\engineering\git_repos\CW308T\CW308T_MPC57\altium_pcbproject\CW308T_MPC57.PrjPcb
Project Filename | CW308T_MPC57.PrjPcb
Variant Name | None
Data-Source Filename | CW308T_MPC57.PrjPcb
Data-Source Full Path | C:\Users\colin\Dropbox (NewAE Technology Inc)\engineering\git_repos\CW308T\CW308T_MPC57\altium_pcbproject\CW308T_MPC57.PrjPcb
Title | CAN Transceivers
Total Quantity | 76
Report Time | 4:53:14 PM
Report Date | 14/03/2017
Report Date & Tine | 14/03/2017 4:53:14 PM
Output Name | Bill of Materials
Output Type | BOM_PartType
Output Generator Name | BOM
Output Generator Description | Bill of Materials

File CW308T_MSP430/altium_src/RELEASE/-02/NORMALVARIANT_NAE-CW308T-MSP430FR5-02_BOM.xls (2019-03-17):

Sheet: BOM Report
Bill of Materials |  |  | Bill of Materials For Project [CW308T_MSP430FR5xxx.PrjPcb] (No PCB Document Selected)
Source Data From: |  | CW308T_MSP430FR5xxx.PrjPcb
Project: |  | CW308T_MSP430FR5xxx.PrjPcb
Variant: |  | None
Creation Date: | 20/03/2017 | 12:14:58 PM
Print Date: | 2017-03-20 | 15:51:21
Production Quantity: | 1
Currency | <none>
 | Designator | Quantity | Description | Comment | Manufacture 1 | Manufacture Part Number 1 | Footprint | Mount Type | Supplier 1 | Supplier Part Number 1 | NOTE
 | C1, C3, C3 | 3 | Capacitor SMD Cer 100nF 10% 50V X7R 0603 | approved sub OK | Murata | GRM188R71C104KA01D | 0603 | SMD | Bitelle
 | J1, J1, J1 | 3 | 68000-220HLF | 0.1" header, 3 locations | Amp/FCI | 68000-220HLF | 0.1", 20-pin | BOTTOM | Digi-Key | 609-5100-ND
 | J2, J4 | 0 | DNM
 | J3 | 0 | DNM
 | R1 | 1 | Resistor SMD chip 5.1 Ohm 0.1W 1% 0603 | Thick Film | Vishay Dale | CRCW06035R10FKEA | 0603 | SMD | Bitelle
 | R2, R5 | 2 | Resistor SMD chip 120 Ohm 0.1W 1% 0603 | Thick Film | Vishay Dale | CRCW0603120RFKEA | 0603 | SMD | Bitelle
 | R3 | 1 | Resistor SMD chip 4.7k Ohm 0.1W 5% 0603 | Thick Film | Vishay Dale | CRCW06034K70FKEA | 0603 | SMD | Bitelle
 | R4 | 0 | DNM
 | U1 | 1 | MSP430, 16-bit MCU, FR sram | MSP430FR5969 | Texas Instruments | MSP430FR5969IRGZR | QFN48 | SMD | Digi-Key | 296-37875-1-ND
 |  | 11
Approved |  | Notes

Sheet: Project Information
Project Full Path | C:\Users\colin\Dropbox (NewAE Technology Inc)\engineering\git_repos\CW308T\CW308T_MSP430\CW308T_MSP430FR5xxx.PrjPcb
Project Filename | CW308T_MSP430FR5xxx.PrjPcb
Variant Name | None
Data-Source Filename | CW308T_MSP430FR5xxx.PrjPcb
Data-Source Full Path | C:\Users\colin\Dropbox (NewAE Technology Inc)\engineering\git_repos\CW308T\CW308T_MSP430\CW308T_MSP430FR5xxx.PrjPcb
Title | Bill of Materials For Project [CW308T_MSP430FR5xxx.PrjPcb] (No PCB Document Selected)
Total Quantity | 13
Report Time | 12:14:58 PM
Report Date | 20/03/2017
Report Date & Tine | 20/03/2017 12:14:58 PM
Output Name | Bill of Materials
Output Type | BOM_PartType
Output Generator Name | BOM
Output Generator Description | Bill of Materials

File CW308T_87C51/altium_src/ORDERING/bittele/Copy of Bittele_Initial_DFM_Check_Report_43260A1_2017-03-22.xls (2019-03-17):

 |  |  | Initial Design for Manufacturing Check Report |  |  |  |  |  |  |  | Form No:
 |  |  |  |  |  |  |  |  |  |  | BTL- DFM-001
Product # |  | Customer ID |  | Purchase Order | Quantity | Checked by |  |  | Audit by
 |  |  |  |  |  | Name | Date | Time (Hour) | Name | Date
43260A1 |  | 51798 |  | 2035 | 40 | Nishil | 2017-03-22
Gerber File |  |  |  | X-Y Coordinate File |  | Drill File |  | BOM check |  | Others
Quiz# | Question Description |  |  |  |  | Illustration |  |  |  |  | Client Reply
1 | #1_'C1, C2, C4, C5, C8 p/n:" Bittele Stock:GRM188R71C104KA01D" In the given bom there are 5 reference designator but the given quantity is 6. Please comment. |  |  |  |  |  |  |  |  |  | Qty 5 is correct. One DNM designator was removed from this list, but I forgot to update qty.
2 | #4_J8, J9 p/n: 68000-220HLF In gerber drill hit 0.88mm whereas in datasheet it is 1.02mm, considering the production tolerance please help to enlarge the drill size to 1.02mm. |  |  |  |  |  |  |  |  |  | The 1.02mm hole ends up making alignment difficult in my experience, if possible would prefer as designed.
3 | #5_J10 p/n: 68000-220HLF It has following issues given below:- 1) In gerber drill hit 0.88mm whereas in datasheet it is 1.02mm, considering the production tolerance please help to enlarge the drill size to 1.02mm. 2)In bom, the given quantity is 3, please confirm whether the arrow showing the correct place for other two parts. |  |  |  |  |  |  |  |  |  | The 1.02mm hole ends up making alignment difficult in my experience, if possible would prefer as designed. Location marked is correct (these headers mount from BOTTOM SIDE).

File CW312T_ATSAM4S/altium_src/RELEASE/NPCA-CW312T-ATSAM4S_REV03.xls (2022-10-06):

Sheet: BOM Report
Bill of Materials |  |  | Bill of Materials for Project [cw312_sam4s.PrjPcb] (PCB Document : cw312_sam4s.PcbDoc)
Source Data From: |  | cw312_sam4s.PrjPcb
Project: |  | cw312_sam4s.PrjPcb
Variant: |  | None
Creation Date: | 2022-10-04 | 1:34 PM
Print Date: | 2022-10-04 | 13:36:34
Production Quantity: | 1
Currency | <none>
 | Designator | Quantity | Description | Comment | Manufacture 1 | Manufacture Part Number 1 | Footprint | LibRef | Supplier 1 | Supplier Part Number 1 | Supplier Unit Price 1 | Supplier Order Qty 1 | Supplier Subtotal 1
 | C1, C2 | 0 | DNM | DNM | Kemet | C0603C104K5RACTU | CAPC0603_M | CCHIP-100n-0603 | Digi-Key | 399-5089-2-ND
 | C3, C4, C6, C7, C8, C14 | 6 | 100n, 0603 | 100n | Kemet | C0603C104K5RACTU | CAPC0603_M | CCHIP-100n-0603 | Digi-Key | 399-5089-2-ND
 | C5, C12, C13 | 3 | 2u2, 0603 | 2u2 | Samsung | CL10B225KP8NNNC | CAPC0603_M | CCHIP-2u2-0603 | Digi-Key | 1276-1134-2-ND
 | R1, R2, R5 | 3 | 10R res, 0603, 1%, 1/10W | 10R | Yageo | RC0603FR-0710RL | RESC1608X55N | RCHIP-10R-0603 | Digi-Key | 311-10.0HRCT-ND
 | R3 | 1 | 1k res, 0603, 1%, 1/10W | 1k | Yageo | RC0603FR-071KL | RESC1608X55N | RCHIP-1K-0603 | Digi-Key | 311-1.00KHRCT-ND
 | R4 | 1 | 100R res, 0603, 1%, 1/10W | 100R | Yageo | RC0603FR-07100RL | RESC1608X55N | RCHIP-100R-0603 | Digi-Key | 311-100HRCT-ND
 | U1 | 1 | ATSAM4S, 128KB FLASH, 48QFN | ATSAM4S2AA-MU | Microchip | ATSAM4S2AA-MU | QFN50P700X700X100_HS-49M | ATSAM4S2AA-MU | Digi-Key
 |  | 15 |  |  |  |  |  |  |  |  |  |  | $0.00
Approved |  | Notes

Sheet: Project Information
Project Full Path | C:\Users\colin\Dropbox (NewAE Technology Inc)\engineering\hardware_targets\chipwhisperer-target-cw308t\CW312T_ATSAM4S\altium_src\cw312_sam4s.PrjPcb
Project Filename | cw312_sam4s.PrjPcb
Variant Name | None
Data-Source Filename | cw312_sam4s.PrjPcb
Data-Source Full Path | C:\Users\colin\Dropbox (NewAE Technology Inc)\engineering\hardware_targets\chipwhisperer-target-cw308t\CW312T_ATSAM4S\altium_src\cw312_sam4s.PrjPcb
Title | Bill of Materials for Project [cw312_sam4s.PrjPcb] (PCB Document : cw312_sam4s.PcbDoc)
Total Quantity | 19
Report Time | 1:34 PM
Report Date | 2022-10-04
Report Date & Tine | 2022-10-04 1:34 PM
Output Name | Bill of Materials
Output Type | BomReport
Output Generator Name | BOM
Output Generator Description | Bill of Materials

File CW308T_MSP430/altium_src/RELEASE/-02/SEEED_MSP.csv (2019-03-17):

Part/Designator | Manufacture Part Number/Seeed SKU | Quantity
C1, C2, C3 | GRM188R71C104KA01D | 3
J1, J1, J1 | 68000-220HLF | 3
R1 | CRCW06035R10FKEA | 1
R2,R5 | CRCW0603120RFKEA | 2
R3 | CRCW06034K70FKEA | 1
U1 | MSP430FR5969IRGZR | 1

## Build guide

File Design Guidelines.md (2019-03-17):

# CW308 Target Design Guidelines #
## Schematic Guidelines ##
Template: 
Start with StandardSch_Letter_Template.SchDoc found in TARGET_TEMPLATE Use two schematic sheets for more complex designs, one with header connections and one for all others

Net Names:
Begin power net names with a sign, do not use decimal points (eg. +3v3, -5v)
Use GND as ground net, prepend letters for other grounds (eg. AGND, DGND)
Label all significant nets to aid in routing and readability

Wiring Schematic:
Avoid 4-way junctions is schematic, can create bad behavior in Altium, Minimize wire crossover
Attempt to organize parts into functional blocks on schematic sheets

Annotating Schematics:
Annotate components as you finish functional blocks, aid readability by starting in the upper-left corner
Set the project Name, license, and Revision by right clicking on the project>Project Options>Parameters
Revisions start at -01
Title sheets by right-clicking in the sheet >Options>Document Parameters
Number sheets by clicking tools>Annotation>Number Schematic Sheets

## PCB Layout ##
Template:
Start with NewAE_PCB_Target_Template.PcbDoc found in TARGET_TEMPLATE
Board size should already be correct (2055x2540mil) and basic design rules configured

Component placement:
Place components beginning with the main connector headers (align at bottom of board)
Place main chip while thinking about the following priorities
1.	Power measurement, sense lines should be uncrowded and not change layers
2.	UART and JTAG should be easy to route if possible
3.	Keep clock lines isolated if at all possible

Must-Have checklist:
•	Power in, core voltage through filter
•	Clock in (including termination resistor)
•	Power measurement, low noise routing
•	Serial connection
•	Trigger (gpio) on GPIO4
•	Bootloader enable on PDIC (if valid)
•	JTAG/SWD interface
•	All GND and Vref connections to UFO board

If possible checklist:
•	GPIO pins out to LEDs
•	Special interfaces like USB, RF
•	Extra GPIO out to H pins

Silkscreen:
Place component designator to be read from left-to-right or bottom-to-top
Favor designator placement above or to the right of the component
Favor designator placement that aligns with the component
Label breakout pins as corresponding pins on the chip (ie. PA01 for a GPIO)

## Panelization ##
Template:
Start with Target_Panel_Template.PcbDoc found in TARGET_TEMPLATE

Board Array:
Double click the board array object and link to the target board PCB3
Space the boards 5mils apart horizontally and vertically
If everything is sized correctly vscore lines should be equidistant to all board edges 
IF NOT, board is probably different size. Adjust spacing to correct

## Production Files ##
Variants:
If board has optional components, create a production variant (Project>Variants>Add Variant)
Change optional components to Not Fitted on production variant
Ensure changes are pushed to PCB and Panel

Outjob:
Start with newae_outjob.OutJob found in Dropbox>CW308T>TARGET_TEMPLATE
Select production variant
Select PCB file as the source for the Gerber, NC Drill, and IPC-2581 outputs
Select Panel file as the source for both panel outputs
Generate content

File Packaging:
From output folder, copy all gerber files (with extensions beginning with G) to new folder named after the board revision (eg. -01)
From output folder, copy the NC drill files to the new folder, change extension to .NCDRILL

Copy README.txt from TARGET_TEMPLATE to new folder, verify it is correct
Zip up contents of folder
Zip up just the .GTP file as the stencil source

**WATCH FOR 4-LAYER PCBS - DEFAULT OUTJOB AND README DO NOT INCLUDE THESE FILES**

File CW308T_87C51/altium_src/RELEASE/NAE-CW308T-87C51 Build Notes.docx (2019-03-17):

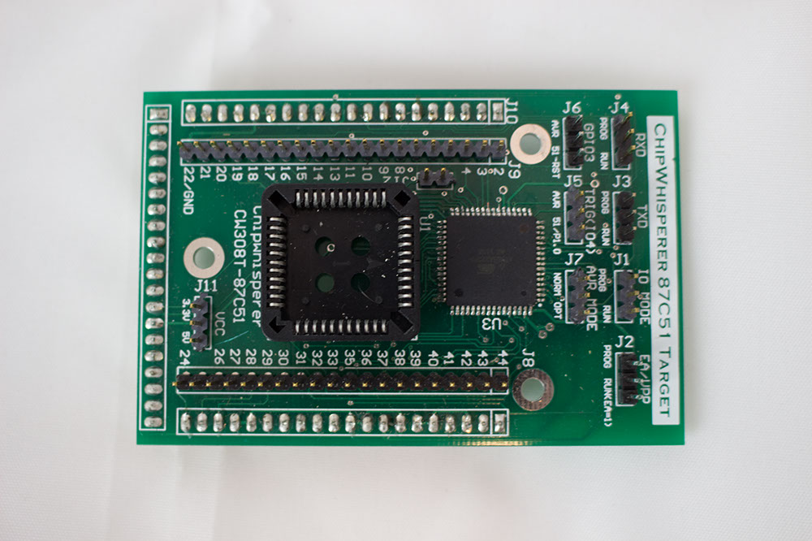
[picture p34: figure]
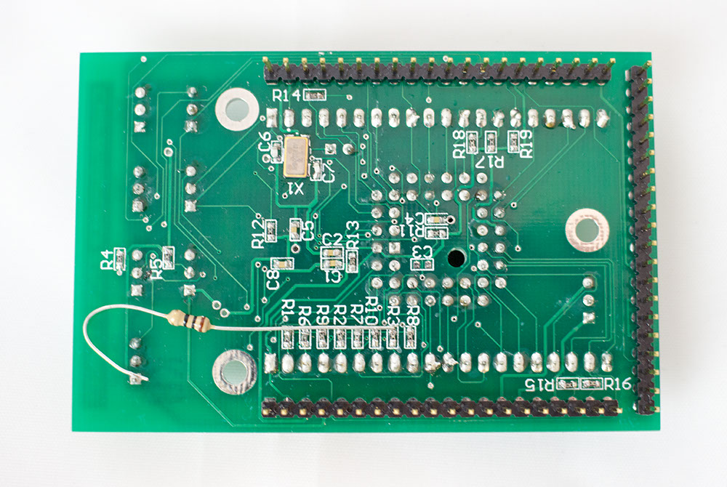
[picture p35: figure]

This fix not needed in final version

C3 not mounted

J11 not mounted

NAE-CW308T-87C51-01 Build Instructions. Date: 14/March/2017

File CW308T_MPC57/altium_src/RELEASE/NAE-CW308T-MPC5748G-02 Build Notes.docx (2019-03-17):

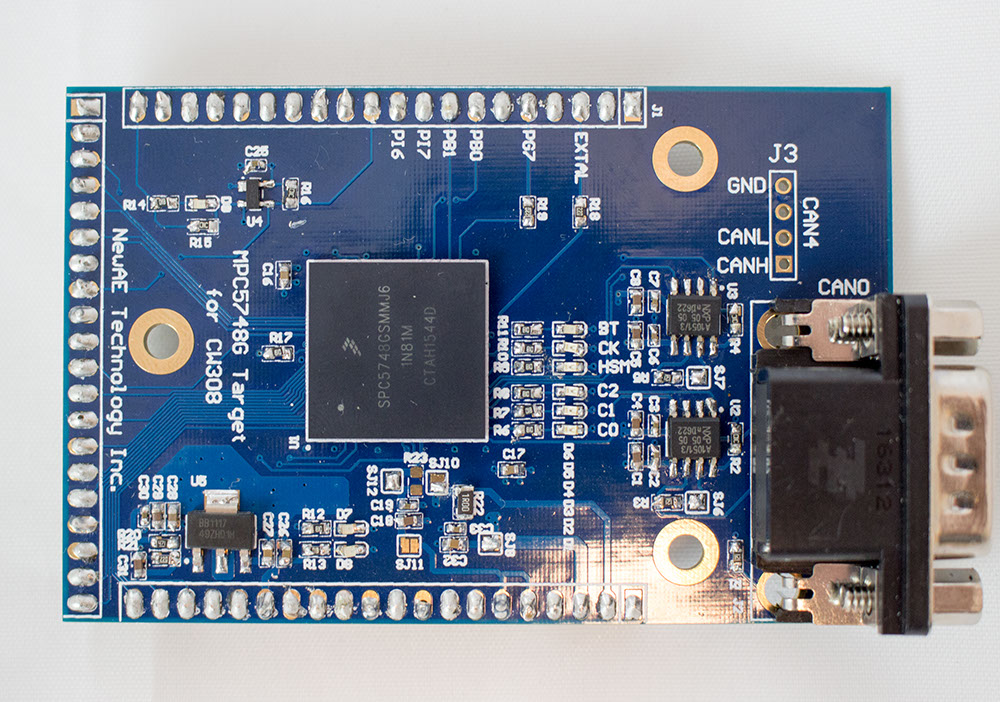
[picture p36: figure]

LED Polarity (all LEDs on PCB)

Solder Jumpers set by stencil

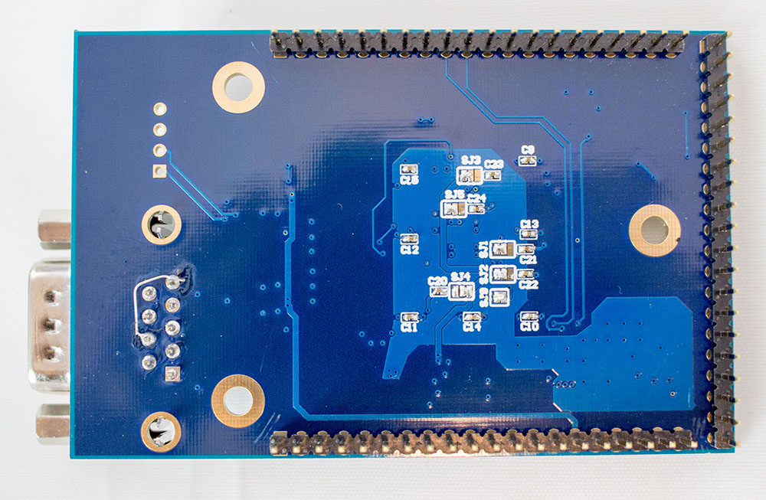
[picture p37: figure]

NOTES

- J1 consists of 3x 20-pin headers mounted on underside of PCB. Headers mount into mating sockets, so must be vertical.
- Various solder jumpers on PCB are set by the provided stencil file (solder paste will short SJ that should be shorted).
- Two additional 4-pin headers not shown are mounted from top side.
- The ‘fix’ on DB9 connector (J2) is not required -02 build.
- U1 has two possible part numbers depending on variant.

NAE-CW308T-MPC5748G-02 Build Notes Date: March 14, 2017

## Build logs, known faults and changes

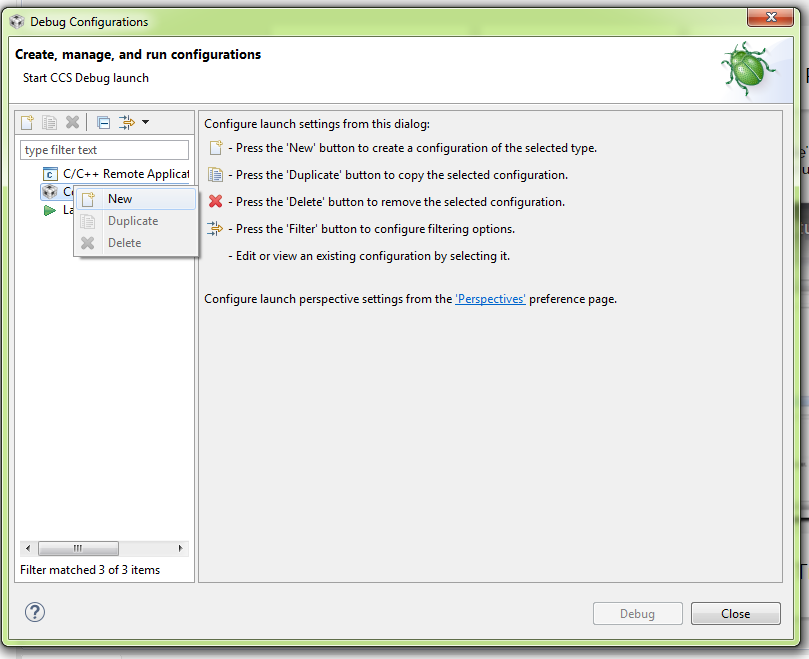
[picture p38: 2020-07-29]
CW308T_CC2538/Images/CCS_Debug_New.png

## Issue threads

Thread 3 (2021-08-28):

CW308T_LPC1343F - missing gerber files

lukaskuzmiak, 2021-08-28:
There seems to be a `.PcbDoc` there but no gerbers. I'm opening this as suggested by @colinoflynn on Twitter.

If the board was untested I will be happy to have these made once gerbers are available and test them out.

colinoflynn, 2021-08-31:
So there was some error in rev 01, I was trying to find an old PCB here but failed. IIRC the boot pin was routed incorrectly, but there has been a rev02 PCB design in there for a while so I believe it was fixed in the design. But I can't find the flywired board here to confirm this.

So I just generated gerbers & committed them. I don't think they have ever been tested, but the hacked PCB here (which just flywired the pin) did work from memory. Unfortunately I can't guarantee much more than that!

Closed 2021-08-31.

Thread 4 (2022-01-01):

CW308T-GENERIC

lukaskuzmiak, 2022-01-01:
Is CW308T-GENERIC opensource? I was going to order some target boards and thought it would be nice to get more prototyping/generic ones but did not find gerbers for it.

Happy New Year!

colinoflynn, 2022-01-01:
Oops! It *should* be... let me fix.

colinoflynn, 2022-01-02:
Added - https://github.com/newaetech/chipwhisperer-target-cw308t/tree/master/CW308T_GENERIC/gerbers along with the altium source!

Closed 2022-01-02.

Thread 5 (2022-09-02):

CW312 target template

lukaskuzmiak, 2022-09-02:
Would it be possible to eventually get a CW312 target template as well? 🙂

Or if there is some description/something to base in on I'd be happy to volunteer to make a KiCad template version as well.

colinoflynn, 2022-09-05:
Yes! It's roughly what's in the Altium source for the current ones, I can make mechanical specs. Unlike the CW308 there is a lot more "room" however - so basically you can expand to an unlimited size beyond the edge connector. One of the ideas of the update was making it easier to work with much larger targets, where the CW308T pins started getting in the way!

Will document what we found as best practices here - note that we've tested this pretty extensively with low-cost PCB runs, where you *don't* do hard edge plating and don't bother with the chamfering. It seems to work just fine (I've even done some test runs with HASL on the fingers instead of ENIG, and even that worked fine).

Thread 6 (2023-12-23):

How to choose the resistor value (RShunt and Rclock) of CW308 STM32L562RET6?

csersoft, 2023-12-23:
In the schematic diagram, only the resistor (RShunt and Rclock) configurations of the F0, F1, F3, and F4 series were found, but the resistor configurations of L4 and L5 were not found. How should I choose the resistor values for the L4 and L5 series?

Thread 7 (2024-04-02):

N76E003 target board

nikitalita, 2024-04-02:
I have the target board for the N76E003 (and other NuMicro 1T 8051 chips) ready to be PRed here:
https://github.com/nikitalita/n76e003-ufo-target-board

However, the board is made in KiCad, and I notice everything here is made in Altium. I don't want to shell out for an Altium license; is it possible to just submit the KiCad files, or would you want to convert this to Altium yourselves?

Below are the pics of the board and the schematics:

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

colinoflynn, 2024-04-02:
Amazing, thanks so much! Please PR as-is, yes the Altium source was a bit of a historical debt rather than something we actively encourage/prefer ;-) Eventually we may try to convert some to KiCad so they can be more easily modified.... for now we're going to be switching going forward on some new projects as we slowly drop Altium ourselves.

Closed 2024-04-02.

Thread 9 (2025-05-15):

CW312T_K82F doesn't show up in the readthedocs

trick2011, 2025-05-15:
The CW312T_K82F doesn't show up in chipwhisperer.readthedocs.io only [CW308T_K82](https://chipwhisperer.readthedocs.io/en/latest/chipwhisperer-target-cw308t/CW308T_K82/README.html) is available.

All CW312T boards are also not in the [Targets page](https://chipwhisperer.readthedocs.io/en/latest/Targets/index.html)

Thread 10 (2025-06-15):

pcb_libraries

tlovenspclsauce, 2025-06-15:
Would it be possible to publish the NewAE_AltimumLib.DBLib? I see the PCB and SCH files but when cloning or modifying the existing boards for other chipsets, the components all refer back to this DB library and it's slightly tedious to go replace all of them.

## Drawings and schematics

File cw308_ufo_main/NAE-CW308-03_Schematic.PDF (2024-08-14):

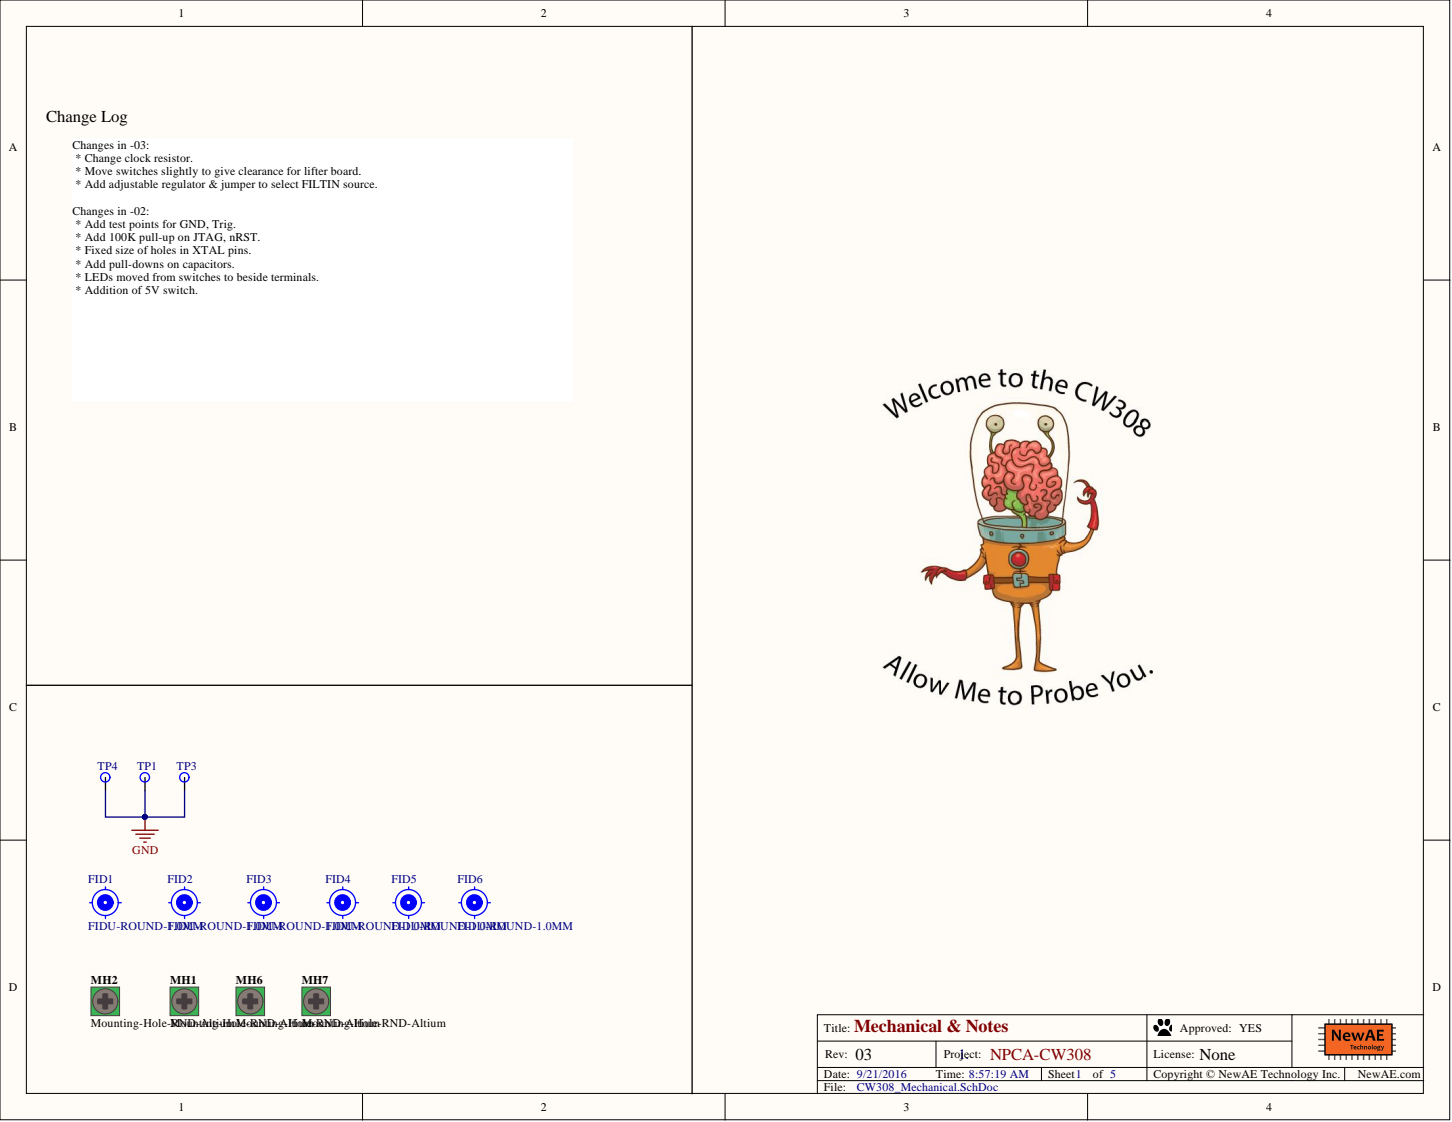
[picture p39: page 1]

Changes in -03:
* Change clock resistor.
* Move switches slightly to give clearance for lifter board.
* Add adjustable regulator & jumper to select FILTIN source.

Changes in -02:
* Add test points for GND, Trig.
* Add 100K pull-up on JTAG, nRST.
* Fixed size of holes in XTAL pins.
* Add pull-downs on capacitors.
* LEDs moved from switches to beside terminals.
* Addition of 5V switch.

Mounting-Hole-RND-Altium

Mechanical & Notes Title: | Approved: YES

Rev: 03 | Project: NPCA-CW308 | License: None

Date: 9/21/2016 Time: 8:57:19 AM | Sheet of

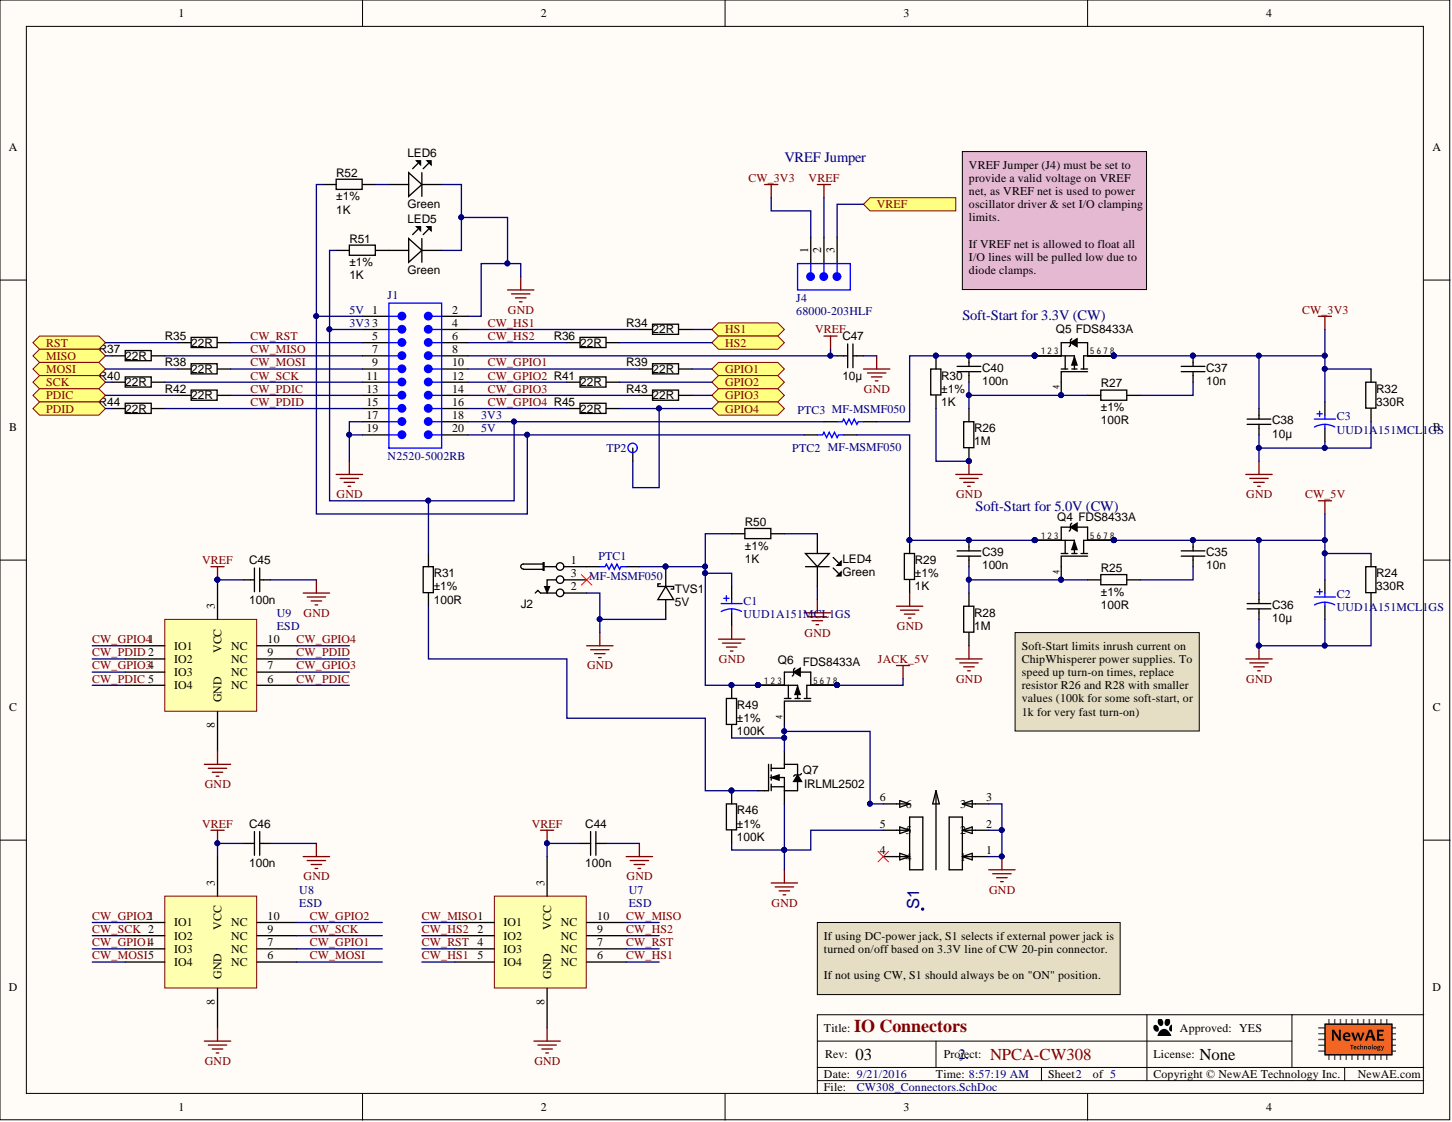
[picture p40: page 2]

provide a valid voltage on VREF
net, as VREF net is used to power
oscillator driver & set I/O clamping
limits.

If VREF net is allowed to float all
I/O lines will be pulled low due to
diode clamps.

Soft-Start for 3.3V (CW)

GND
Soft-Start for 5.0V (CW)

Soft-Start limits inrush current on
ChipWhisperer power supplies. To
speed up turn-on times, replace
resistor R26 and R28 with smaller
values (100k for some soft-start, or
1k for very fast turn-on)

If using DC-power jack, S1 selects if external power jack is
turned on/off based on 3.3V line of CW 20-pin connector.

If not using CW, S1 should always be on "ON" position.

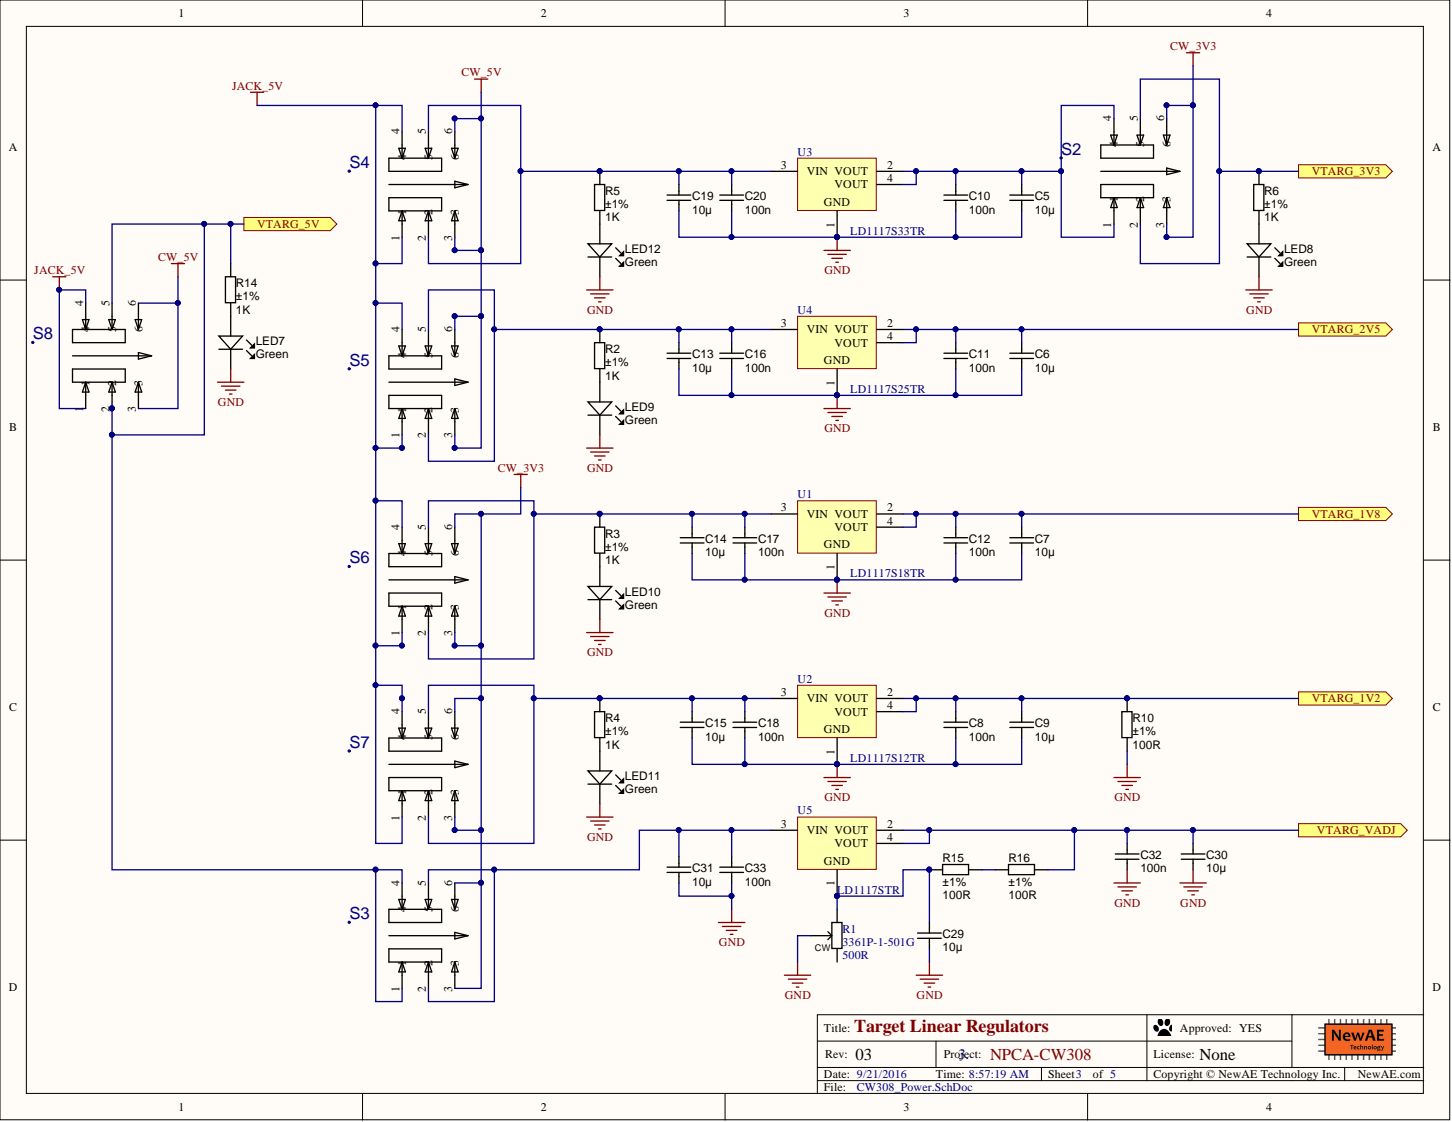
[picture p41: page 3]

T i t le: | A p pro ved : Y E S

Rev : 03 | Project : NPCA-CW308 | L icen se: None

T ime: | Sheet o f | Co p yri g h t © New A E Tech n | o l o g y Inc.

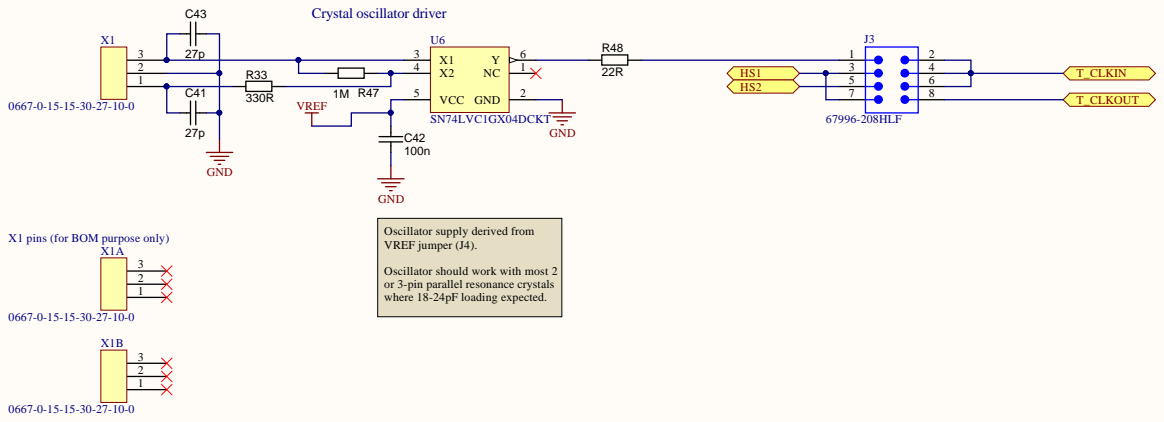
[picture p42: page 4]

Oscillator supply derived from
VREF jumper (J4).

X1 pins (for BOM purpose only)

Oscillator should work with most 2
or 3-pin parallel resonance crystals
where 18-24pF loading expected.

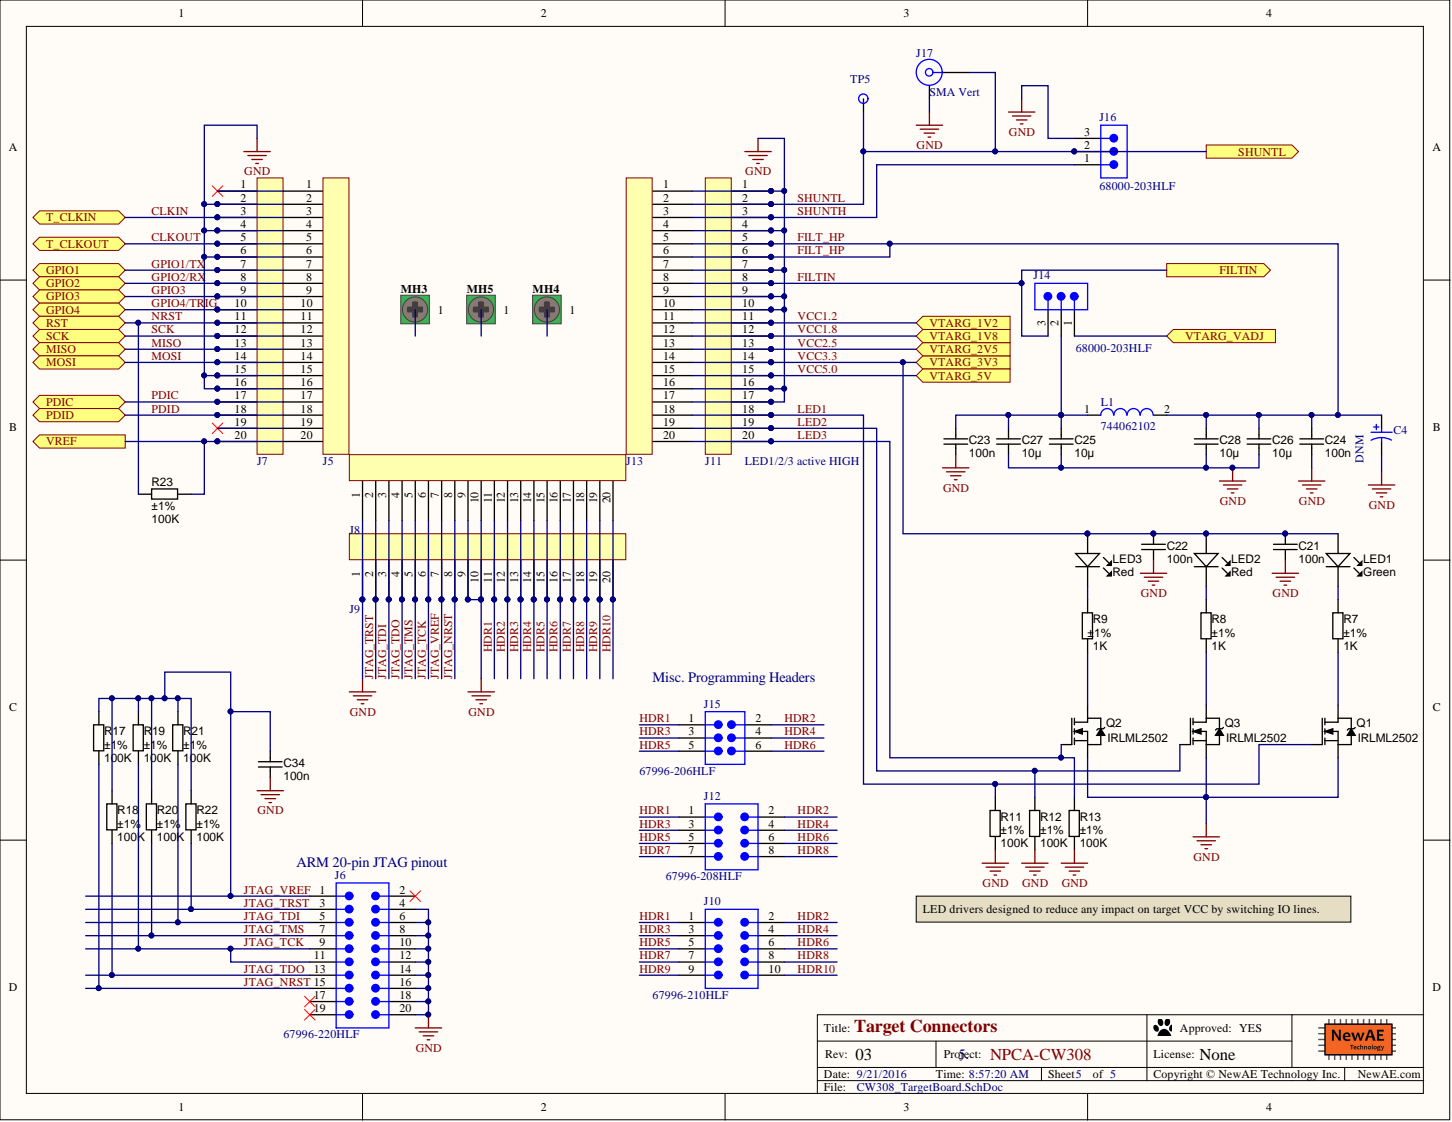
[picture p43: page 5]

9 | 9 | VCC1.2 VTARG_1V2
10 | 10
11 | 11
12 | 12 | VCC1.8
13 | 13 | VCC2.5
14 | 14 | VCC3.3
15 | 15 | VCC5.0

17 | | 17
18 | | 18
19 | 19 LED2
20 | 20 LED3

ARM 20-pin JTAG pinout

LED drivers designed to reduce any impact on target VCC by switching IO lines.

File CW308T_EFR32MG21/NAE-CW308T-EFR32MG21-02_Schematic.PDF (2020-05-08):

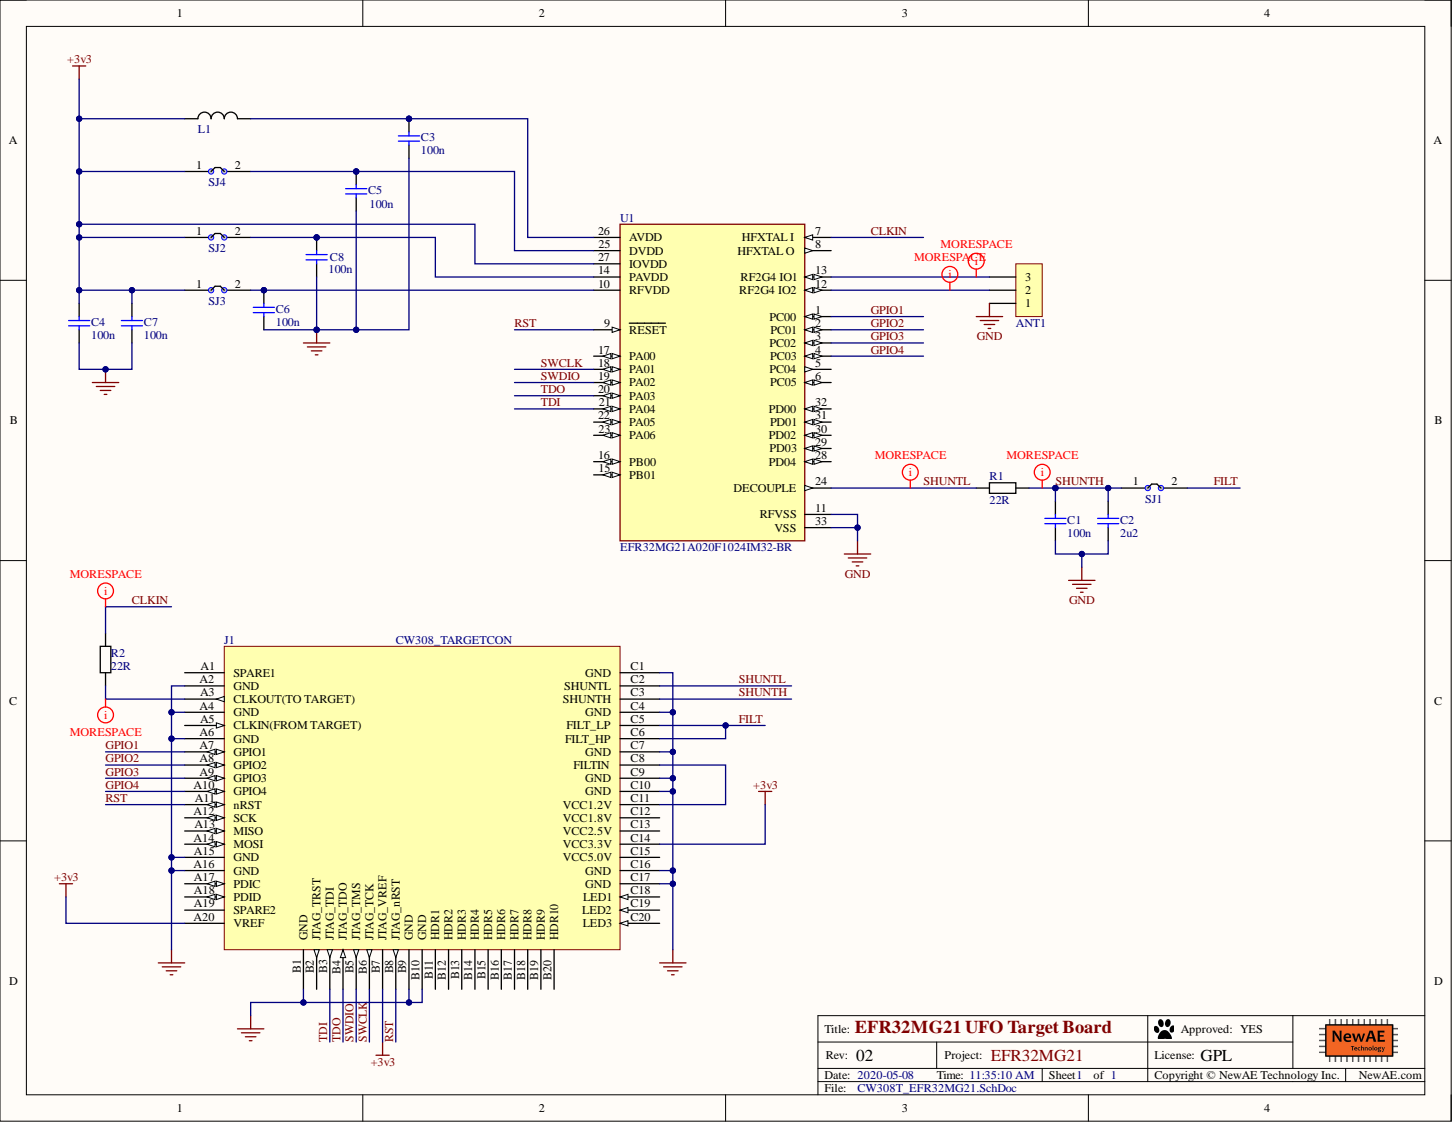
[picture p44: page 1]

DVDD 25

C8 | IOVDD 27

RFVDD 10

C6 | RST | RESET 9

CLKOUT(TO TARGET) A3
GND A4

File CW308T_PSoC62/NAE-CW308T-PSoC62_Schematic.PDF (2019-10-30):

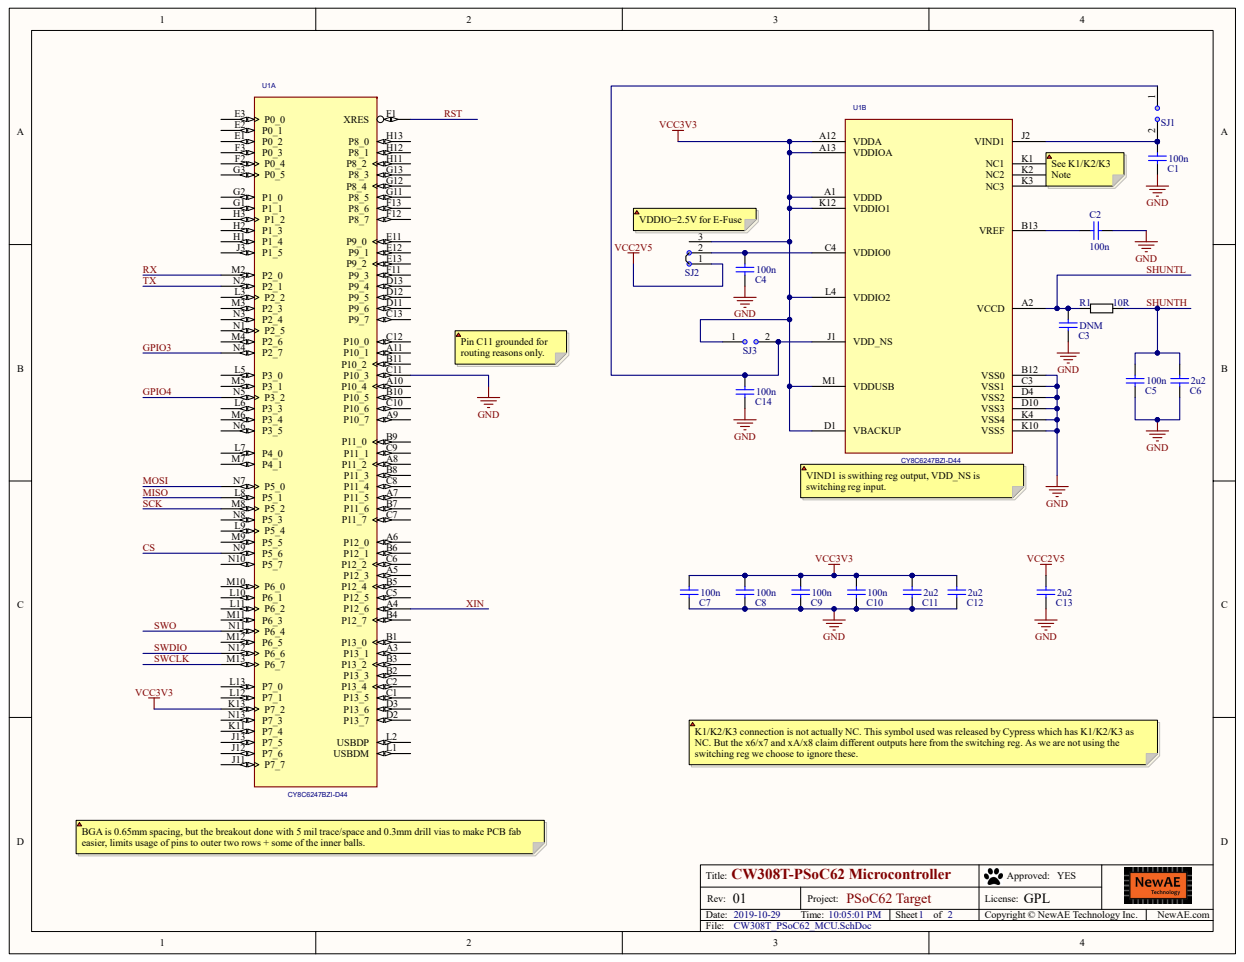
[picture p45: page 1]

VIND1 is swithing reg output, VDD_NS is
switching reg input.

K1/K2/K3 connection is not actually NC. This symbol used was released by Cypress which has K1/K2/K3 as
NC. But the x6/x7 and xA/x8 claim different outputs here from the switching reg. As we are not using the
switching reg we choose to ignore these.

BGA is 0.65mm spacing, but the breakout done with 5 mil trace/space and 0.3mm drill vias to make PCB fab
easier, limits usage of pins to outer two rows + some of the inner balls.

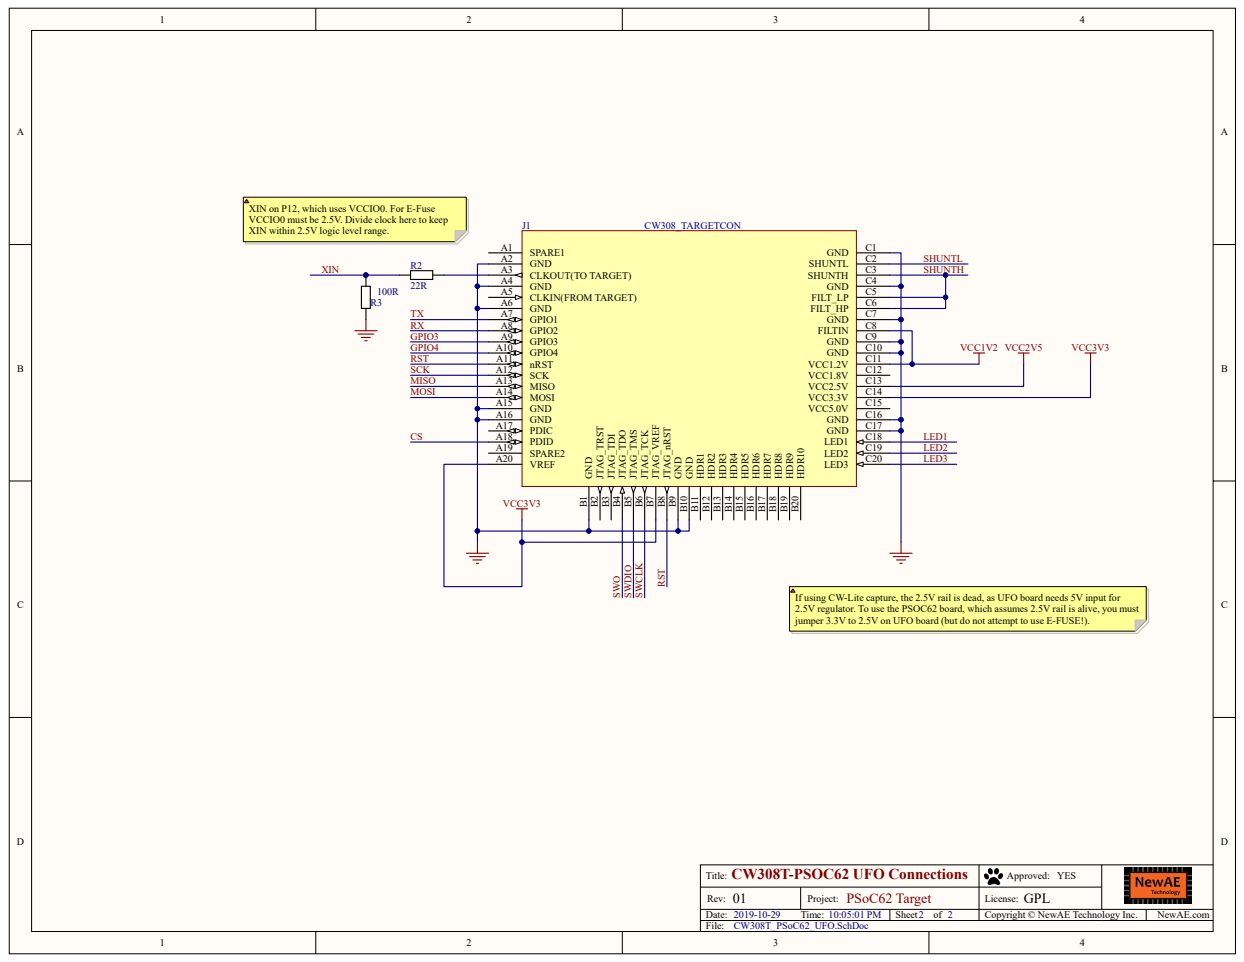
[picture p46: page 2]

XIN on P12, which uses VCCIO0. For E-Fuse
VCCIO0 must be 2.5V. Divide clock here to keep
XIN within 2.5V logic level range.

If using CW-Lite capture, the 2.5V rail is dead, as UFO board needs 5V input for
2.5V regulator. To use the PSOC62 board, which assumes 2.5V rail is alive, you must
jumper 3.3V to 2.5V on UFO board (but do not attempt to use E-FUSE!).

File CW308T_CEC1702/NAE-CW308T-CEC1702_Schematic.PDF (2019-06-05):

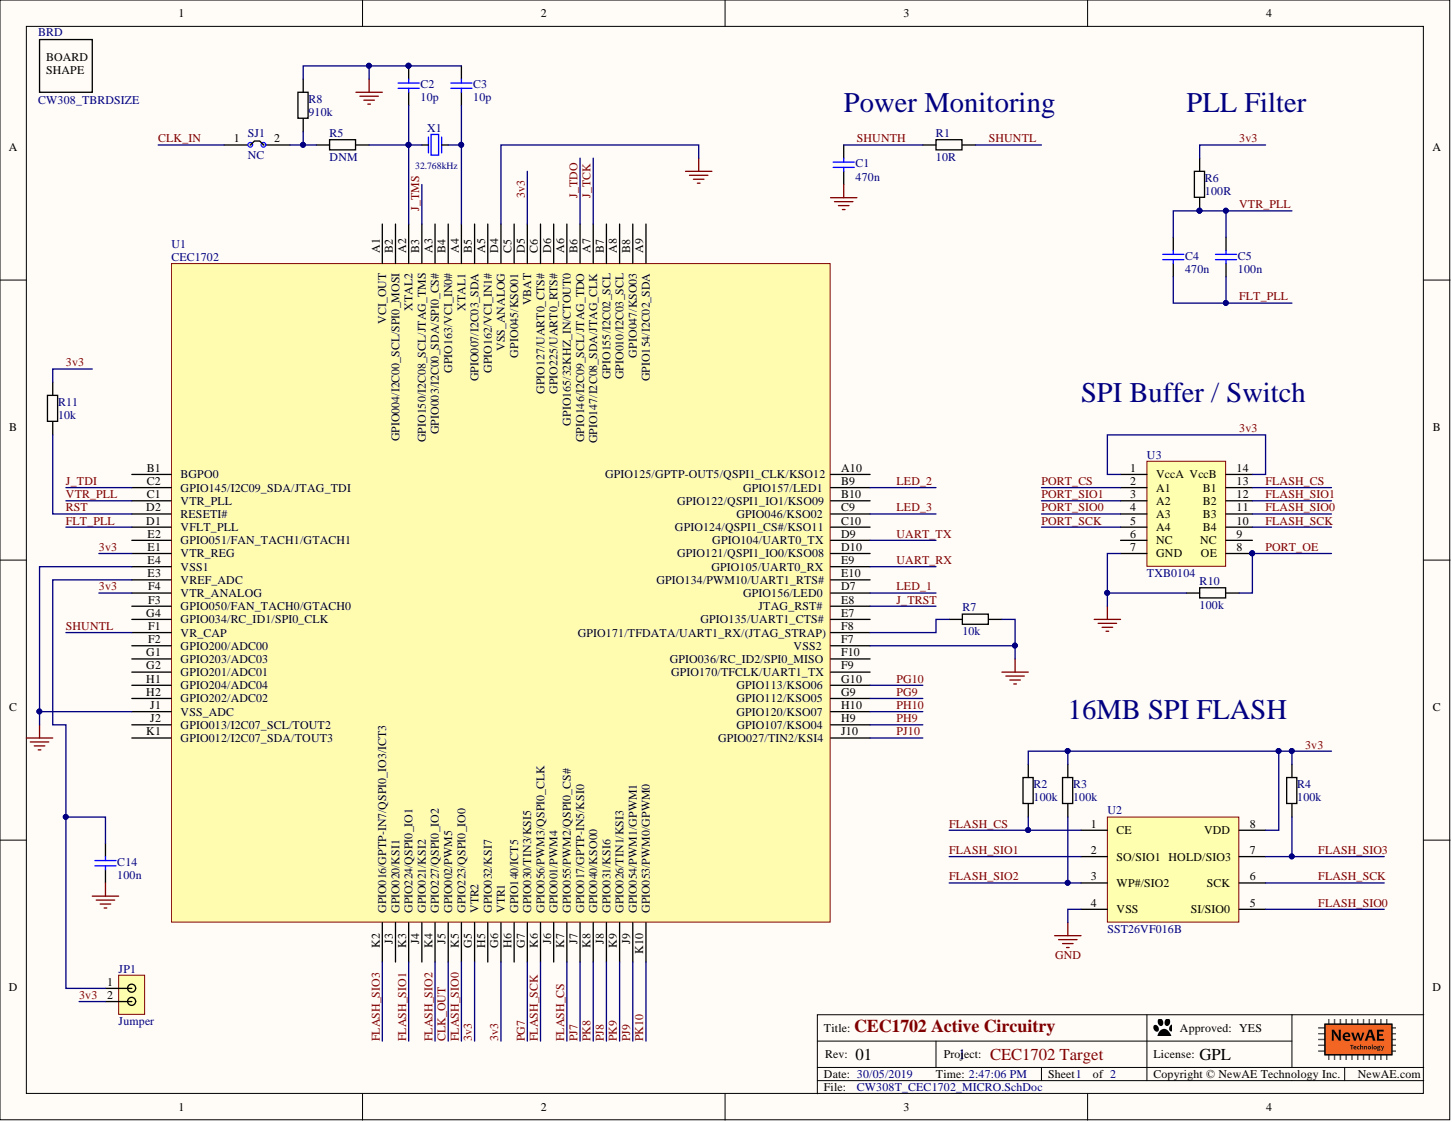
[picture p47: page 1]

CEC1702 Active Circuitry Title: | Approved: YES

Rev: 01 | Project: CEC1702 Target 1 | License: GPL

Date: 30/05/2019 Time: 2:47:06 PM | Sheet 1 of 2

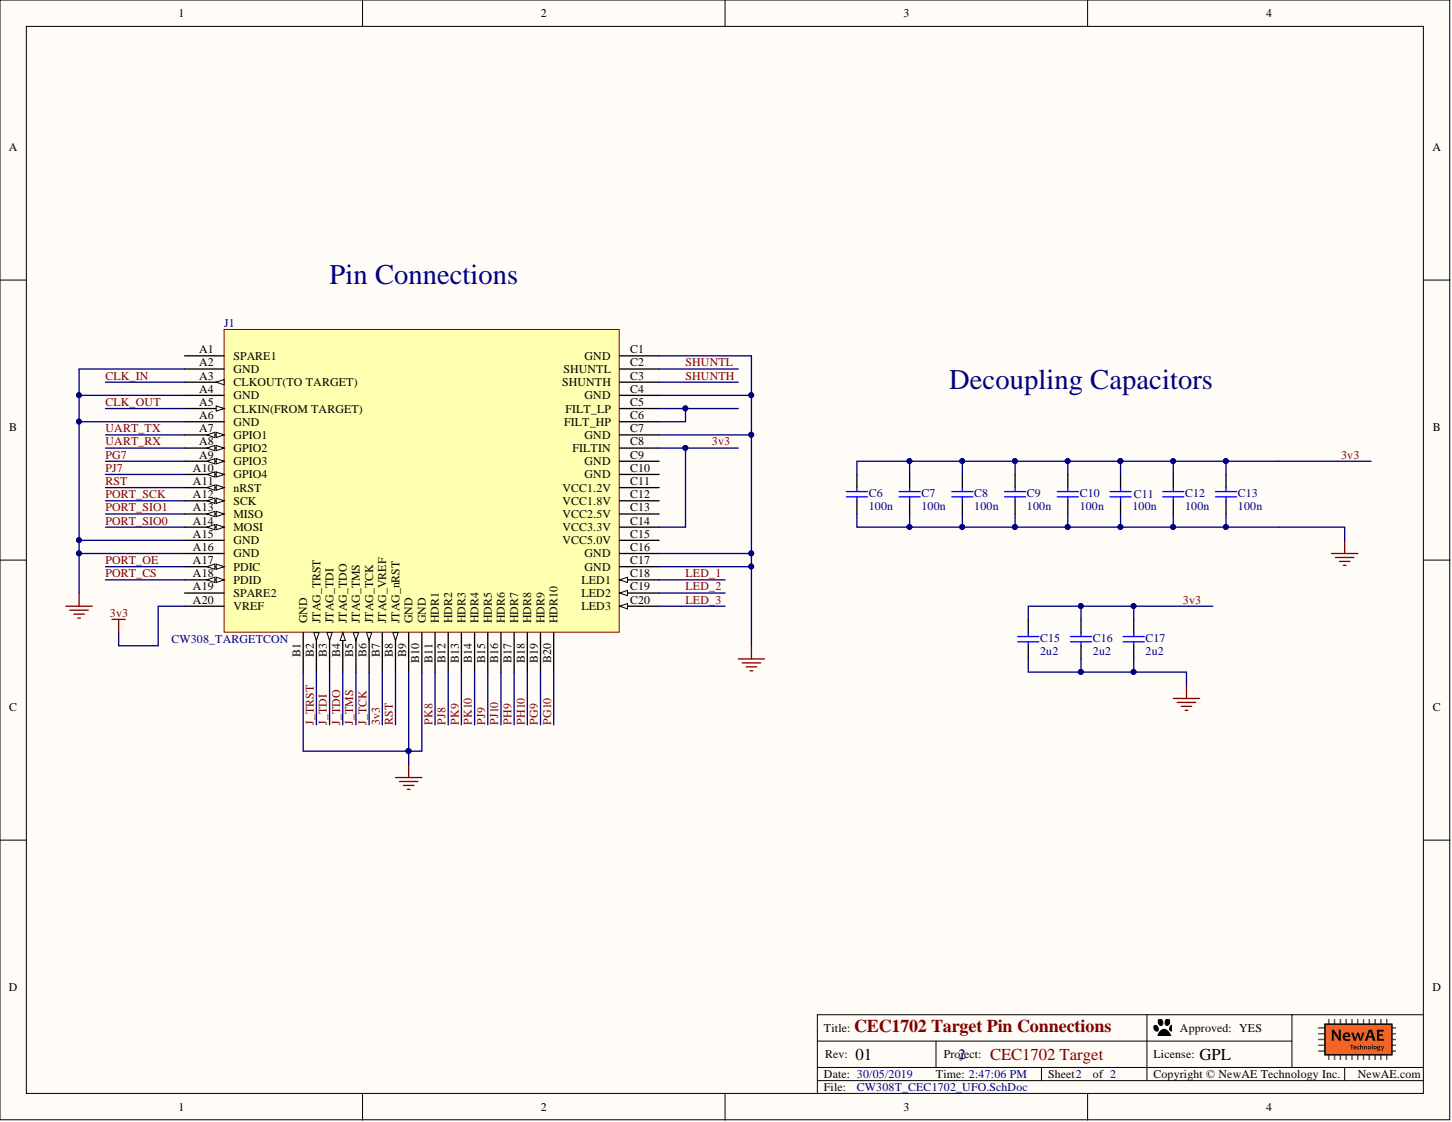
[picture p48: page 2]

CEC 1 7 0 2 Target Pin C onnections T i t le: | A p pro ved : Y E S

Rev : 01 | Project 2 : CEC1702 Target | L icen se: GPL

Date: 3 0 / 0 5 / 2 0 1 9 T ime: 2 : 4 7 : 0 6 PM | Sheet 2 o f 2 | Co p yri g h t © New A E Tech n | o l o g y Inc.

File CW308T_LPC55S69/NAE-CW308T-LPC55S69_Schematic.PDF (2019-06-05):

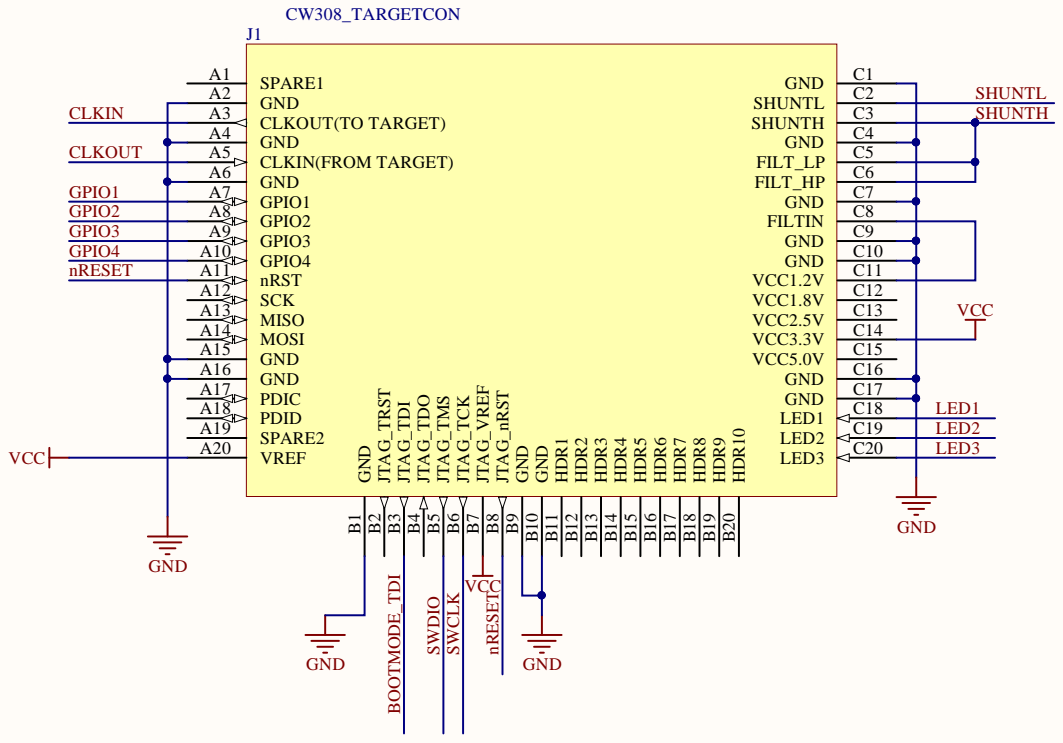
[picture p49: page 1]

UFO Target Title: | Approved: YES

Rev: 03 | Project: LPC55S69 Target | License: GPL

Date: 05/06/2019 Time: 10:23:55 AM | Sheet of

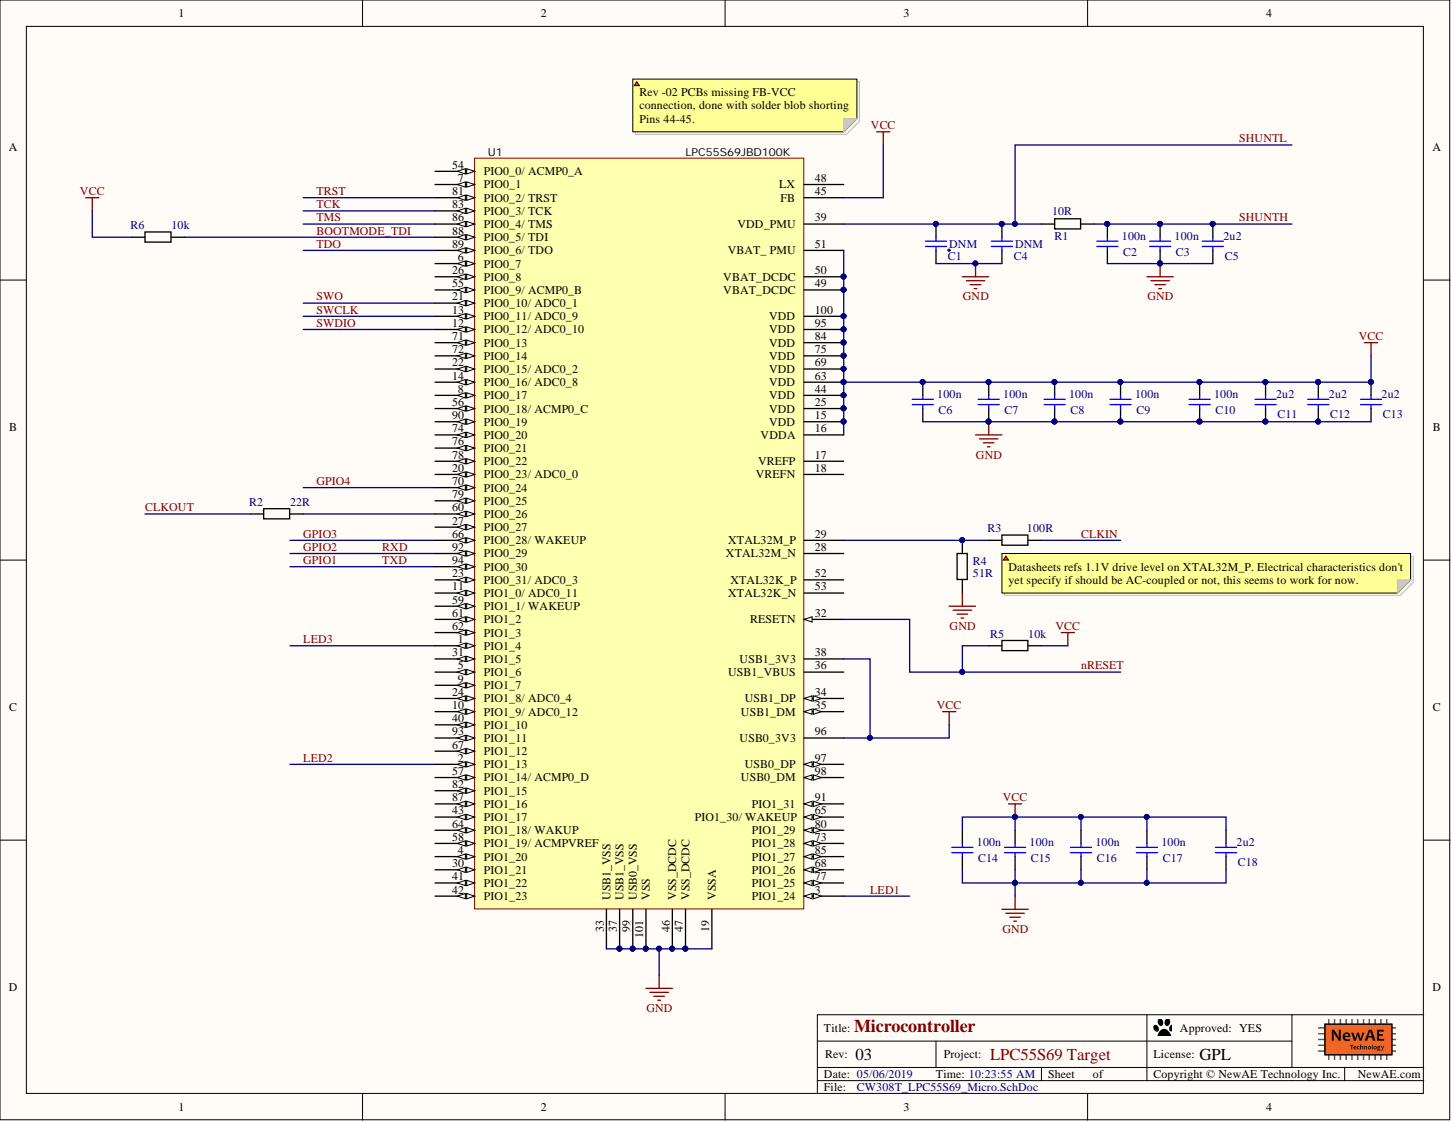
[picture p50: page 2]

Rev -02 PCBs missing FB-VCC
connection, done with solder blob shorting
Pins 44-45.

Datasheets refs 1.1V drive level on XTAL32M_P. Electrical characteristics don't
yet specify if should be AC-coupled or not, this seems to work for now.

Microcontroller Title: | Approved: YES

Rev: 03 | Project: LPC55S69 Target | License: GPL

Date: 05/06/2019 Time: 10:23:55 AM | Sheet of

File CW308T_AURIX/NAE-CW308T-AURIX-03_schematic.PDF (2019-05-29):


P02.8 9 | RST

VCORE | VDD 11

Note that bootstap option for
diabling internal LDO is
unavailable in this package.
LDO must be diabled in
software by configuring the
EVR13CON register

Aurix Target Board Title: | Approved: YES

Rev: 03 | Project: Aurix Target | License: GPL

Date: 29/05/2019 Time: 10:03:44 AM | Sheet of

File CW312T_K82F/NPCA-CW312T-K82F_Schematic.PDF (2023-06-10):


8 9
9 9
3 4


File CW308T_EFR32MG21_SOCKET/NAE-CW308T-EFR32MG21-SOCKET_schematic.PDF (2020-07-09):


DVDD 25

C8 | IOVDD 27

RFVDD 10

C6 | RST | RESET 9

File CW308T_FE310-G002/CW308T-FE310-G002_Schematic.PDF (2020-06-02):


QSPI_DQ2
QSPI_DQ3
QSPI_CS | qspi_cs_0 5


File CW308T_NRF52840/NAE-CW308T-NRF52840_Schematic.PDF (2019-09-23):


Micr ocontr oller T i t le: | A p pro ved : N O

Rev : 03 | Project : nRF52840 UFO Target | L icen se: GPL

Date: 2 0 1 9-0 9-2 3 T ime: 1 0 : 4 0 : 5 4 A M | Sheet o f | Co p yri g h t © New A E Tech n | o l o g y Inc.


UFO Target Title: | Approved: NO

Rev: 03 | Project: nRF52840 UFO Target | License: GPL

Date: 2019-09-23 Time: 10:40:55 AM | Sheet of

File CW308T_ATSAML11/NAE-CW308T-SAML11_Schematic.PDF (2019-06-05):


CW308T-SAML11 Microcontroller Title: | Approved: YES

Rev: 02 | Project: SAML11 Target | License: GPL

Date: 30/05/2019 Time: 2:34:35 PM | Sheet of

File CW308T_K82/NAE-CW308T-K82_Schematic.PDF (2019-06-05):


8 9
9 9
3 4

K8 2 Microcontroller T i t le: | A p pro ved : N O

Rev : 01 | Project : K82 UFO Target | L icen se: GPL

Date: 3 0 / 0 5 / 2 0 1 9 T ime: 3 : 0 3 : 5 9 PM | Sheet o f | Co p yri g h t © New A E Tech n | o l o g y Inc.


CW308 Connections Title: | Approved: NO

Rev: 01 | Project: K82 UFO Target | License: GPL

Date: 30/05/2019 Time: 3:03:59 PM | Sheet of

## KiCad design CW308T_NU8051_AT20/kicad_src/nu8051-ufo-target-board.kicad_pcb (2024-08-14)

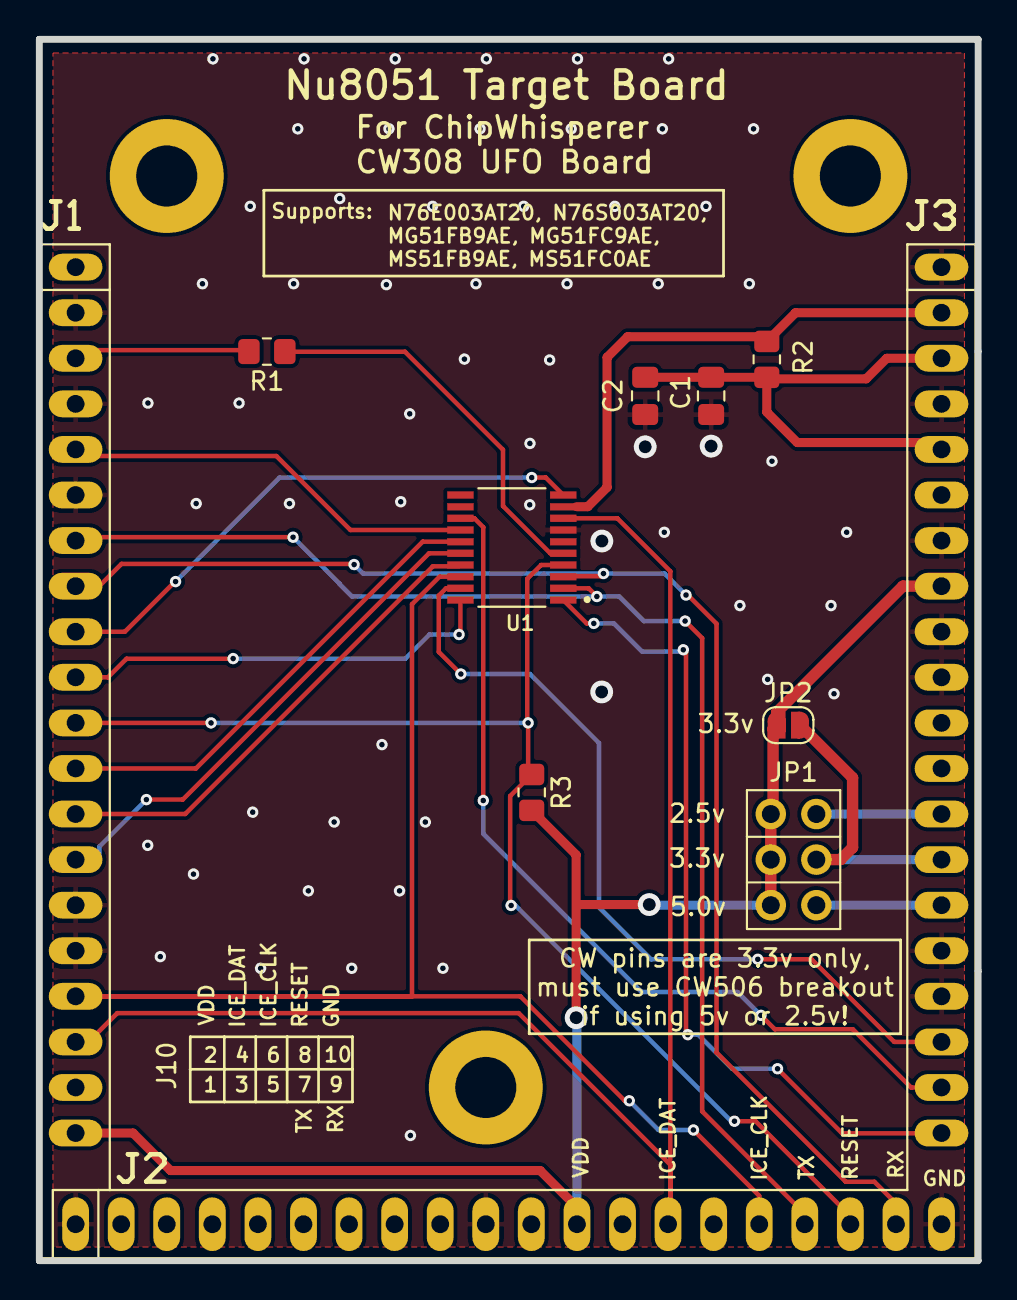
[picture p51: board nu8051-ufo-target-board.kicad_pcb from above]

Board: 2 copper layers, 52.3 x 68.1 mm, 9 parts (0 on the bottom side), 23 nets.

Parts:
C1: 100nF; C_0805_2012Metric_Pad1.18x1.45mm_HandSolder
C2: 2.2uF (OPT); C_0805_2012Metric_Pad1.18x1.45mm_HandSolder
J1: CW308T_CONNBOARD
JP1: Jumper_2_Open; PinHeader_2x03_P2.54mm_Vertical
JP2: SolderJumper_2_Open; SolderJumper-2_P1.3mm_Open_RoundedPad1.0x1.5mm
R1: 100R; R_0805_2012Metric_Pad1.20x1.40mm_HandSolder
R2: 51R; R_0805_2012Metric_Pad1.20x1.40mm_HandSolder
R3: 10K; R_0805_2012Metric_Pad1.20x1.40mm_HandSolder
U1: N76E003AT20; SOP65P640X120-20N

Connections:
+2V5: J1.C13 (VCC2.5V), JP1.2 (B1)
+3.3V: J1.C14 (VCC3.3V), JP1.4 (B2), JP2.2 (B)
+5V: J1.C15 (VCC5.0V), JP1.6 (B3)
CLK: R1.1, U1.5 (P3.0/~INT0/OSCIN/AIN1)
CLKOUT: J1.A5 (CLKIN), U1.14 (P1.1/PWM1/IC1/AIN7/CLO)
GND: C1.2, C2.2, J1.A2 (GND), J1.A4 (GND), J1.A6 (GND), J1.A15 (GND), J1.A16 (GND), J1.B1 (GND), J1.B10 (GND), J1.B20 (HDR10), J1.C1 (GND), J1.C4 (GND), J1.C7 (GND), J1.C9 (GND), J1.C10 (GND), J1.C16 (GND), J1.C17 (GND), U1.7 (GND)
GPI01: J1.A7 (GPIO1), J1.B17 (HDR7), U1.2 (P0.6/TXD/AIN3)
GPI02: J1.A8 (GPIO2), J1.B19 (HDR9), U1.3 (P0.7/RXD/AIN2)
GPI03: J1.A9 (GPIO3), U1.10 (P1.5/PWM5/IC7/~SS)
GPI04: J1.A10 (GPIO4), U1.20 (P0.4/AIN5/STADC/PWM3/IC3)
LED1: J1.C18 (LED1), U1.19 (P0.3/PWM5/IC5/AIN6)
LED2: J1.C19 (LED2), U1.13 (P1.2/PWM0/IC0)
LED3: J1.C20 (LED3), U1.1 (P0.5/PWM2/IC6/T0/AIN4)
MISO: J1.A13 (MISO), U1.17 (P0.1/PWM4/IC4/MISO)
MOSI: J1.A14 (MOSI), U1.16 (P0.0/PWM3/IC3/MOSI/T1)
unnamed: J1.A3 (CLKOUT), R1.2
unnamed: C1.1, C2.1, J1.C3 (SHUNTH), J1.C5 (FILT_LP), R2.2
PDIC: J1.A17 (PDIC), J1.B16 (HDR6), U1.18 (P0.2/ICPCK/OCDCK/RXD_1/[SCL])
PDID: J1.A18 (PDID), J1.B14 (HDR4), U1.8 (P1.6/[SDA]/TXD_1/ICPDA/OCDDA)
RST: J1.A11 (NRST), J1.B18 (HDR8), R3.2, U1.4 (P2.0/~RST)
SCK: J1.A12 (SCK), U1.15 (P1.0/PWM2/IC2/SPCLK)
VBUS: J1.C2 (SHUNTL), R2.1, U1.9 (VDD)
VCC: J1.A20 (VREF), J1.B12 (HDR2), J1.C8 (FILTIN), JP1.1 (A1), JP1.3 (A2), JP1.5 (A3), JP2.1 (A), R3.1

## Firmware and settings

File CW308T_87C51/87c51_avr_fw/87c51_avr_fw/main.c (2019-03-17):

/*
 * main.c
 *
 * Created: 29/07/2016 2:58:13 PM
 * Author : greg
 */ 

#define F_CPU 7384615
//#define F_CPU 4000000
#define UART_BAUD 4800

#include <avr/io.h>
#include <avr/interrupt.h>
#include <avr/sleep.h>
#include <util/delay_basic.h>
#include <util/delay.h>
#include <stdio.h>

#include "uart.h"
#include "utilities.h"
#include "simpleserial.h"
#include "verify.h"


void sleep_avr()
{
	// Go to sleep
	set_sleep_mode(SLEEP_MODE_PWR_DOWN);
	sleep_enable();
	sleep_cpu();
}

int main(void)
{
	// First, check if we're supposed to be asleep
	uint8_t mode_verify = PINE & (1 << PINE2);
	if(!mode_verify)
	{
		sleep_avr();
	}
	
	// Then, we can set up everything else
	utilities_init();
	uart_init(F_CPU/16/UART_BAUD - 1);
	verify_init();
	
	led2_low();
	trigger_low();
		
	target_enable();
	verify_byte(0xFFFF);
	
	sei();

    while (1) 
    {
		// Let the user know we're waiting
		heartbeat_enable();
		
		if(simpleserial_get(2))
		{	
			heartbeat_disable();
			uint8_t* address = simpleserial_getaddress();
			
			uint16_t addr_16 = (address[0] << 8) | (address[1]);
			
			// Verify code at this address
			uint8_t response[1];
			response[0] = verify_byte(addr_16);
			
			simpleserial_put(response, 1);	
		}
    }
}

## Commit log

2019-03-17 Initial commit - add all files (need PDFs still)
    [CW308A_XMEGA.GBL, CW308A_XMEGA.GBO, CW308A_XMEGA.GBP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]
2019-03-17 Update PDF schematics (not all there yet), gerbers (also not all there yet)
    [CW308T_AURIX.SchDoc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]
2019-03-18 Add gerbers for K82
    [CW308T_NRF52840.PrjPcb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]
2019-05-29 Update project files - will do new PCB gerber update as well
    [CW308T_AURIX.PcbDoc, CW308T_AURIX.SchDoc, CW308T_LPC55S69_Main.SchDoc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]
2019-05-29 AURIX: Update to -03 rev, actually works correctly now
    [CW308T_AURIX.GBL, CW308T_AURIX.GBO, CW308T_AURIX.GBP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]
2019-05-29 AURIX: Small updates to project file (version number in parameters wasn't bumped)
    [CW308T_AURIX.PrjPcb]
2019-06-05 -Update targets to reflect PCB release
    -Fix LPC55S69 to disable DC-DC switching reg on Rev -03 PCB and mention mod for -02.
    [CW308T_ATSAML11.PrjPcb, CW308T_ATSAML11.SchDoc, CW308T_LPC55S69_Main.SchDoc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]
2019-07-11 Add PSOC-62 target
    [CW308T_PSoC62.PcbDoc, CW308T_PSoC62.PrjPcb, CW308T_PSoC62_MCU.SchDoc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]
2019-07-30 Add FW310-G002 Target
    [CW308T-FE310-G002-CONN.SchDoc, CW308T-FE310-G002.PcbDoc, CW308T-FE310-G002.PrjPcb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]
2019-09-13 Update nrf board
    [CW308T_NRF52840.GBL, CW308T_NRF52840.GBO, CW308T_NRF52840.GBP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]
2019-09-23 FE310 board update - will update gerbers etc as well
    [CW308T-FE310-G002.PcbDoc, CW308T-FE310-G002.SchDoc]
2019-09-23 Update nRF board layout (rev 03(
    [CW308T_NRF52840.PcbDoc]
2019-09-23 nRF board - rev 03 schematic had incorrect rev # marked. Fix a few minor errors on schematic (left-over flying leads etc)
    [CW308T_NRF52840.PcbDoc, CW308T_NRF52840.PrjPcb, NRF52840_MICRO.SchDoc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]
2019-10-30 Add PSOC62 ordering info, updated schematic now that approved
    [CW308T_PSoC62_MCU.SchDoc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]
2020-01-20 Update NRF PCB
    [CW308T_NRF52840.GBL, CW308T_NRF52840.GBO, CW308T_NRF52840.GBP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]
2020-01-20 Add imxrt1062 board (NOT TESTED)
    [CW308T_IMXRT1062_PANEL.PcbDoc, CW308_IMXRT1062.PrjPcb, CW308_IMXRT1062.SchDoc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]
2020-01-20 Add MPC5Y Target (MPC5777C)
    [CW308T_SPC56.PcbDoc, CW308T_SPC5676R.PrjPcb, mpc56_can.SchDoc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]
2020-01-31 Updates to RT1062, NRF, PSOC projects.
    [CW308T_NRF52840.PcbDoc, CW308T_PSoC62.PrjPcb, CW308_IMXRT1062.SchDoc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]
2020-02-12 Update IMXRT1062 board (need PDF)
    [CW308_IMXRT1062.PrjPcb, CW308_IMXRT1062.SchDoc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]
2020-02-12 Update RT1062 with PDF sch + correct name of sheets
    [CW308_IMXRT1062.PrjPcb, CW308_IMXRT1062.SchDoc, CW308_IMXRT1062_UFO.SchDoc]
2020-03-20 Update MP5Y for final release
    [CW308T_SPC56.PcbDoc, CW308T_SPC5676R.PrjPcb, NAE-CW308T-MPC5748G-02B BOM.xls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]
2020-04-22 Update schematic to match final boards on FE310-G002
    [CW308T-FE310-G002.PcbDoc, CW308T-FE310-G002.SchDoc]
2020-05-03 Add EFR32MG21 Target
    [CW308T_EFR32MG21.PcbDoc, CW308T_EFR32MG21.PrjPcb, CW308T_EFR32MG21.SchDoc]
2020-05-03 Update FE310 silkscreen
    [CW308T-FE310-G002-CONN.SchDoc, CW308T-FE310-G002.PrjPcb]
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2020-05-08 EFR32MG21: Update to -02 version
    [CW308T_EFR32MG21.PcbDoc, CW308T_EFR32MG21.PrjPcb, CW308T_EFR32MG21.SchDoc]
2020-05-09 EFM32GG11 project file sync
    [CW308T_EMF32GG11.PrjPcb]
2020-05-09 Add EFR32MG21 socket project (not tested on HW yet)
    [CW308T_EFR32MG21_SOCKET.PcbDoc, CW308T_EFR32MG21_SOCKET.PrjPcb, CW308T_EFR32MG21_SOCKET.SchDoc]
2020-05-20 Move around files into altium_src directory as needed
    [CW308T_EFR32MG21_SOCKET.PcbDoc, CW308T_EFR32MG21_SOCKET.PrjPcb, CW308T_EFR32MG21_SOCKET.SchDoc]
2020-06-02 FE310-g002: Change clock resistor values to 100R/330R for better highs-peed
    [CW308T-FE310-G002-CONN.SchDoc, CW308T-FE310-G002.PcbDoc, CW308T-FE310-G002.SchDoc]
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2020-07-01 Update PCB to have only chip on 1 side
    [CW308T_STM32F415_CSP.PcbDoc, CW308T_STM32F415_CSP.PcbLib, CW308T_STM32F415_CSP.PrjPcb]
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2020-11-12 HW: STM32F4 WLCSP fix pinout of SMD pins
    [CW308T_STM32F415_CSP.PcbDoc, CW308T_STM32F415_CSP.PcbLib, CW308T_STM32F415_CSP.PrjPcb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]
2020-11-12 HW: Move STM32F415_WLCSP version into correct folder, include gerber outputs
    [CW308T_STM32415_PANEL.GBL, CW308T_STM32415_PANEL.GBO, CW308T_STM32415_PANEL.GBP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]
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2021-08-31 Add gerbers for LPC1343
    [CW308T_LPC1343.GBL, CW308T_LPC1343.GBO, CW308T_LPC1343.GBP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]
2021-09-01 Fix missing GM1 info (was missing on pcbdoc)
    [CW308T_LPC1343.GBL, CW308T_LPC1343.GBO, CW308T_LPC1343.GBP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]
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2022-01-24 Add iCE40 for CW312
    [CW312T_ICE40UP.GBL, CW312T_ICE40UP.GBO, CW312T_ICE40UP.GBP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]
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2022-02-05 Add CW308 ice40 proto
    [ICE40_Target.PrjPcb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]
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2022-10-06 Add SAM4S production version
    [NPCA-CW312T-ATSAM4S_REV03.xls, PnP-NPCA-CW312T-03.csv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]
2022-10-06 Add production for ice40 target
    [CW312T_ICE40UP.PcbDoc, CW312T_ICE40UP.PrjPcb, CW312_ICE40UP_ice40.SchDoc]
2022-11-20 Add CW312 Template for targets
    [CW312T_Template_AltiumProject.PrjPcb, cw312_template.PcbDoc, cw312_template_cardedge.SchDoc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]
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2022-12-09 Add K82F design (proto)
    [CW312_K82.PrjPcb, CW312_K82.SchDoc, CW312_K82_CardEdge.SchDoc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]
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2023-01-09 Fix STM32F-SOCKET board
    [CW308T_STM32FSOCKET.GBL, CW308T_STM32FSOCKET.GBO, CW308T_STM32FSOCKET.GBP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]
2023-01-15 Add XC7A35T Target for CW312
    [CW312T_XC7A35T_AltiumProject.PrjPcb, cw312_xc7A35t_fpga_io1.SchDoc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]
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2023-01-15 Updated ice40 gerbers (not changed, just filesystem sync)
    [CW312T_ICE40UP.GBL, CW312T_ICE40UP.GBO, CW312T_ICE40UP.GBP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]
2023-01-15 Add updated CW308-CW312 files
    [cw312_sam4s.SchDoc]
2023-03-01 Add files for rev02 of XC7A35T CW312 Target
    [CW312T_XC7A35T_AltiumProject.PrjPcb, cw312_xc7A35t_fpga_io1.SchDoc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]
2023-03-03 Add Rev3 of PCB
    [CW312T_XC7A35T_AltiumProject.PrjPcb, cw312_xc7a35t_cardedge.SchDoc]
2023-03-04 Update for rev03, fix title sheets, add gerbers
    [cw312_xc7A35t_fpga_io1.SchDoc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]
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2023-03-27 Update for DIP switches
    [CW312T_XC7A35T_AltiumProject.PrjPcb, cw312_xc7A35t_fpga_io1.SchDoc, cw312_xc7a35t_fpga_cfg.SchDoc]
2023-03-27 Add 04 rev of XC7A35T
    [BOM-CW312T_XC7A35T_AltiumProject.xlsx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]
2023-03-27 Sync more XC7A35T files
    [CW312T_XC7A35T_AltiumProject.PrjPcb]
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2023-06-10 Add updated K82 design files
    [CW312_K82.PrjPcb, CW312_K82.SchDoc, CW312_K82_CardEdge.SchDoc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]
2024-04-02 Add nu8051 target board
    [BOM-nu8051-ufo-target-board.csv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]
2024-08-09 Initial RP2350 design files
    [RP2350_CWHusky.SchDoc, RP2350_MCU.SchDoc, RP2350_Power.SchDoc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]
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2024-09-27 Add Fx PCB files, update LPC55s6 programming instructions
    [CW308T_STM32F415.PrjPcb]
2025-01-28 Add errata to stm32f
2025-02-19 Spell check, fix links.
    NOTE: links corrected so that they work on rtfm.newae.com. Currently
    can't have them be right in both places; picked rtfm.newae.com since
    that's what users are more likely to use. This should be fixed when
    documentation sites are revamped.
